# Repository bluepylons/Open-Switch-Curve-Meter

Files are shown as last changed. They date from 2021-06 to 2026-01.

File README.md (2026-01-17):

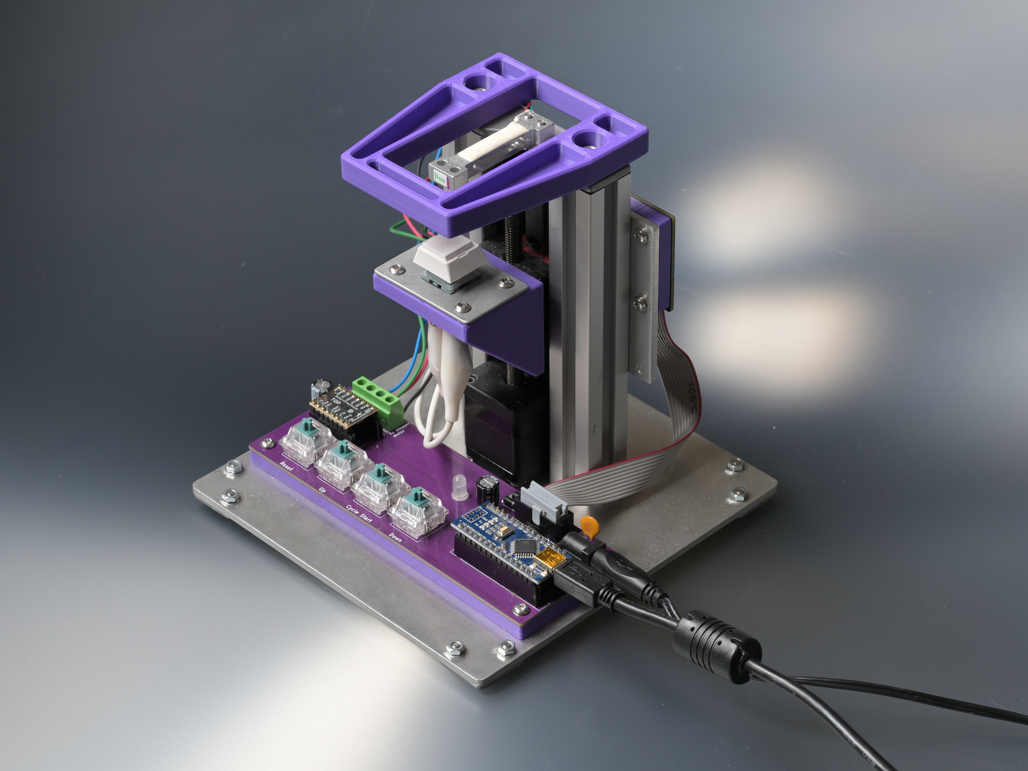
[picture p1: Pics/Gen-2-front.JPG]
Gen 2 Prototype


# About 
This is an open-source, low-cost measurement device for generating force curve measurements for MX-style switches. There are two versions - a much older Gen 1 and a newer Gen 2 design.  Force curves of various switches I've measured are in the Force curve measurements\ directory. Detailed documentation for Gen 2 is in progress and will be available [here](https://github.com/bluepylons/Open-Switch-Curve-Meter/blob/main/Gen%202%20Design/README.md).

This was designed specifically for MX switches to simplify the design and make everything cheaper and more compact, and since most of the switches I am curious about (as well as almost all new switches released today) use the MX form factor. With different switch holders it can hold other discrete switches - it was used to measure a Futaba switch, and could theoretically be used to measure Alps and other discrete swithces as well. This is not as versatile as force-curve testers built around a test stand (like [the one Haata built](https://deskthority.net/viewtopic.php?t=15133)) and can't test arbitrary keyboards like that one, but it's much cheaper to build (I spent about $200 building this, and in theory this is buildable for ~$100 if one foregoes the custom PCB and order the parts from China).

This project is licensed under the CERN OHL-S (strongly reciprocal) license for the hardware designs and the software. This is a share-alike license, and if you modify the project files you are required to also open-source your modifications. 

The force curve graphs themselves - the .ODS spreadsheets and the .PNG images of the graphs in the Force curve measurements\ folder - are licensed under [Creative Commons CC-BY 4.0](https://creativecommons.org/licenses/by/4.0/deed.en). 

# The key parts
* A linear stage. I designed around [this inexpensive $55 linear stage off Amazon](https://www.amazon.com/Sliding-Precision-Stepper-T-Shaped-Electric/dp/B07QBCG9YC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). You can find what appear to be identical units [on Aliexpress](https://www.aliexpress.com/item/4001272086575.html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,searchweb201602_,searchweb201603_) and elsewhere for less (if you get them from Aliexpress, make sure you buy the model with 1mm pitch (lead) on the leadscrew). Gen 2 will use the same linear stage. 
* A stepper motor. The stepper motor serves two purposes - it moves the linear stage, and also keeps track of position to plot the X-axis of the force curve. Stepper motors, as long as they aren't stalled or skip steps, move a given amount based on the number of step commands sent, and lets me forego having to directly measure position. Instead, I can just count the number of steps sent to the stepper motor, since I know how much the stepper motor will move for a given number of steps. I used the included stepper motor in the linear stage above, which moves 1.8° per step (200 steps per full rotation). Combined with the 1mm lead leadscrew on the linear stage, a single step (without microstepping) moves the switch 0.005mm. 
* A stepper motor driver. I used a Trinamic TMC2209 on Gen 1, and a Trinamic TMC2208 module on Gen 2. Communication occurs using rudimentary STEP/DIR control.  
* A load cell, to measure the force on the switch. I used [this 500g load cell](https://www.sparkfun.com/products/14728) from Sparkfun. It can be found on Aliexpress for slightly less. 
* A load cell amplifier and  ADC for reading the load cell and converting the readinging into a digital signal that can be easily read by the microcontroller. I used Avia's HX711 on both Gen 1 and Gen 2 as [Sparkfun made a module for it](https://www.sparkfun.com/products/13879), and there is an Arduino library available for it. Gen 2 has provisions for SPI and I2C for potential future upgrades with faster and more expensive ADCs (e.g. Analog Devices AD7730).
* A microcontroller. I used an Arduino Nano clone on Gen 1 and Gen 2 as I had one lying around and it's straightforward to write code for. My initial plans for Gen 2 involved using [Adafruit's Feather RP2040](https://www.adafruit.com/product/4884), though I have not had time to learn its programming language yet so I decided to spin another PCB for an Arduino Nano. 
* Software to transfer the information over to a computer. Right now, I use an Arduino 1.8.19's serial monitor to transfer the information over from the Arduino Nano clone. It's copied into a .csv file using Notepad. Cleanup of the data can be done either manually in a spreadsheet program (I use LibreOffice Calc), or can be done using [a Python script I wrote up](https://github.com/bluepylons/Open-Switch-Curve-Meter/tree/main/Processing-Python-script). Plotting is currently done with Libreoffice Calc.

There is also an RGBLED for status indication, and MX switches (2 on Gen 1, 4 on Gen 2) for control. 

The CAD was done in Alibre Atom3D. STEP files are provided. 

Gen 1 and Gen 2 both have custom PCBs, designed in KiCAD and fabbed by JLCPCB. You will need KiCAD to open the files. In theory, a PCB is not necessary - you can build this on perfboard, as off-the-shelf HX711 modules are available from [Sparkfun](https://www.sparkfun.com/products/13879) and elsewhere, and you can steper motor drivers [on breadboard-friendly breakout board](https://www.digikey.com/en/products/detail/trinamic-motion-control-gmbh/TMC2209-SILENTSTEPSTICK/10232488). However, it makes things a lot neater. 

The HX711 is powered off the microcontroller's 5V supply. The stepper motor is powered off a separate external 12V power supply.

# To do list (Gen 2)

* Documentation
	* Just like, everything
	* I'll make a video of me operating the force curve meter at some pointed
	* Write a guide on how to build one of these using off-the-shelf HX711 load cell amplifier and stepper motor modules. The PCB was done mostly for my own convenience, and it's possible to do it using off-the-shelf modules and a breadboard, though it's somewhat messier wiring wise. 
	
* Hardware
	* (eventually) Design a 3D-printed case for the PCB so that it's not exposed

* Firmware
	* Gen 2's RGBLED does not changes states like I expect to at the end of the run, so I need to debug this
	* (eventually) Write a more user-friendly UI for processing the data (the current workflow, which involves a lot of spreadsheets and copy/pasting data from Arduino Serial Monitor for both calibration and measurement, is tedious)

* Possible long-term improvements:
	* Better hosting of graphs - possibly moving off Github
		* There's something slowly in the works with various other people that currently possess force curve meters, but it will be some time before it will be up
		* We'd want something more interactive such as Plotly (which no longer takes new uploads), and something that can allow for easy comparisons between switches (e.g. overlaying graphs)
	* Some way to correct for temperature-induced drift on the load cell or amp that isn't just calibrating frequently 
		* I'm fairly annoyed by how much the load cell readings drift with temperature (simply opening a window often forces me to recalibrate), and I am considering adding additional load cell modules solely to do temperature correction (you can cancel out the temperature-dependent terms in the load cell equation if you use multiple identical load cells)/strain gauges, or doing temperature measurements and using a look up table to apply corrections or something. 
	* Possibly move away from the HX711	
		* There's a lot of sample variation among HX711's I've encountered, with some having a lot of drift and others mostly working fine. 
	
# Gen 1 Errata
* I mistakenly connected Pin 1 and Pin 2 on the Arduino on the PCB - those are the TX/RX lines, and I learned that having those connected interferes with communications between the Arduino and your computer,  and may lead to failures when uploading sketches and trying to use Serial Monitor. These lines were originally intended for uART communication with the TMC2209, but I decided to just use DIR/STEP control as it's easier to write the code. Either cut the headers off the Arduino, or do not install those pins on the socket on the PCB. 

# Thanks yous: 
* The Switchmodder [subreddit](https://www.reddit.com/r/switchmodders/) and [Discord](https://discord.gg/xnSUeETRTf)
* Nebulant and xyz for advice
* Romly, for [posting photos of their tester](https://twitter.com/Romly/status/1358983963377688579)  
* Haata, for his [incredibly useful writeup](https://deskthority.net/viewtopic.php?t=15133) on building his switch tester. 
* Gondolindrim and the [Acheron Project](http://acheronproject.com/), as I use their hotswap PCB footprint and the 3D model of the MX switch. Their open-source projects have also been very helpful for me getting into keyboard design. 
* Thank you to the following people for sending me switches to make curves of:
	* Slowshi 
	* Window Dump
	* mfchill
	* Clark
	* Aiwanei 
	* ChromePcok
	* Deadeye 
	* [Rebult Keyboards](https://www.rebultkeyboards.com/)
	* [Dangkeebs](https://dangkeebs.com/)
	* [Moyu.studio](https://moyustudio.cn/)
	* [Adobau Labs](https://adobaulabs.com/)
	* [Prevail Key Co.](https://prevailkeyco.com/)
	* Mechanicalbionicle
	* Nick7790
	* [JLabs](https://jlabs.co/)
	* Laika
	* notdoctorq
	* [Switch Oddities](https://switchoddities.com/)
	
# Links to other people with force curve meter designs and data:

* Ruddy, who's affiliated with [GeekBoards.ru](https://geekboards.ru/), independently developed a similar force curve meter and open-sourced his design on Github [here](https://github.com/geekboards/switch-force-tester). His measurements are [here](https://github.com/geekboards/switch-force-tester/tree/main/python-app/results)

* HaaTa, who founded [Input Club](https://input.club/), and well known for his force curve measurements. His design is on Github [here](https://github.com/kiibohd/force) and described on Deskthority [here](https://deskthority.net/viewtopic.php?f=62&start=&t=15133), and results are on Plotly [here](https://chart-studio.plotly.com/~haata#/)

* Nebulant and ManOfInterests also possess force curve meters, though I am not aware of any centralized location they publish their measurements. You can find their graphs on their Instagrams, across various Discord servers, Twitter, and on Keebtalk. 

* Romly built a force curve meter over in Japan. [Details here](https://romly.com/blog/c99_jikunohakari/).

* Theremingoat has a force curve meter and now has a [massive respository](https://github.com/ThereminGoat/force-curves).

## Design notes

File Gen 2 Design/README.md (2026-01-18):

# Work In Progress

**Order parts at your own risk. These files are provided as-is, and I am not responsible for any losses, harm, or damage incurred by following this guide, by ordering parts, by using the files provided, by using the resultant parts or assembled devices, or from any mistakes or errors in the files, ordering guide, or resultant parts.**

# Gen 2 
Gen 2 Prototype
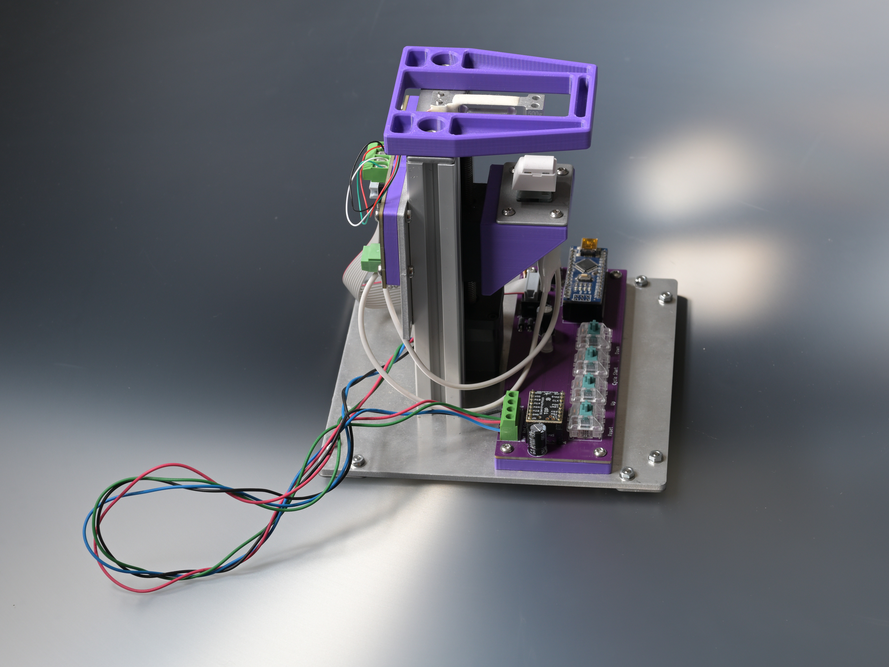
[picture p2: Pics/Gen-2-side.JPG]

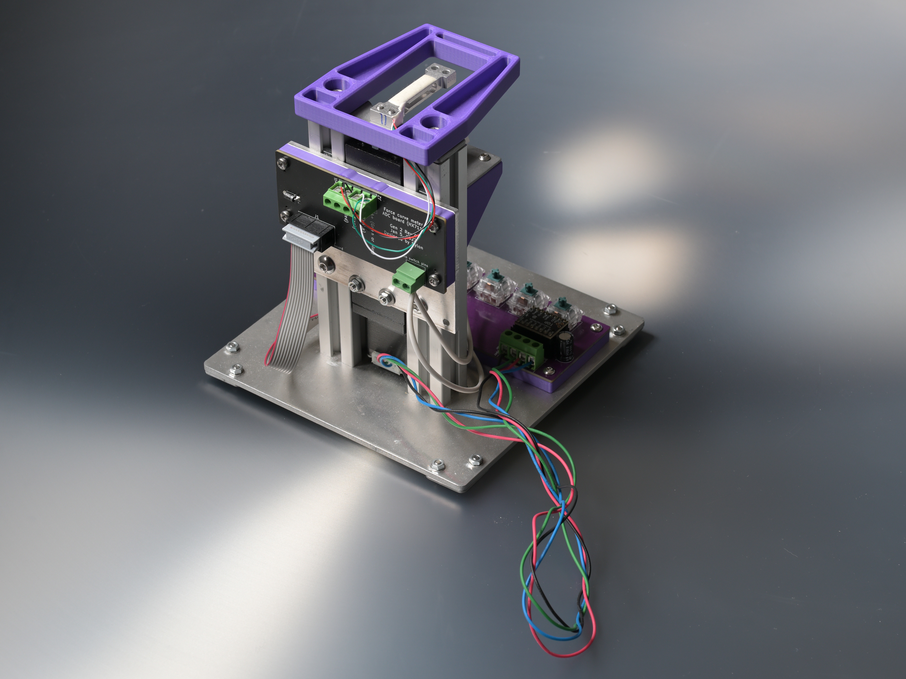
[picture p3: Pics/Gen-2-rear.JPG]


Due to the general jankiness of Gen 1, I decided to do a much neater redesign for Gen 2 back in 2021. I initially thought about [running a group buy](https://geekhack.org/index.php?topic=115453.0), though life has gotten in the way of that. I finally had some time to pick this project back up in late 2025, and am currently documenting the Gen 2 design to the point it can be easily replicated by other people. This document is very much a work in progress, though I have built and operated Gen 2. 

Mechanical CAD is done in [Alibre Atom3D](https://www.alibre.com/atom3d/), and the PCB files are done using KiCAD V9.

# ORDERING GUIDE

# Mechanicals

## Laser cut metal parts

The following parts are laser-cut out of metal. DXFs are provided [here](https://github.com/bluepylons/Open-Switch-Curve-Meter/tree/main/Gen%202%20Design/Mechanical%20files/Laser%20cut). STEP files are provided as well.

| Part name | Material thickness | Quantity |
| --- | --- | --- |
| Baseplate-stand | 3mm-3.2mm (0.118-125") | 1 |
| Bumpon-holder | 1.5mm-1.6mm (0.059-0.063") | 4 |
| Load-cell-mounting-plate | 3mm-3.2mm (0.118-125") | 1 |
| Switch-plate | 1.5mm-1.6mm (0.059-0.063") | 1 |
| Vertical plate | 3mm-3.2mm (0.118-0.125") | 1 |

Aluminum is generally recommended for most of the parts, though other metals (steel, brass, etc.) can work. For the baseplate stand, steel, brass, or stainless steel may be useful as the additional weight can provide more stability. All the parts on the ones I have built are cut out of aluminum 6061-T6.

Aluminum or plain steel are usually the cheapest materials. Note that steel may corrode or rust without treatment (e.g. painting, powder coating). 

In the US, I recommend [Sendcutsend](https://sendcutsend.com/). In the EU, [Laserboost](https://www.laserboost.com/) is a good source. 

For Sendcutsend, deburring is recommended, though it still tends to leave a sharp edge and may require manual deburring afterwards (with a deburring tool such as [this](https://www.mcmaster.com/4289A71/)). [Tumbling](https://sendcutsend.com/services/tumbling/) is recommended for eligible parts as it softens the edges.

## T-slotted extrusions and hardware 

I use Misumi 80/20-style extrusions, though tther brands of 20mm 80/20-style T-slotted extrusions likely work. The extrusions are tapped M5x0.8 on each end (Misumi will do this for you; the part number specifies it). However, if you have the tools you can tap it yourself to save money; you can order HFS5-2020-132 if you want to tap it yourself.

Note that nuts for other 2020 (such as McMaster or actual 80/20(R) hardware) are often incompatible as the slot opening on Misumi extrusions is a bit smaller. Be aware of this if ordering fasteners. 

| Misumi Part Number | Description | Quantity |
| --- | --- | --- |
| HFS5-2020-132-TPW | Extrusion | 2 |
| HNTAP5-5 | M5 nuts | 4 |

## 3D-printed pieces
The following parts are 3D-printed. STLs are available [here](https://github.com/bluepylons/Open-Switch-Curve-Meter/tree/main/Gen%202%20Design/Mechanical%20files/3DP).

| Part name | Quantity |
| ---  | --- |
| Switch mounting bracket | 1 |
| load-cell protection bracket | 1 |
| ADC-PCB-spacer | 1 |
| Main-PCB-spacer | 1 |

I have generally printed these out of PETG with a 0.2mm layer height, though other materials such as ABS and PLA are likely fine. 

## Linear actuator 

The design uses a cheap Chinese 50mm linear actuator with a 1mm pitch leadscrew. There's no exact part number for this. I ordered [this one](https://www.amazon.com/Sliding-Precision-Stepper-T-Shaped-Electric/dp/B07QBCG9YC/ref=sr_1_5?th=1) off Amazon; it is no longer available. [This](https://www.amazon.com/Linear-Actuator-Stepper-Milling-Machine/dp/B07K7FWDZJ/ref=sr_1_8?th=1) likely works as a substitute, though the counterbored mounting hole positions for the overall unit is slightly different (55mm instead of 56mm), though I have slotted the mounting holes on Vertical plate to accommodate 54-56mm. 

## Hardware

The following fasteners are needed:

| Description | Quantity | McMaster-Carr part number | Notes | 
| --- | --- | --- | --- |
| M3x5 ISO 14583 Torx 10 screw | 16 | 90362A112 | ISO 7380 button-head (McMaster 90991A111) would also work | 
| M3x8 screw (ISO 7380 Torx T10 used) | 4 | 90991A111 | Pretty much any head type works as a substitute |
| M3x10 ISO 7380 Torx T10 screw | 12 | 90991A111 | |
| M3x10 ISO 4762 socket head cap screw | 6 | 91292A113 | | 
| M3 DIN 125 washer | 16 | 91292A113 | |
| M3 DIN 934 zinc-plated hex nut | 16 | 91292A113 | Zinc-plated instead of stainless to prevent galling |
| M3x6 4.5-4.8mm hex Female-Female standoff | 8 | 95947A002 | Cheaper on Digi-key |
| M5x8 ISO 7380 hex socket screw | 4 | 94500A230 | McMaster 92095A207	also works but larger package size |  
| M5x12 ISO 7380 hex socket screw | 4 | 92095A210 | Longer lengths (up to 16mm) would also work | 

The following other hardware are needed:

| Description | Quantity | Notes | 
| --- | --- | --- |
| 3M SJ-5003 bumpons (or equivalent) | 4 | Available in different colors |

# PCB 

There are two PCBs, the ADC board and the Main board. The ADC board has SMT components that JLCPCB can place, while the Main board is through hole. While the project was originally going to use an Adafruit Feather RP2040 for the controller, I later switched back to using an Arduino Nano clone so I could re-use the code from Gen 1. 

The PCB can be ordered off JLCPCB using the manufacturing files provided here.

## ADC board

The following additional through-hole parts are needed:

| Reference designators | Part description | Manufacturer | Part number | Quantity | Notes | 
| ---  | --- | --- | --- | --- | --- |
| J1 | 10-pin shrouded connector | CNC Tech | 3020-10-0100-00 | 1 | | 
| J2 | 4-pin terminal block | Würth | 691137710004 | 1 | |
| J3 | 2-pin terminal block | Würth | 691137710002 | 1 | |

D2 can be left unpopulated if D1 is populated,  but Littelfuse P4KE6.8A can be used if not (if JLCPCB is out of stock of D1, for instance)

HX711 pitfalls

## Main board

The main board can be ordered as a bare PCB, which has additional through-hole parts that need to be soldered or installed on. These parts can be sourced from Digikey, Mouser, or your electronic parts distributor of choice.

| Reference designators | Part description | Manufacturer | Part number | Quantity | Notes | 
| ---  | --- | --- | --- | --- | --- |
| A2 | 2.54mm 15-pin female socket | Sullins | PPPC151LFBN-RC  | 2 | You can also cut down a longer socket |
| A2 | Arduino Nano or clone | Arduino | Nano | 1 | Do not use the Arduino Nano Every or ESP32 versions | 
| C1, C3 | 100uF 63V capacitor | Nichicon | UVY1J101MPD1TD2 | 2 | 63V rating is overkill, but I had some lying around |
| D1, D3-D5 | 5.8V TVS diode DO-204AL | Littelfuse | P4KE6.8A | 4 | |
| F1 | 16V 2A polyfuse | Bel Fuse | 0ZRN0200FF1E | 1 | |
| J1 | 5.5x2.5mm barrel jack | Kycon | KLDX-0202-B | 1 | |
| J2 | 10-pin shrouded connector | CNC Tech | 3020-10-0100-00 | 1 | |
| J8 | 4-pin terminal block | Würth | 691137710004 | 1 | |
| LED1 | 5mm through-hole RGBLED | Adafruit | 1938 | 1 | |
| U2 | 2.54mm 8-pin female socket  | Würth | 61300811821 | 2 | You can also cut down a longer socket |
| U2 | TMC2208 SilentStepStick | Watterott | 20170003-002 | 1 | TMC2209 also works |
| SW1-SW4 | Cherry MX-compatible switch | Any | Your favorite | 4 | |

# Electrical parts

You will need the following electrical parts as well:

| Part description | Manufacturer | Part number | Quantity | Notes | 
| --- | --- | --- | --- | --- |
| 500gf TAL221 load cell | Sparkfun | 14728 | 1 | Can also be found on Aliexpress | 
| 10-pin ribbon cable | Assmann WSW  | H3CCH-1006G-ND  | 1 | |
| 12V 2A power supply 5.5x2.5mm barrel jack, center positivee  | EDATEC | ED-PSU1202-US | 1 | Easily substituted; I use the power supply for an external hard drive |
| Alligator clip cable | Adafruit | 1008 | 1 | Easily substituted |

# Other parts

A 100g calibration weight is used to calibrate the load cell. These can easily be bought off Amazon or other places for fairly little money.

# OPERATING PROCEDURE

## Software Needed
* [Arduino IDE](https://www.arduino.cc/en/software)
* Python 3 (Jupyter Notebook) - this can be installed via a package like the [Anaconda Distribution](https://www.anaconda.com/products/distribution) of Python 3
* Libreoffice Calc
* MS Paint

## Calibration

## Measurement

## Data processing
### Automated using Python
### Manual

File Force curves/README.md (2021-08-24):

Here are the force curves I have so far. This page is frequently updated. The force curves here (the PNG and .ods files) are licensed under the [Creative Commons 4.0 license](https://creativecommons.org/licenses/by/4.0/). 

If you don't know how to read a force curve, [ThereminGoat has a good intro article](https://www.theremingoat.com/blog/a-beginners-guide-to-force-curves). 

I am planning a reorganization of this page soon, as it is getting quite long now. Until then - Ctrl-F is probably the best way to navigate this.

# Stock Switches

AEBoards Naevy R1.5 (missing contact):
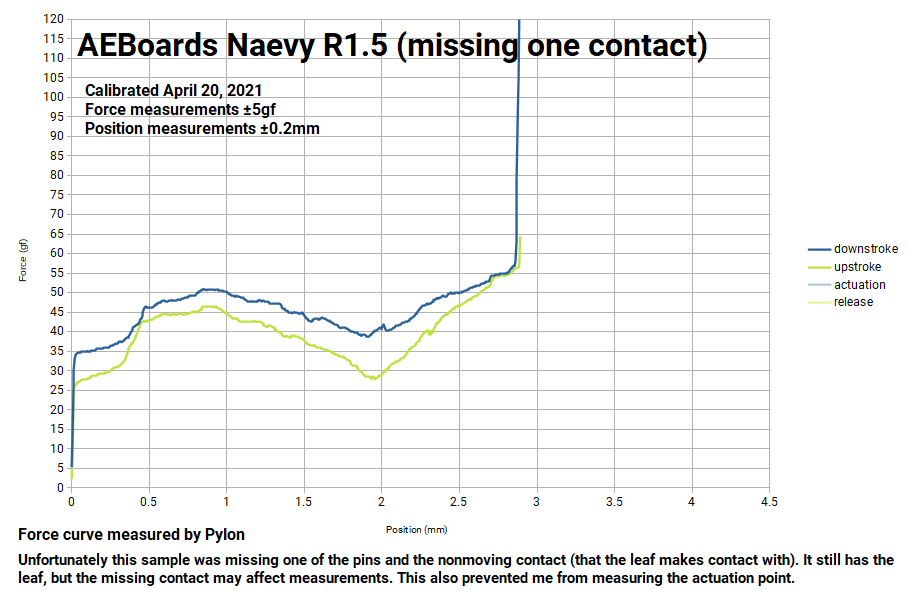
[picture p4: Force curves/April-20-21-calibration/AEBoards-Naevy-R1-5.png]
Naevy R1.5


Akko x KTT CS Ocean Blue:
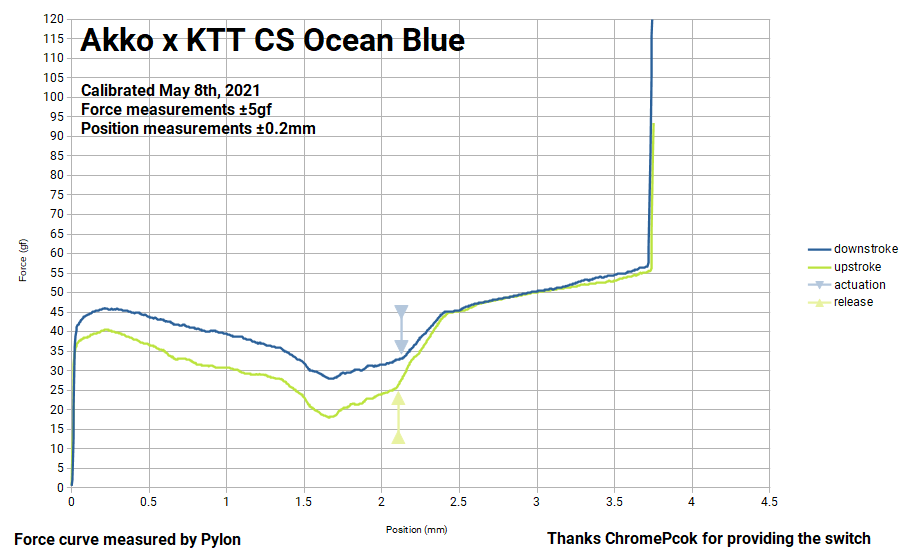
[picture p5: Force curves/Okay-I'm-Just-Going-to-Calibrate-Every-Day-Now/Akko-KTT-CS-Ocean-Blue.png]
Akko Ocean Blue


Alphakeys Dusk Panda:
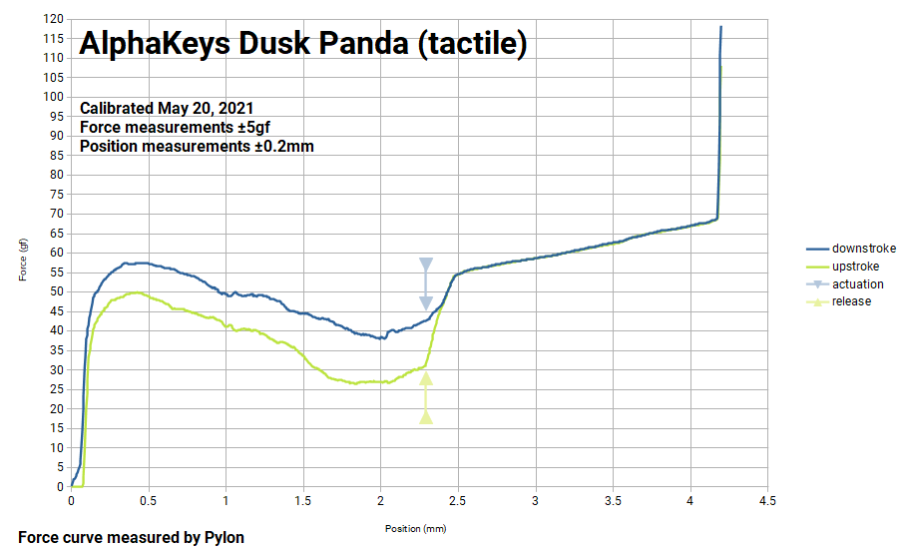
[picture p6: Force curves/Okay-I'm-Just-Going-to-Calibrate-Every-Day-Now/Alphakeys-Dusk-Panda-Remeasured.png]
Alphakeys Dusk Panda


C3 Equalz x JWK Kiwi:                             
Kiwi

Durock (JWK) Koala (T1) 67gf:
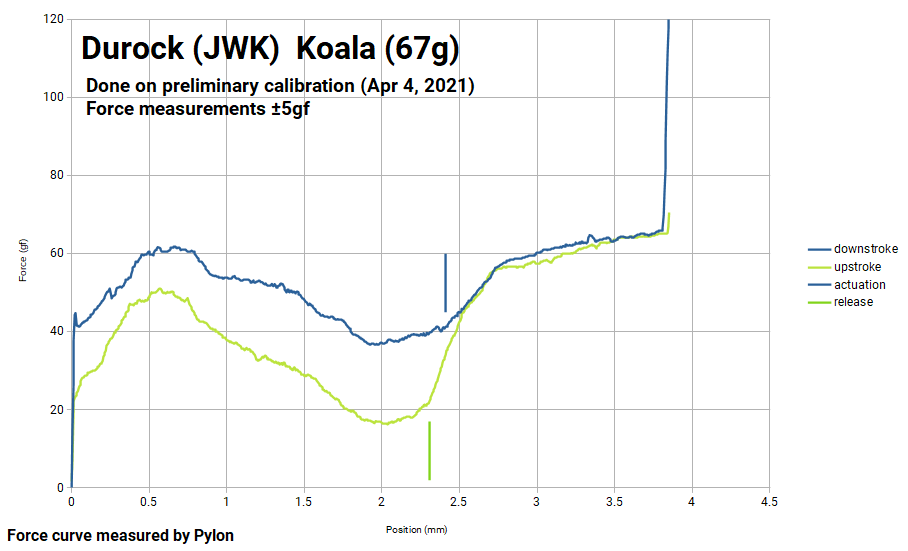
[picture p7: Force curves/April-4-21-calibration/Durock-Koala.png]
Durock Koala


Durock (JWK) Medium Tactile:
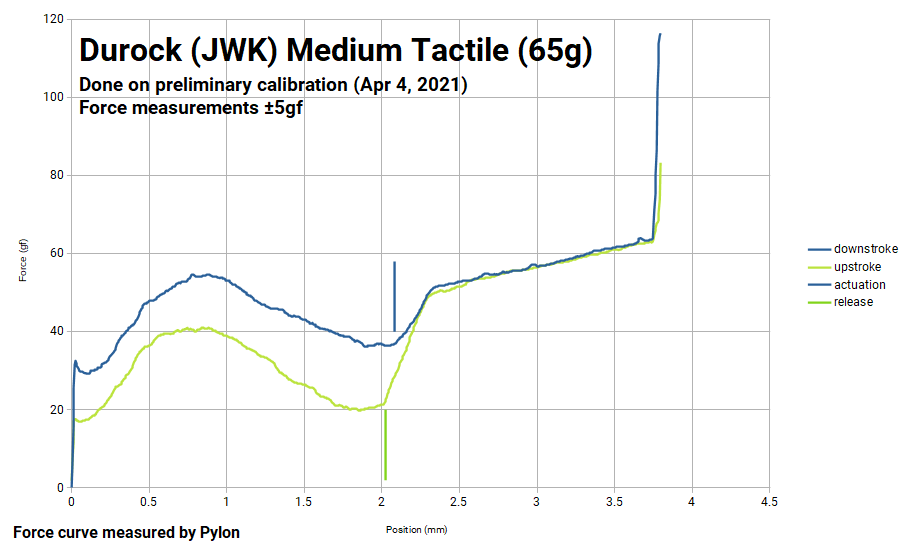
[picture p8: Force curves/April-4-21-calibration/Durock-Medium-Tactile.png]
Durock Medium Tactile


Durock (JWK) Shrimp (Silent T1):
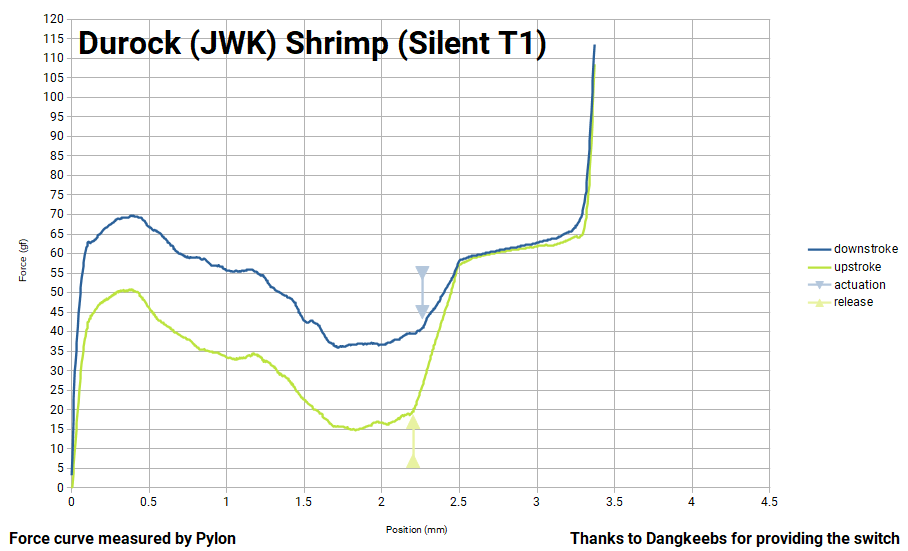
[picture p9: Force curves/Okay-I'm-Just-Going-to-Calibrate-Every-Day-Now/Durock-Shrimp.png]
Durock Shrimp


Durock (JWK) Sunflower (POM T1):
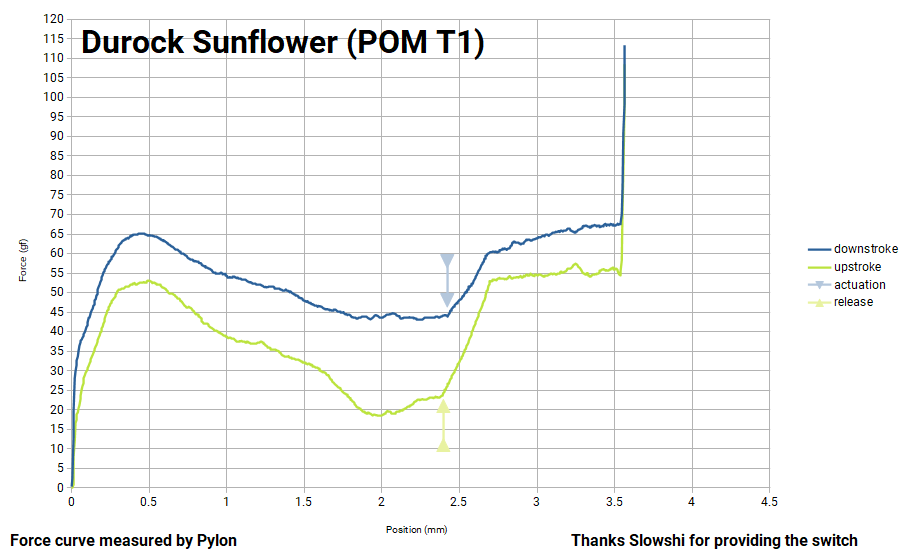
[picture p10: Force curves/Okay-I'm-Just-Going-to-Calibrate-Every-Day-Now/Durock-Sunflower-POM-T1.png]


Durock (JWK) T1:
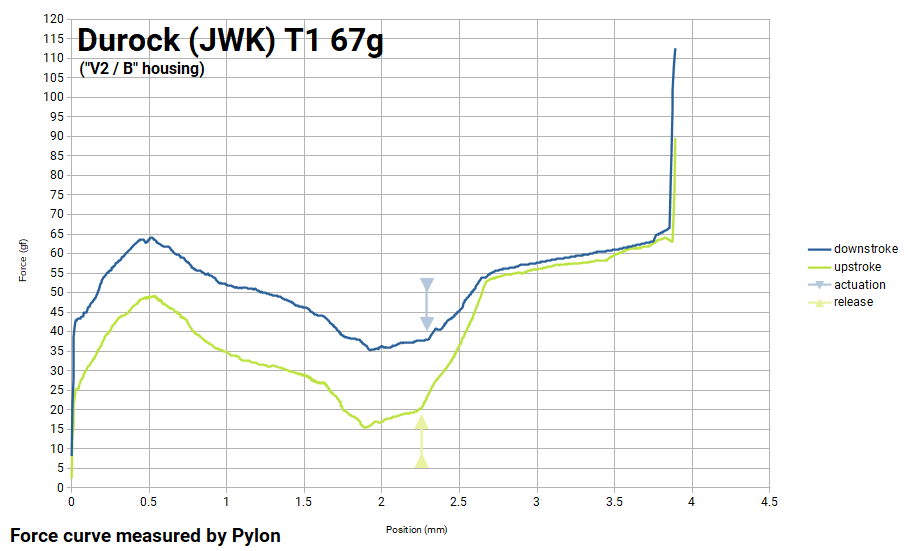
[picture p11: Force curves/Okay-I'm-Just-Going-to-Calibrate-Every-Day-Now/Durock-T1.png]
T1


Durock (JWK) T1 Dark Amber:
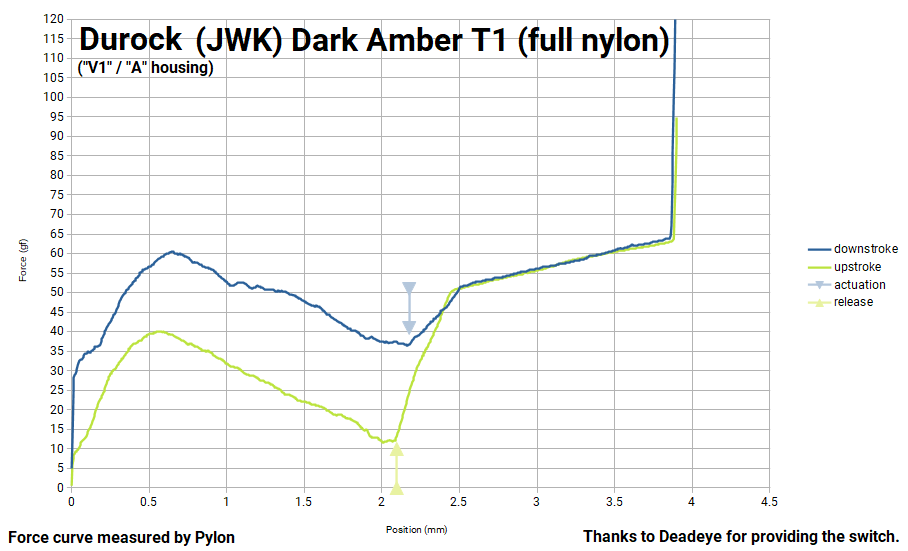
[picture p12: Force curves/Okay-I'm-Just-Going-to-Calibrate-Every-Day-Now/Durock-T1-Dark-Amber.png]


Gateron Aliaz:                        
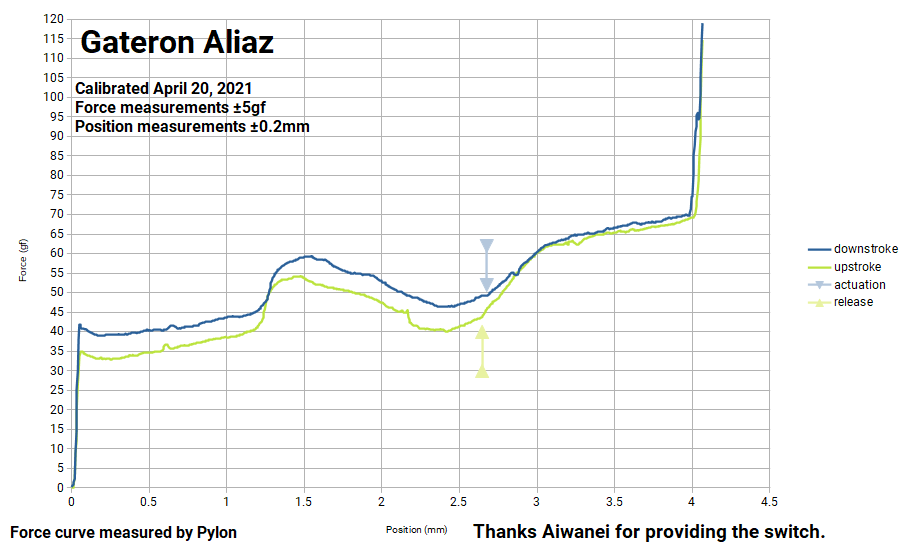
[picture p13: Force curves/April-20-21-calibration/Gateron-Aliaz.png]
Gateron Aliaz


Gateron Cap Yellow:                         
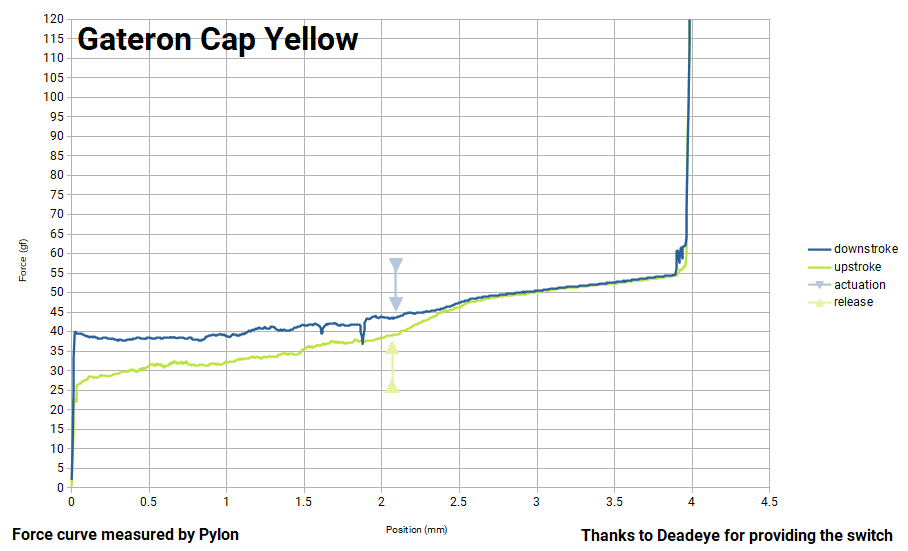
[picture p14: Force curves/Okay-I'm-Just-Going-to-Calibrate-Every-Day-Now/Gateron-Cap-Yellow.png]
Gateron Cap Yellow


Gateron Ink Yellow:
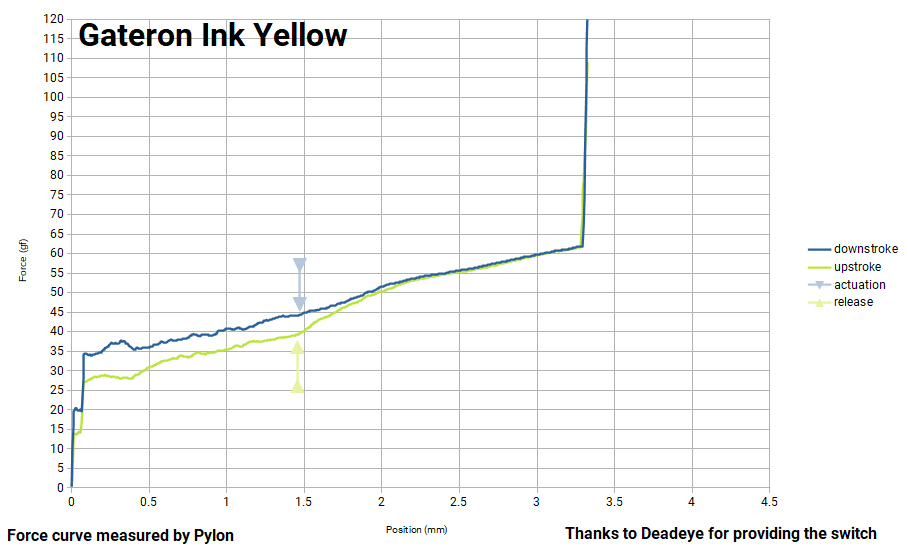
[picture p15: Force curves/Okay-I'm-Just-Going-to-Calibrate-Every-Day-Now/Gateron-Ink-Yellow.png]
Gateron Ink Yellow


Gateron Kangaroo:
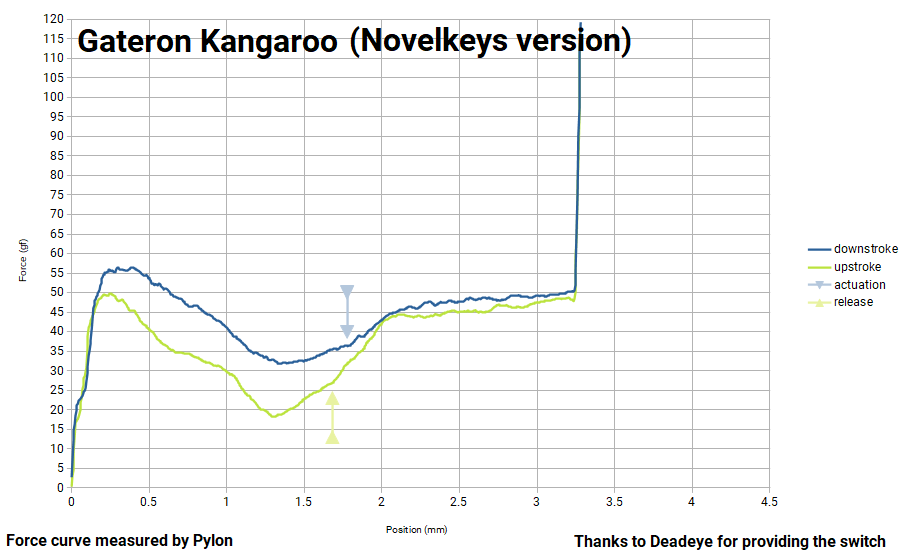
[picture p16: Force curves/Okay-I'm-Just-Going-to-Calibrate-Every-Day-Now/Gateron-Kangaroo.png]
Gateron Kangaroo
 

Gateron Limbo:
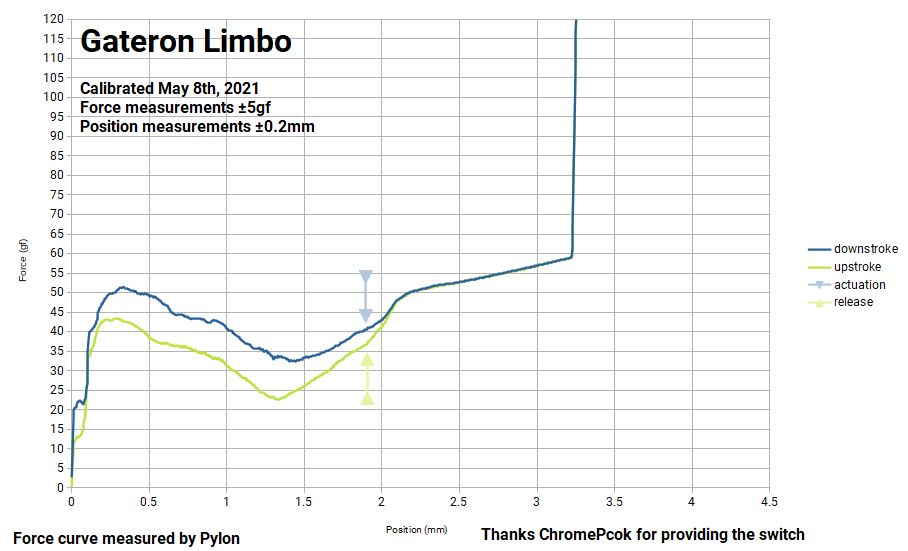
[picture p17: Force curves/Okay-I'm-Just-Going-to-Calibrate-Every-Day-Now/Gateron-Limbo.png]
Gateron Limbo


Gateron Silver Blizzard:
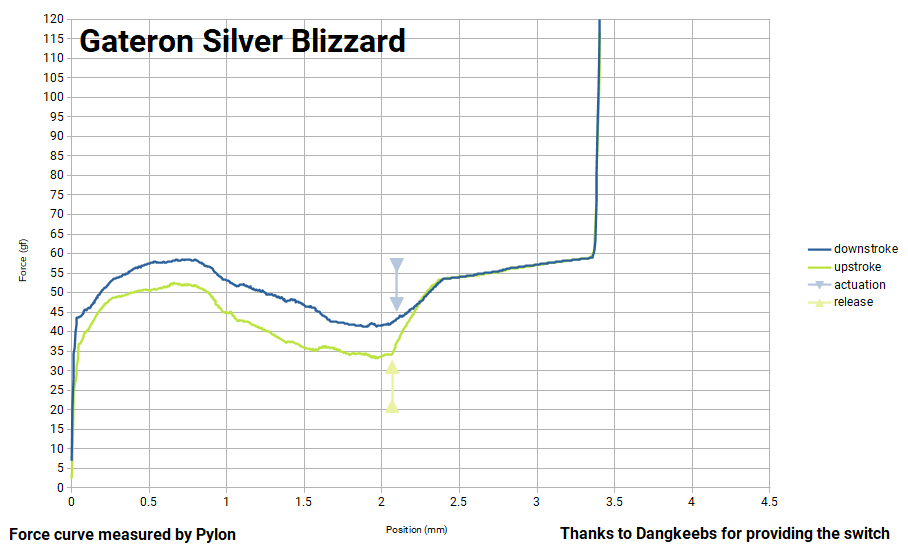
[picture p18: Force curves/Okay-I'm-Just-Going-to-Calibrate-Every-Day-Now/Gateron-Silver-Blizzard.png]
Gateron Silver Blizzard


Gateron Slate:                                     
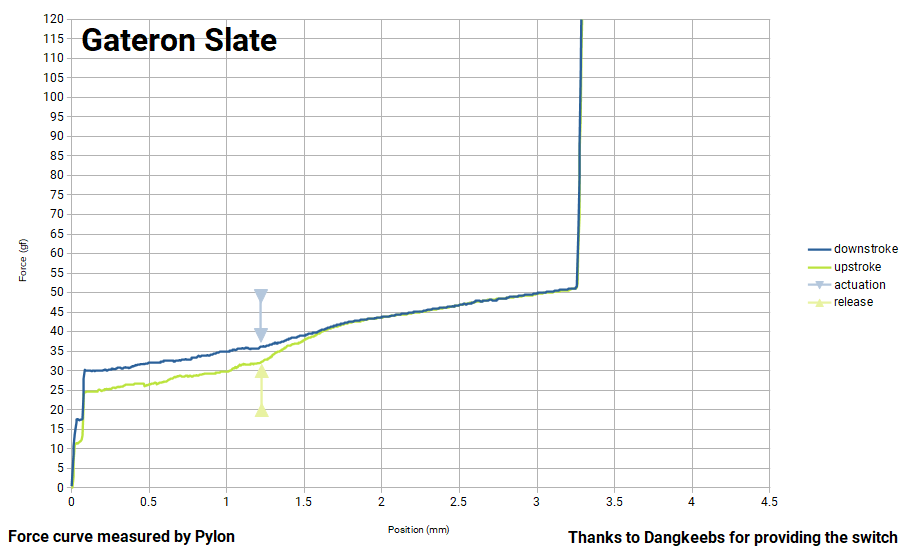
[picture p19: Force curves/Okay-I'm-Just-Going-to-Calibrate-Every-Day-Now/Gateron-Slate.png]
Gateron Silver Blizzard


Gazzew x Outemu Boba U4 68gf:
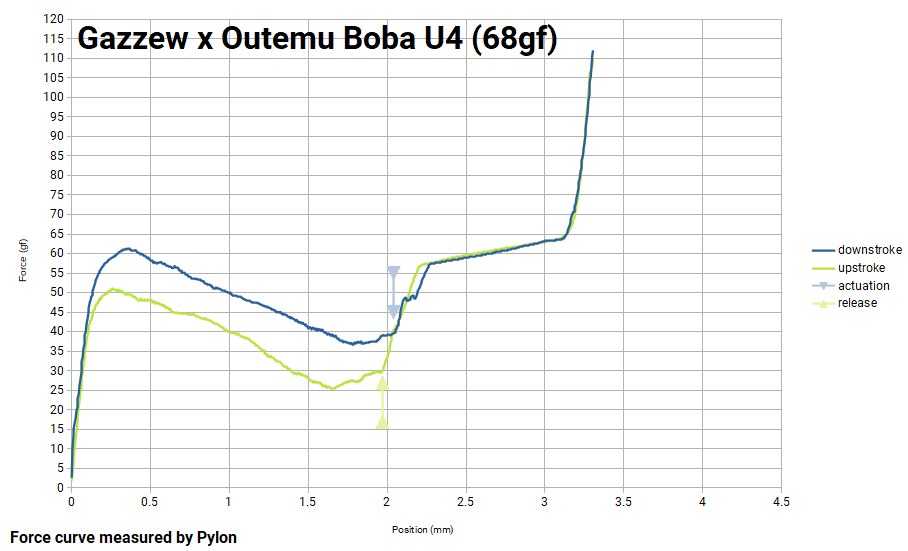
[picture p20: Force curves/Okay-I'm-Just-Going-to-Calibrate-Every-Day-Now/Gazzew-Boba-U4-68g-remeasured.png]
Gazzew Boba U4 68g


Gazzew x Outemu Boba U4 Thock (U4T) 62gf:
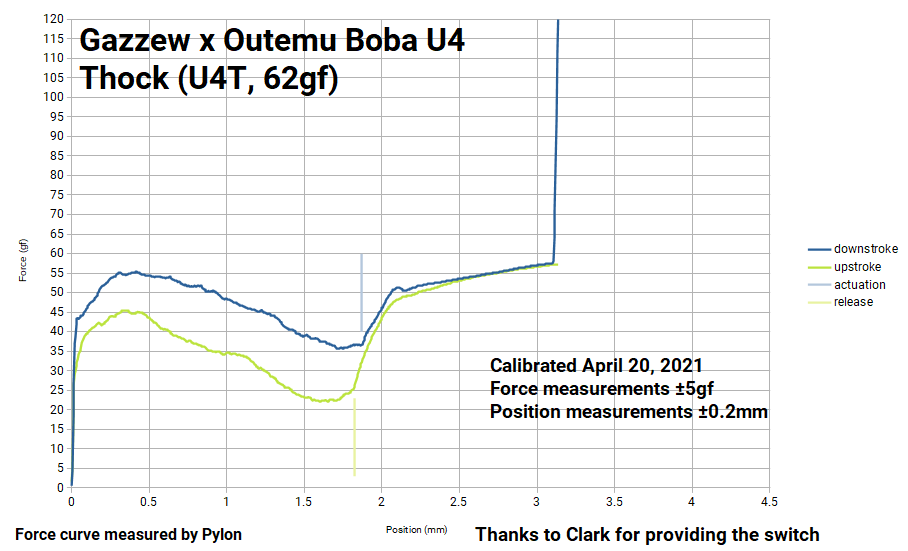
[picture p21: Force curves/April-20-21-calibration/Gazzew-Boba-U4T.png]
Gazzew Boba U4 62g


Gazzew x Outemu Boba U4 vs U4 Thock (U4T) 68gf:
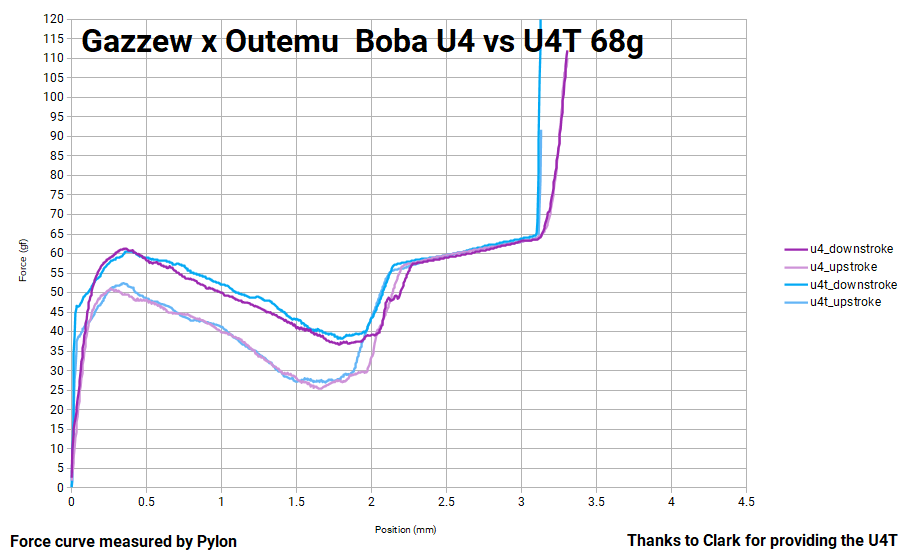
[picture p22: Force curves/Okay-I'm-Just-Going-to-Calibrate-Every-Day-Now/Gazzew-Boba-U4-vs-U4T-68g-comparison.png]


Gazzew x Outemu Bobagum 52gf:
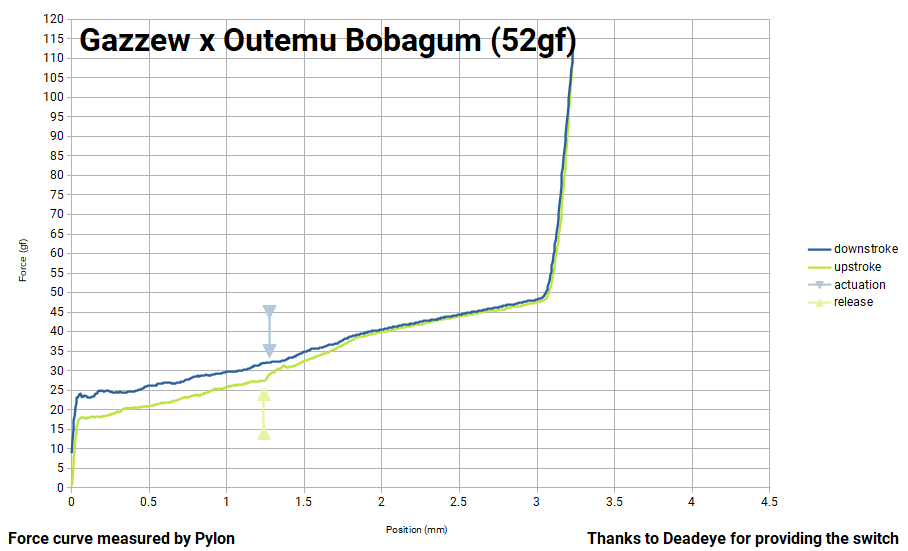
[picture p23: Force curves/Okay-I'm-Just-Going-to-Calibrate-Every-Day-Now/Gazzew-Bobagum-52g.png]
Gazzew Bobagum


Gazzew x Outemu Phoenix Stem in Boba housing:
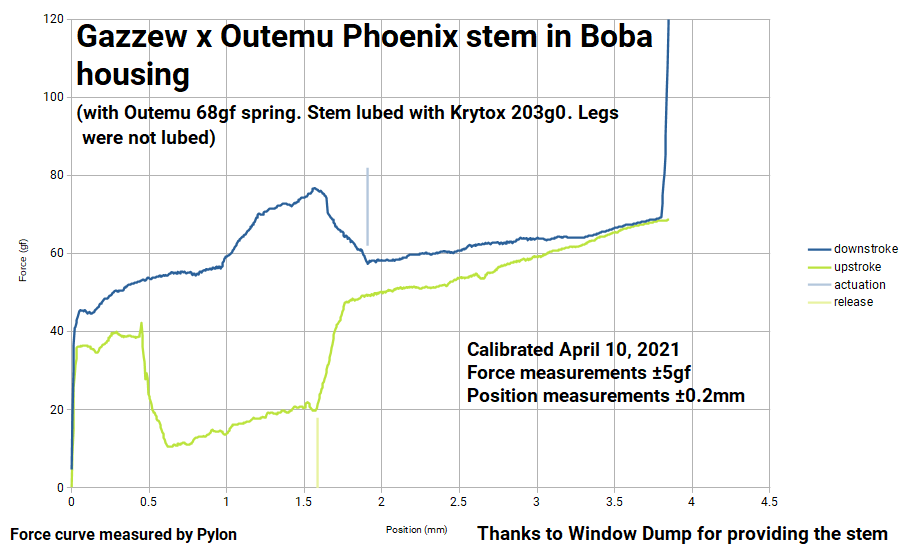
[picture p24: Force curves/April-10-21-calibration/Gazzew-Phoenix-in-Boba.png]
Gazzew Phoenix Stem in Boba


Gazzew x Outemu Silent Tactile - Silent Sky V2.2 stem in Gazzew/Outemu Boba Housing:
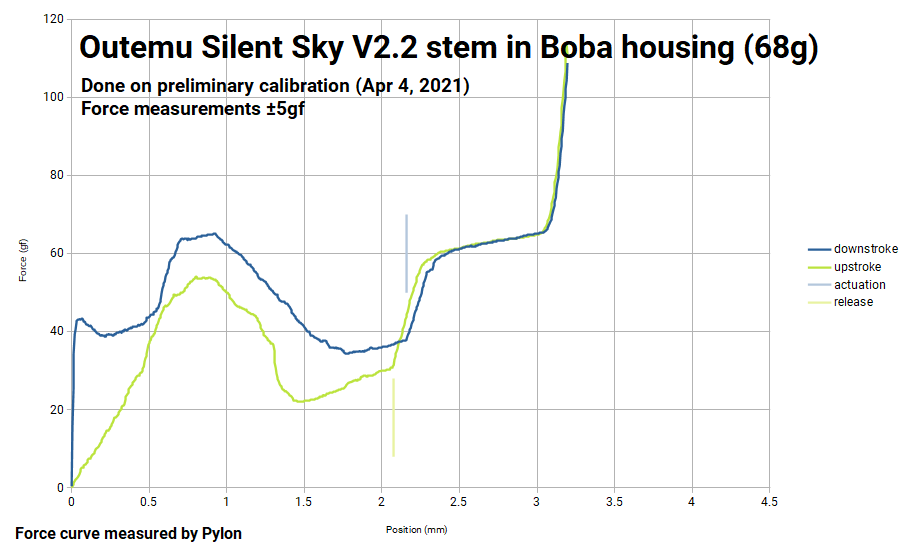
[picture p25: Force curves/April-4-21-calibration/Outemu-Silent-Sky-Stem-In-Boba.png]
Outemu Silent Sky Stem in Boba Housing


*(I was split as to whether this was a franken, but it is a combo that is buildable out of parts that Gazzew sells, and isn't sold as a complete switch)*

Huano x Old Tom Holy Tom:
Holy Tom

JWK Alpaca "V2":
JWK Alpaca "V2"

JWK Pewter:        
JWK Peter

(Proposed) JWK Twilight:
JWK Twilight

JWK Twilight (lubed, as sold by Moyu.studio)

Kail Box Silent Brown:
Box Silent Brown

Kailh Polia:                      
Kailh Polia

Kailh Speed Pale Blue:
Kailh Speed Pale Blue

KTT Gold:                            
KTT Gold

KTT Matcha:                                                   
KTT Matcha

KTT Strawberry:
KTT Strawberry

Momoka Frog:              
Momoka Frog    

Moyu.studio x JWK Black (Everglide Dark Jade):
Everglide Dark Jade        
*Note - these measured significantly differently than advertised on Drop, with significantly less travel (3.2mm vs 4mm advertised)

Moyu.studio x JWK Poseidon:
Moyu Queen 

Moyu.studio x JWK Queen:
Moyu Queen 

Novelkeys x Kailh Blueberry:
NK Blueberry

Novelkeys x Kailh Box Cream:
Box Cream 

Novelkeys x Kailh Box Navy:
Kailh Box Navy

Novelkeys x Kailh Sherbet:
NK Sherbet

Novelkeys x Kailh Speed Navy:
Kailh Speed Navy

Outemu Ice Purple 62gf:
Outemu Ice Purple

Outemu Silent Sky V2.2 68gf:
Outemu Silent Sky

Rebult x JWK Harimau:
Rebult Harimau

Rebult x JWK Penyu:
Rebult Penyu

SP Star x Kon MOMO: 
SP Star Kon Momo

SP Star Meteor Orange:
SP Star Meteor Orange

SP Star Purple:
SP Star Purple

Tecsee Blue Velvet Tactile:
Tecsee Blue Velvet Tactile

Tecsee Kingfisher:
Tecsee Kingfisher

Tecsee Lychee:
Tecsee Lychee

Tecsee Porcelain Blue 53gf:
Tecsee Porcelain Blue

Tecsee Ruby V1:
Tecsee Ruby V1

Tecsee Sapphire V1:
Tecsee Sapphire v1

TTC Bluish White:
TTC Bluish White

TTC Gold Brown:
TTC Gold Brown

TTC Gold Pink:
TTC Gold Pink

TTC Golden Blue:
TTC Golden Blue

TTC Watermelon Milkshake:
TTC Watermelon Milkshake

Velocifire x KK Lightwave V2:
KK Lightwave V2         
*(I initially thought my sample had a bent leaf as these actuate much earlier than at the 2.0mm advertised, but there are [other reports](https://www.youtube.com/watch?v=oTu_R-ibhw4) of these switches actuating much earlier than specified.*

Zeal x Gateron Zealio V2 65g:
Zeal v2 65g

# Frankenswitches 

Cherry MX Blue stem in Durock Koala (T1) housing:
Cherry MX Blue stem in Koala housing

Cherry MX Brown stem in Gazzew/Outemu Boba  housing: 
Cherry MX Brown stem in Boba housing

Cherry MX Clear stem in Cherry MX Blue housing:
Cherry MX Blue stem in Cherry MX Blue housing

Cherry MX Clear stem in various housings:
Cherry MX Clear stems in various housings

Durock (JWK) Cobalt stem in Durock POM linear housing:
Cobalt stem in POM linear housing

Durock (JWK) T1 stem in Durock (JWK) Medium Tactile housing:
Durock T1 stem in Durock Medium Tactile housing

Durock (JWK) T1 stem in Kailh Pro Purple housing:
Durock (JWK) T1 stem in Kailh Pro Purple housing

Durock (JWK) T1 stem and top in Rebult Harimau bottom housing:
T1 stem in Harimau

Feker Holy Panda stem (Halo clone) in Cherry MX Blue housing - "Holy Chickie" 
Holy Chickie

Feker Holy Panda stem (Halo clone) in Durock Koala (T1) housing - "Holy T1":
Feker Holy Panda stem (Halo clone) in Durock Koala (T1) housing - "Holy T1"

Feker Holy Panda stem (Halo clone) in Gazzew Boba housing - "Holy Boba" 
Holy Boba

Feker Holy Panda stem (Halo clone) in NK x Kailh Blueberry housing - sort of a "Paco" (technically supposed to use an NK x Kailh Cream housing, but the housings are supposedly identical)
Paco

Feker Holy Panda stem (Halo clone) in Zeal Zealio Bottom Housing, Gazzew Boba top - "Byko":
Byko

Feker Holy Panda stem (Halo clone) in Zeal Zealio Bottom Housing, Cherry top - variant of a "Zyko" I guess:
Sort of Zyko

Feker Smokey Tactile stem in Durock (JWK) T1 housing:
Sort of Holy T1

Gateron Blue (Jailhouse modded):
Jailhouse Gat Blue
Gazzew x Outemu Phoenix stem in Durock T1 housing:
Gazzew x Outemu Phoenix stem in Durock T1 housing

Gazzew x Outemu Phoenix in Outemu Sky housing:
Gazzew Phoenix Stem in Outemu SKy housing

Gazzew U4 stem in Cherry MX Blue housing:
Gazzew U4 stem in Cherry MX Blue housing

Gazzew U4 stem in Cherry MX Clear housing:
Gazzew U4 stem in Cherry MX Clear housing

Gazzew U4T stem, Kailh Polia stem, and Input Club x Kailh Halo Clear stem, in Boba housing:
Various stems in Boba)

Input Club Halo Clear stem in Gazzew Boba housing - "Holy Boba"
Holy Boba

Kailh Polia stem in Zealio V2 bottom, Cherry top, 65gf Zealio V2 spring - "Zyko" variant:
Polia stem in Zealio V2 bottom, Cherry top

Kailh Pro Burgundy stem in Gateron KS-3 bottom, Gazzew Boba top - "Deadpool":
Kailh Pro Burgundy stem in Gateron KS-3 bottom, Gazzew Boba top

Kailh Pro Purple stem in Durock T1 housing:
Kailh Pro Purple stem in Durock T1 housing

Kailh Pro Purple stem in Durock T1 bottom housing, Cherry top housing:
Kailh Pro Purple stem in Durock T1 bottom housing, Cherry top housing

Kailh Pro Purple stem in Durock T1 bottom housing, Gateron Milky top housing:
Kailh Pro Purple stem in Durock T1 bottom housing, Gateron Milky top housing

Kailh Pro Purple stem in Durock T1 bottom housing, older Gazzew Boba top housing:
Kailh Pro Purple stem in Durock T1 bottom housing, older Gazzew Boba top housing

Kailh Pro Purple stem in Durock T1 bottom housing, Outemu Clear no-slot (tight) top housing:
Kailh Pro Purple stem in Durock T1 bottom housing, Outemu Clear no-slot (tight) top housing

Kailh Pro Purple stem in Durock T1 bottom housing, Outemu Clear slotted top housing:
Kailh Pro Purple stem in Durock T1 bottom housing, Outemu Clear slotted top housing

Kailh Speed Pale Blue stem in Novelkeys x Kailh Sherbet housing:
Kailh Speed Pale Blue stem in NK Sherbet

Novelkeys x Kailh Blueberry stem in Gazzew x Outemu Boba housing, Cherry MX Grey 110g spring:
Blueberry Stem in Boba

Novelkeys x Kailh Blueberry stem in Outemu Sky housing, Gazzew x Outemu Boba top:
Blueberry in Sky

Novelkeys x Kailh Blueberry stem in Tecsee Lychee housing:
Blueberry in Lychee

Novelkeys x Kailh Cream stem in JWK Alpaca "V2" housing:
NK Cream stem in Alpaca

Outemu Purple (Dustproof) Stem in Boba Housing :
Outemu Purple (Dustproof) Stem in Boba Housing

Outemu Silent Sky V2.2 stem in Cherry MX Blue housing:
Outemu Silent Sky V2.2 stem in Cherry MX Blue housing

Outemu Silent Sky V2.2 stem in Cherry MX Clear housing:
Outemu Silent Sky V2.2 stem in Cherry MX Clear housing

Outemu Silent Sky V2.2 stem in Durock (JWK) T1 housing:
Outemu Silent Sky V2.2 stem in Durock T1

Tecsee Blue velvet Linear stem in JWK Lavender Linear housing:
Blue Velvet Linear in Lavender

Tecsee Blue Velvet Linear stem in HK Gaming MS1 top, Mode x JWK Signal bottom:
This combo name is too long but also don't name your frankenswitches because no one wiill know what it is  

TG3 "Copre" rubber dome over springless Gateron Yellow:
Copre Gat Yellow

TG3 "Copre" rubber dome over NK Blueberry Stem in Gazzew Boba housing:
This is nuts

TG3 "Copre" rubber dome over springless Kailh Box Navy:
Copre Box Navy

# Springs

KTT Kang White spring:
KTT Kang White spring

New Gazzew 55gf, 65gf, and 72gf springs:
Redacted progressive spring 

Redacted progressive spring (this was sent to me but is not publicly released yet, hence details are redacted):
Redacted progressive spring 

SPRiT 63.5gf Complex and Progressive Springs, compared with Gateron Yellow Spring, no leaf:
SPRiT 63.5g Complex and Progressive Springs, compared with Gateron Yellow Spring, no leaf

SPRiT 63.5gf Complex and Progressive Springs, compared with Gateron Yellow Spring, with leaf:
SPRiT 63.5g Complex and Progressive Springs, compared with Gateron Yellow Spring, with leaf

Tecsee Ruby V1 spring:
Tecsee Ruby V1 spring

Thic Thock 68gf MP, no leaf:
Thic Thock 68g MP, no leaf

Thic Thock 68gf MP, with leaf:
Thic Thock 68g MP, no leaf

Various ~63.5gf springs (Durock, Gateron Yellow, various SPRiT)
Various 63.5gf springs

Various 67-70gf springs (Moyu Black, Durock 67g, Thic Thock DL 67.5g, Thic Thock MP 68g, Outemu 68g, TX 70g 14mm)
Various 67-70gf springs

Various ~90gf springs:
Various ~90gf springs

Various very long springs:
Various very long springs

Various SPRiT springs:
Various SPRiT springs

# Other

Effects of the ["Paper Mod"](https://www.reddit.com/r/switchmodders/comments/iiigpx/leaf_mod_adjust_your_tactility_level_for_free/) on an Cherry MX Ergo Clear:
Paper Mod

Gateron Yellow with and without its leaf:
Gateron Yellow - with and without its leaf

Slow versus fast spring comparison - Cherry MX Clear with stock 90gf spring and with Kailh Speed Pale Blue spring:
Cherry MX Clear slow vs fast

# Other sources of force curve measurements 
* HaaTa has force curve measurements [on Plotly](https://chart-studio.plotly.com/~haata#/)
* Ruddy (of Geekboards.ru) has force curve measurements on Github [here](https://github.com/geekboards/switch-force-tester/tree/main/python-app/results)

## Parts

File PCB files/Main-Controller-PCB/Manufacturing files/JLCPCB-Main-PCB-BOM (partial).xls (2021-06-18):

Comment | Designator | Footprint | LCSC Part Number | Type
10uF | C1, C4 | 0805 | C15850 | Basic
100nF | C2, C5, C6, C8, C11, C12, C13 | 0805 | C49678 | Basic
4.7uF | C7 | 0805 | C1779 | Basic
22nF | C10 | 0805 | C1729 (https://lcsc.com/product-detail/Multilayer-Ceramic-Capacitors-MLCC-SMD-SMT_SAMSUNG_CL21B223KBANNNC_22nF-223-10-50V_C1729.html/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) | Basic
1N4148W | D2 | SOD-123 | C81598 | Basic
20k | R2, R3, R9, R11, R14, R15 | 0805 | C4328 (https://lcsc.com/product-detail/Chip-Resistor-Surface-Mount_Uniroyal-Elec-0805W8F2002T5E_C4328.html/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) | Basic
8.2k | R4 | 0805 | C17828 (https://lcsc.com/product-detail/Chip-Resistor-Surface-Mount_Uniroyal-Elec-0805W8F8201T5E_C17828.html/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) | Basic
100 | R1, R5, R6 | 0805 | C17408 (https://lcsc.com/product-detail/Chip-Resistor-Surface-Mount_Uniroyal-Elec-0805W8F1000T5E_C17408.html/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) | Basic
120 | R7 | 0805 | C17437 (https://lcsc.com/product-detail/Chip-Resistor-Surface-Mount_Uniroyal-Elec-0805W8F1200T5E_C17437.html/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) | Basic
10k | R8 | 0805 | C17414 (https://lcsc.com/product-detail/Chip-Resistor-Surface-Mount_Uniroyal-Elec-0805W8F1002T5E_C17414.html/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) | Basic
HX711 | U1 | SOP-16 | C43656 (https://lcsc.com/product-detail/Analog-To-Digital-Converters-ADCs_HX711_C43656.html/?href=jlc-SMT) | Extended
TMC2209 | U2 | QFN-28 | C465949 (https://lcsc.com/product-detail/Motor-Drivers_TRINAMIC-Motion-Control-GmbH-TMC2209-LA_C465949.html/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) | Extended

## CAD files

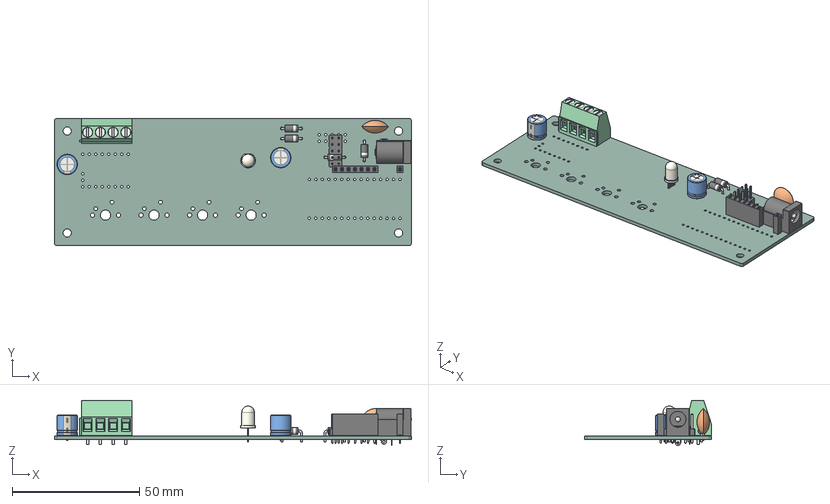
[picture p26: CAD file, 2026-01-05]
Gen 2 Design/Mechanical files/Atom3D CAD files/Main-PCB-ArduinoNano.step
140.1 x 50.0 x 17.7 mm
CP_Radial_D8.0mm_P3.50mm x 2
C_Disc_D10.5mm_W5.0mm_P5.00mm
PinSocket_1x01_P2.54mm_Vertical
TerminalBlock_Phoenix_MKDS-1,5-4_1x04_P5.00mm_Horizontal
BarrelJack_Horizontal
D_DO-41_SOD81_P7.62mm_Horizontal x 4
PinSocket_1x07_P2.54mm_Vertical
PinHeader_2x05_P2.54mm_Vertical
LED_D5.0mm-4_RGB
Main-board-ArduinoNano_PCB

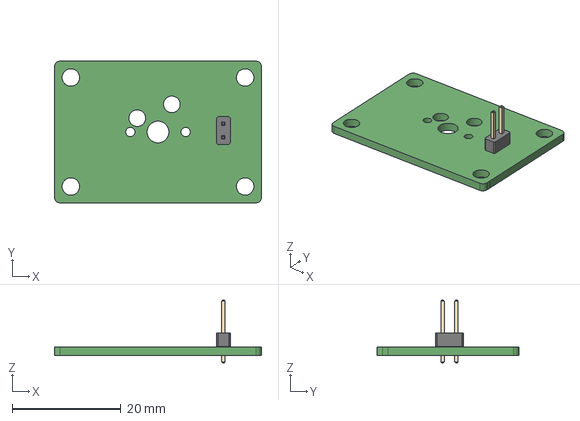
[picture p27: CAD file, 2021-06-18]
CAD (Atom3D)/Hotswap board/hotswap-board.step
38.0 x 26.0 x 11.5 mm

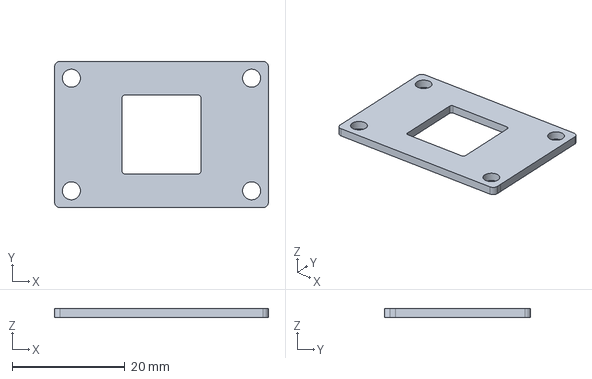
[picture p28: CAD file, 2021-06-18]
CAD (Atom3D)/plate.step
38.0 x 26.0 x 1.60 mm

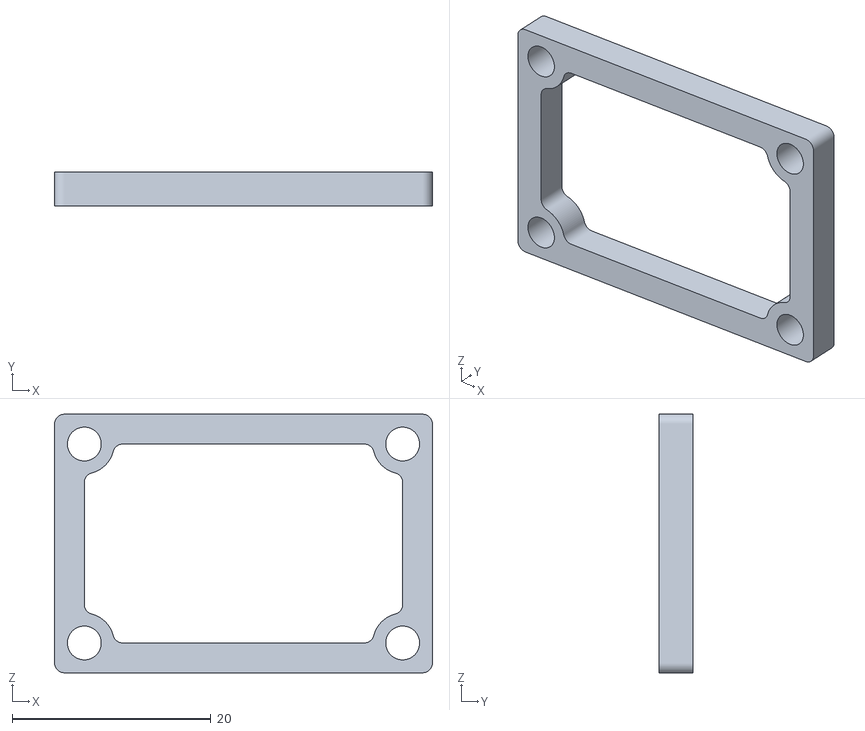
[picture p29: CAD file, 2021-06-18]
CAD (Atom3D)/STLs/spacer.stl
38.0 x 3.40 x 26.0

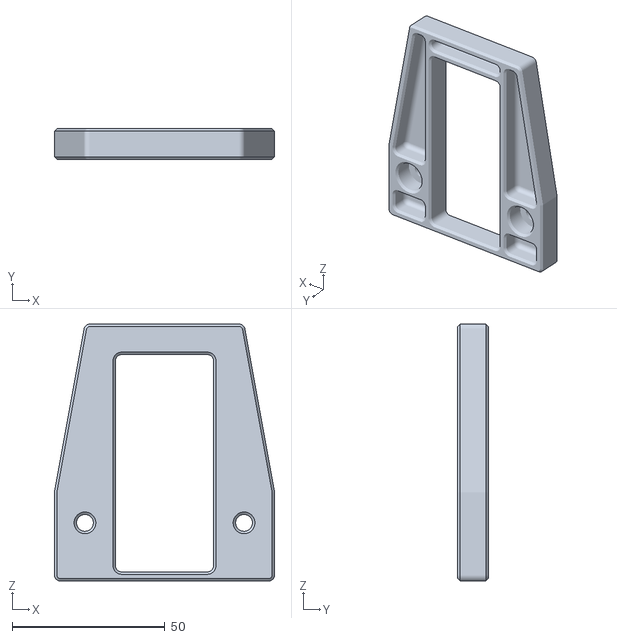
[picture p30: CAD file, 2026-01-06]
Gen 2 Design/Mechanical files/3DP/load-cell-protection-bracket.stl
72.0 x 10.0 x 84.0

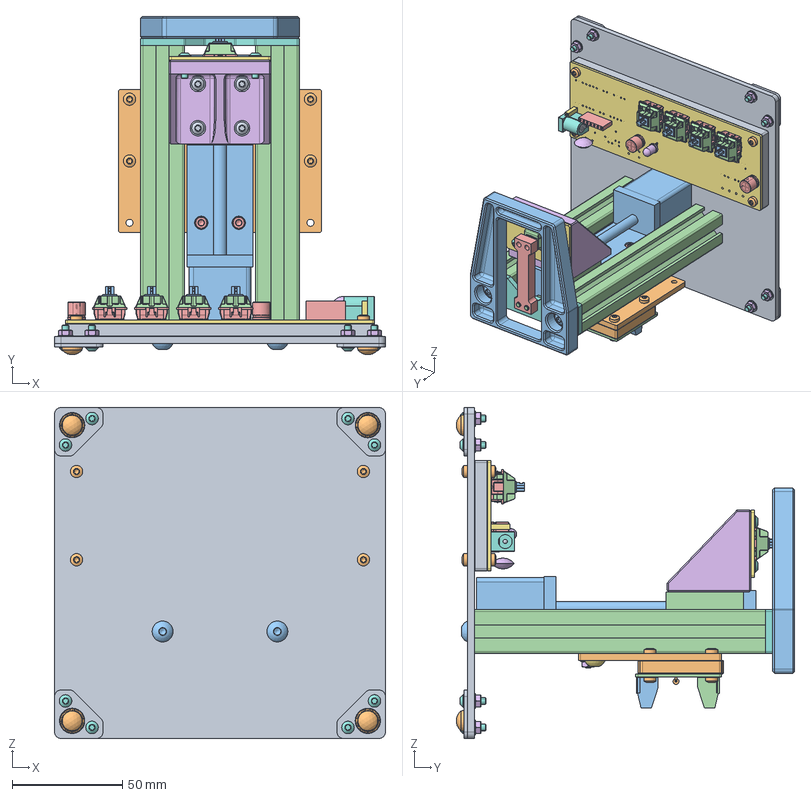
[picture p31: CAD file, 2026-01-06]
Gen 2 Design/Mechanical files/Force-curve-meter-Gen2.stp
150.0 x 153.4 x 150.0 mm

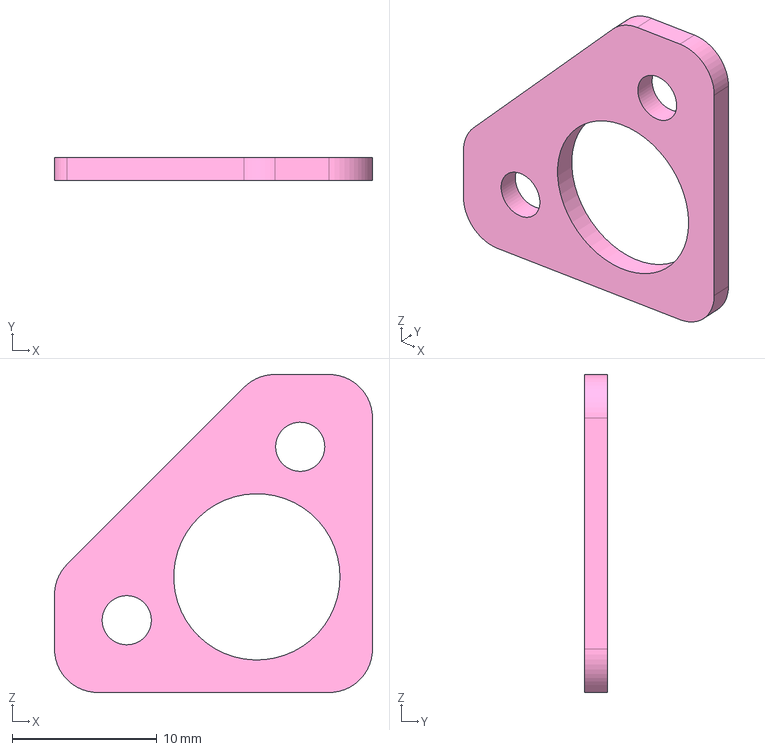
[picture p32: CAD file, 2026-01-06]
Gen 2 Design/Mechanical files/Laser cut/bumpon-holder.stp
22.0 x 1.60 x 22.0 mm

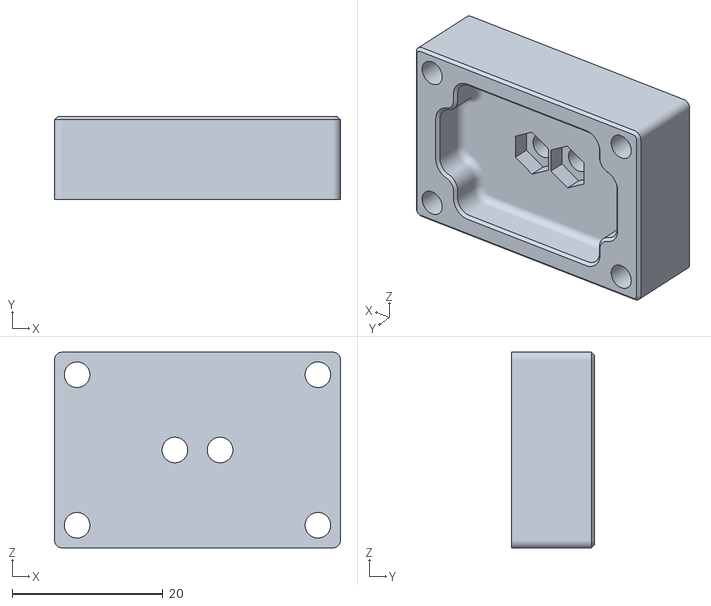
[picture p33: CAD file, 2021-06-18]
CAD (Atom3D)/STLs/Switch-mount-on-load-cell.stl
38.0 x 11.0 x 26.0

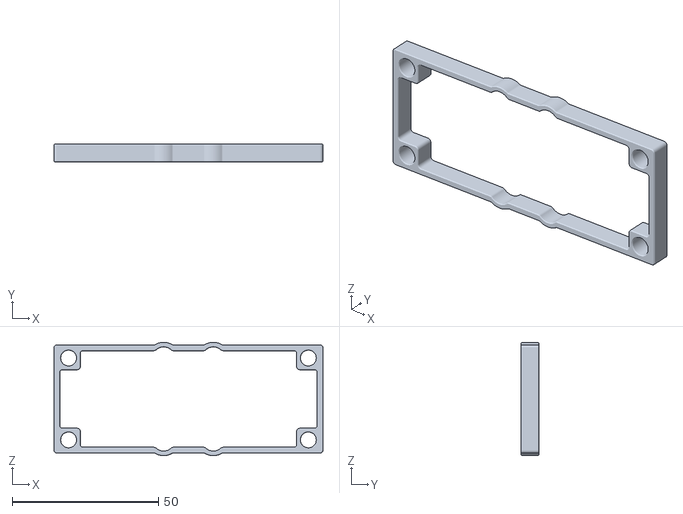
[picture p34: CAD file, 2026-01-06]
Gen 2 Design/Mechanical files/3DP/ADC-PCB-spacer.stl
92.0 x 6.00 x 38.8

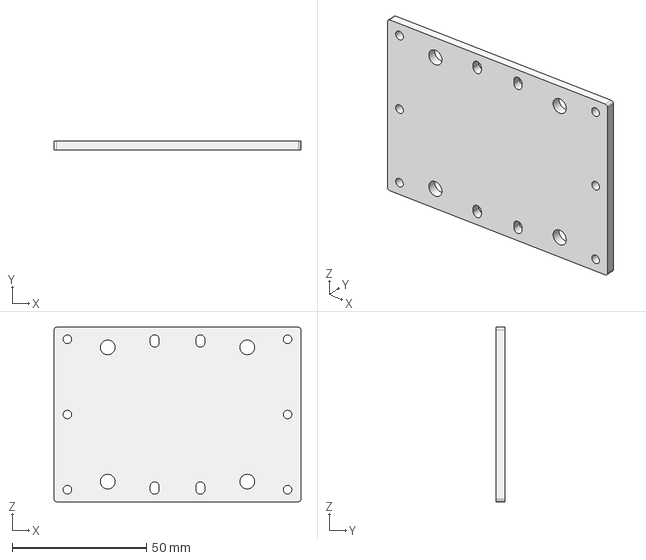
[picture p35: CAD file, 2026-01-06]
Gen 2 Design/Mechanical files/Laser cut/Vertical-plate.stp
92.0 x 3.18 x 65.0 mm

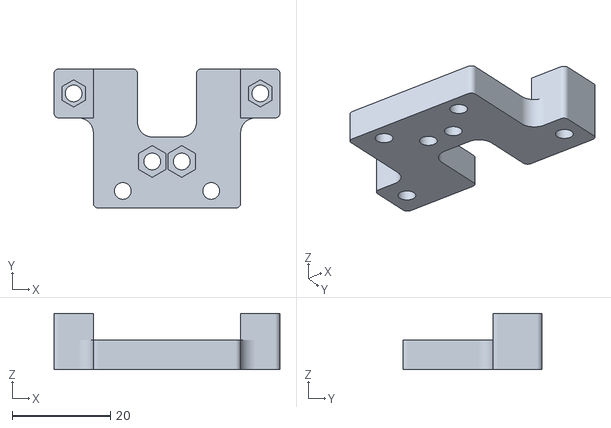
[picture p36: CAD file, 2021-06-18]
CAD (Atom3D)/STLs/Load-cell-adapter.stl
46.0 x 28.4 x 11.4

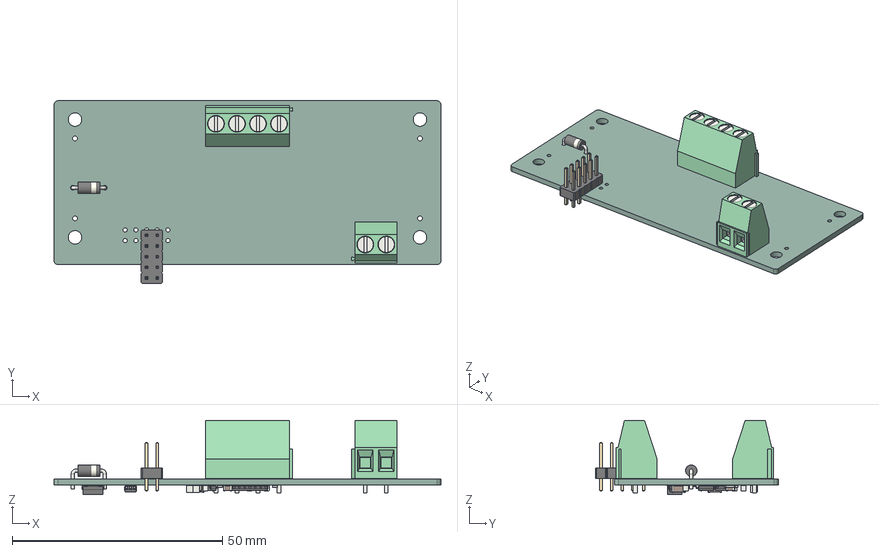
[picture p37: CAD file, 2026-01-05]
Gen 2 Design/Mechanical files/Atom3D CAD files/ADC-board-HX711.step
92.0 x 43.4 x 17.6 mm
PinHeader_2x05_P2.54mm_Vertical
D_DO-41_SOD81_P7.62mm_Horizontal
TerminalBlock_Phoenix_MKDS-1,5-2_1x02_P5.00mm_Horizontal
TerminalBlock_Phoenix_MKDS-1,5-4_1x04_P5.00mm_Horizontal
C_0805_2012Metric x 5
C_1206_3216Metric x 3
D_SMB
SOT-23-6
R_0805_2012Metric x 5
L_0805_2012Metric
SOT-23
SOP-16_3.9x9.9mm_P1.27mm
ADC-board-HX711_PCB

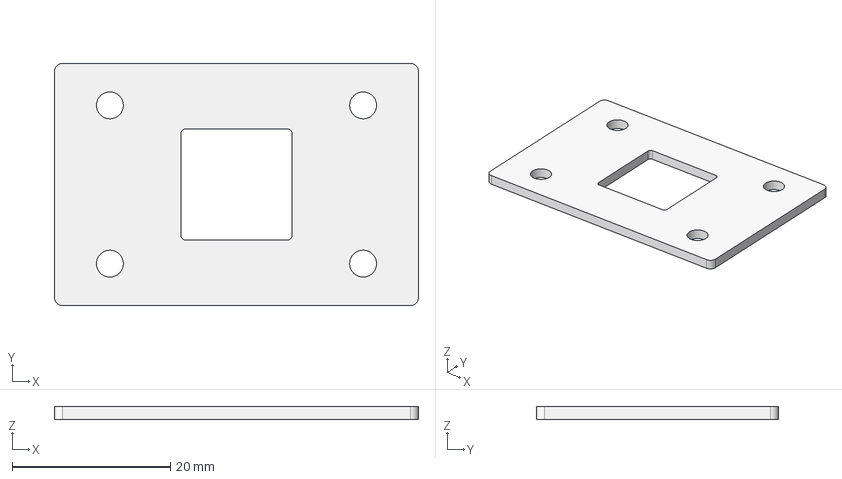
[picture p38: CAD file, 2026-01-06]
Gen 2 Design/Mechanical files/Laser cut/switch-plate.stp
46.0 x 30.6 x 1.60 mm

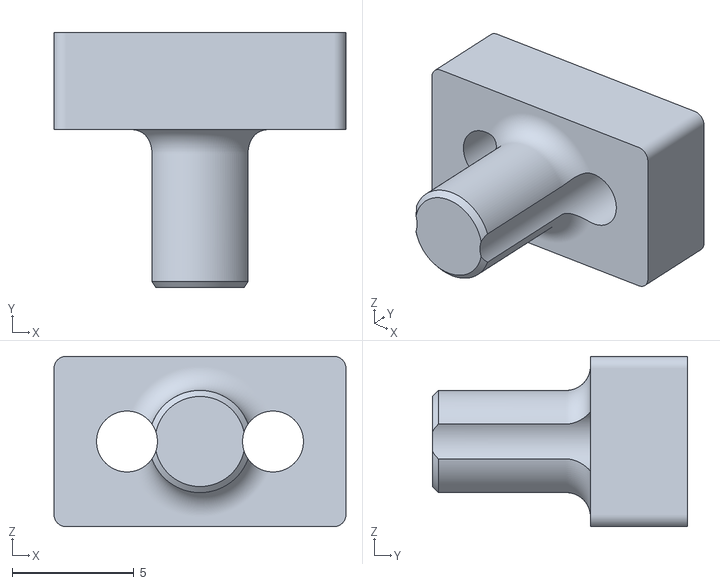
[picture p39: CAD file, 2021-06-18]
CAD (Atom3D)/STLs/pusher.stl
12.0 x 10.5 x 7.00

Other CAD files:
Gen 2 Design/Mechanical files/Laser cut/Load-cell-mounting-plate.stp
CAD (Atom3D)/STLs/Switch-mounting-bracket.stl
Gen 2 Design/Mechanical files/Laser cut/Baseplate-stand.stp
Gen 2 Design/Mechanical files/Atom3D CAD files/M3-hex-nut-DIN-934.step
CAD (Atom3D)/plate.dxf
Gen 2 Design/Mechanical files/Atom3D CAD files/M5x8-ISO-7380-screw.step
Gen 2 Design/Mechanical files/Laser cut/vertical-plate.dxf

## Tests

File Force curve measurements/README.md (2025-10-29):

Here are the force curves I have so far. This page is frequently updated. The force curves here (the PNG and .ods files) are licensed under the [Creative Commons 4.0 license](https://creativecommons.org/licenses/by/4.0/). 

If you don't know how to read a force curve, [HaaTa](https://www.keebtalk.com/t/how-to-read-a-force-curve/65) and [ThereminGoat](https://www.theremingoat.com/blog/a-beginners-guide-to-force-curves) have good intro articles.

I am planning a reorganization of this page soon, as it is getting quite long now. Until then - Ctrl-F is probably the best way to navigate this.

# Stock Switches

Adobau Labs x JWK Bouquet:
Bouquet

AEBoards Naevy R1.5 (missing contact):
Naevy R1.5

AEBoards Naevy R2:
Naevy R2

Aflion Iceberg:
Aflion Iceberg

Akko x KTT CS Jelly Black:
Akko Jelly Black

Akko x KTT CS Jelly Blue:
Akko Jelly Blue

Akko x KTT CS Jelly Pink:
Akko Jelly Pink

Akko x KTT CS Jelly Purple:
Akko Jelly Purple

Akko x KTT CS Jelly White:
Akko Jelly White

Akko x KTT CS Ocean Blue:
Akko Ocean Blue

Akko x KTT CS Lavender Purple:
Akko Purple

Akko x KTT CS Radiant Red:
Akko Radiant Red

Akko x KTT CS Sponge:
Akko Sponge

Akko x KTT CS Starfish:
Akko Starfish

Akko x KTT CS Vintage White:
Akko Vintage White

Alphakeys x BSUN POM Glacier Panda:
POM Glacier Panda

Alphakeys Dusk Panda:
Alphakeys Dusk Panda

AregKeyboards x Kailh Purple Potato:
Purple Potato

Aula Matcha:
Aula Matcha

Aula Wooden Blue:
Aula Wooden Blue

C3 Equalz x JWK Kiwi:                             
Kiwi
Kiwi

Cherry MX Black Hyperglide:
MX Black Hyperglide

Cherry MX Blue Hyperglide:
MX Blue Hyperglide

Cherry MX Blue RGB:
MX Blue RGB

Cherry MX Brown Hyperglide:
MX Brown Hyperglide

Cherry MX Purple RGB MX2A:
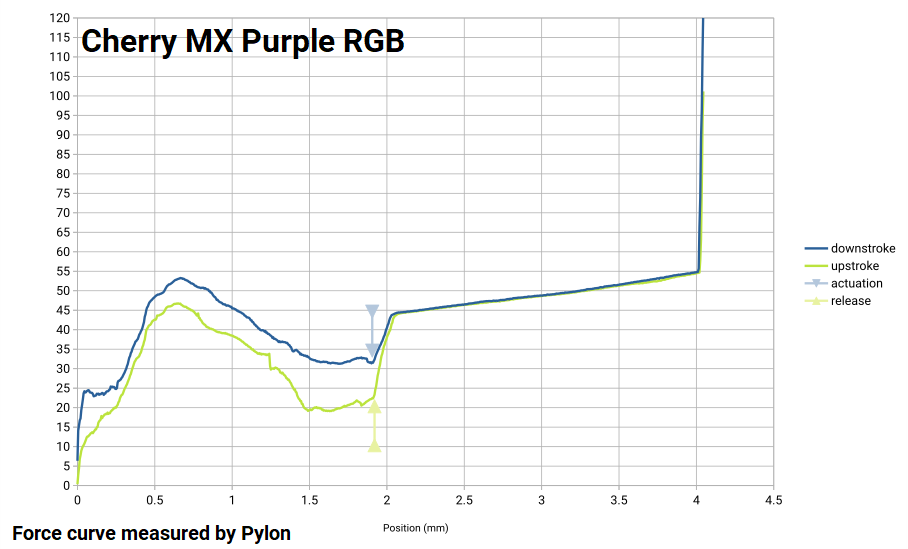
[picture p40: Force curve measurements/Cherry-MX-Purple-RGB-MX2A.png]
Cherry MX Purple RGB MX2A


Cherry MX Red:
Cherry MX Red

Durock (JWK) Blue Macaw:
Durock Blue Macaw

Durock (JWK) Cerulean:
Durock Cerulean

Durock (JWK) Daybreak:
Durock Daybreak

Durock (JWK) Dolphin:
Durock Dolphin

Durock (JWK) Koala 67gf:
Durock Koala
Durock Koala 2nd measurement

Durock (JWK) Medium Tactile:
Durock Medium Tactile

Durock (JWK) Lilac Tactile:
Durock Lilac Tactile

Durock (JWK) Linear 55g:
Durock Linear 55g

Durock (JWK) Linear 62g:
Durock Linear 62g

Durock (JWK) Linear 65g:
Durock Linear 65g

Durock (JWK) Linear 67g:
Durock Linear 67g

Durock (JWK) Linear 78g:
Durock Linear 78g

Durock (JWK) Lupine:
Durock Lupine

Durock (JWK) POM Linear:
Durock JWK POM Linear

Durock (JWK) Shrimp (Silent T1):
Durock Shrimp

Durock (JWK) Sunflower (POM T1):
POM T1
POM T1 2nd measurement

Durock (JWK) T1:
T1

Durock (JWK) T1 Dark Amber:
POM T1

Durock (JWK) Taro Ball:
Durock Taro Ball

Everglide Aqua King 55g:        
Aqua King

Everglide Bamboo:
Everglide Bamboo

Everglide Dark Jade (Moyu Black):
Everglide Dark Jade

Futaba MA-41 (clicky, Cherry MX mount):
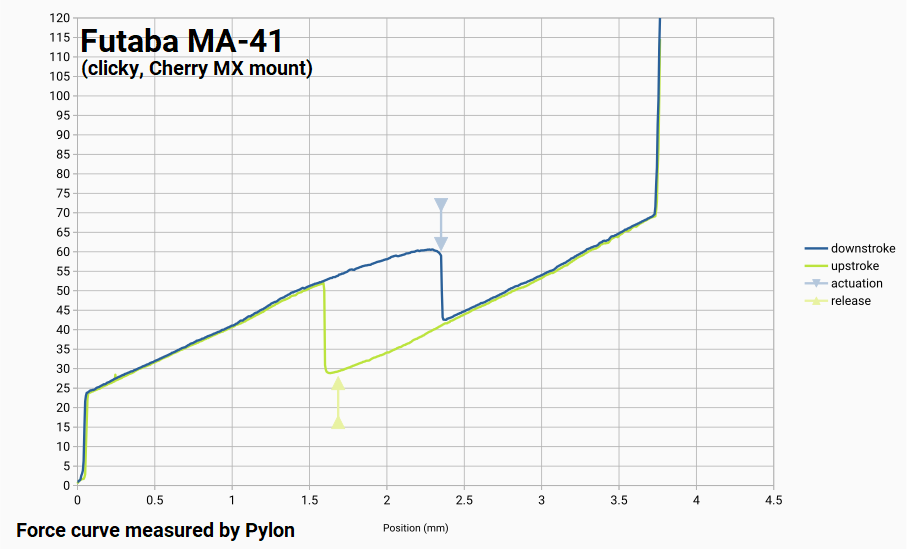
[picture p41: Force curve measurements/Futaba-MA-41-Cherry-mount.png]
Futaba MA-41


Gateron Aliaz:                        
Gateron Aliaz

Gateron Blue:                             
Gateron Blue

Gateron Brown:
Gateron Brown

Gateron Cap Brown:
Gateron Cap Brown
Gateron Cap Brown second measurement

Gateron Cap Yellow:                         
Gateron Cap Yellow

Gateron Cap Yellow Milky V2:
Gateron Cap Yellow Milky V2

Gateron CJ:                 
Gateron CJ

Gateron G-Pro Yellow:
Gateron G-Pro Yellow

Gateron Green:              
Gateron Green

Gateron Ink Red V2:
Gateron Ink Red V2

Gateron Ink Yellow:
Gateron Ink Yellow

Gateron Ink Yellow V2:
Gateron Ink Yellow V2

Gateron Kangaroo:
Gateron Kangaroo 

Gateron Limbo:                    
Gateron Limbo

Gateron Melodic:                    
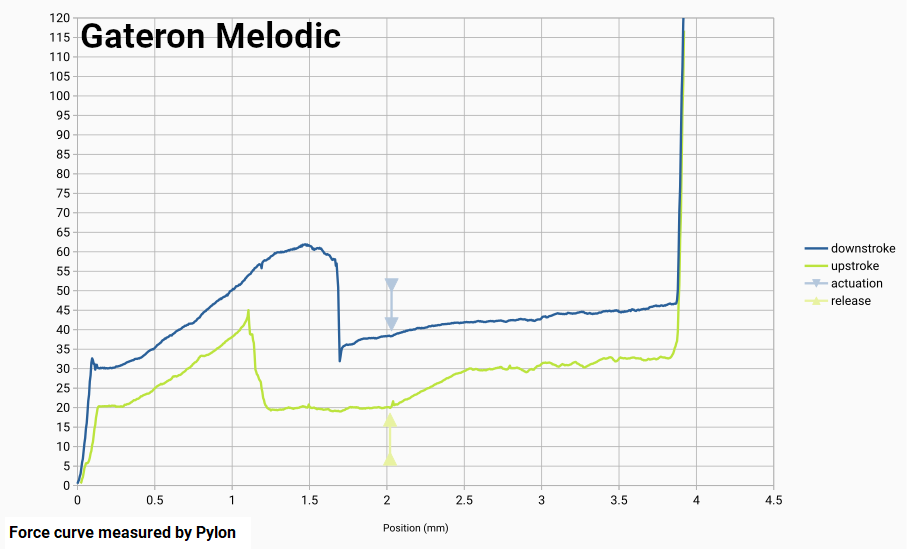
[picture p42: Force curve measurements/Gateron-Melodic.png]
Gateron Melodic


Gateron Milky Black:
Gateron Milky Black

Gateron Milky Blue:
Gateron Milky Blue

Gateron Milky Clear:
Gateron Milky Clear

Gateron Milky Red:
Gateron Milky Red

Gateron Milky Yellow:
Gateron Milky Yellow

Gateron Oil King:
Gateron Oil King

Gateron Silver Blizzard:
Gateron Silver Blizzard

Gateron Slate:                                     
Gateron Silver Blizzard

Gazzew x Outemu Boba U4 62gf:
Gazzew Boba U4 62g

Gazzew x Outemu Boba U4 68gf:
Gazzew Boba U4 68g

Gazzew x Outemu Boba U4 Thock (U4T) 62gf:
Gazzew Boba U4 62g

Gazzew x Outemu Boba U4 vs U4 Thock (U4T) 68gf:
Gateron Limbo

Gazzew x Outemu Bobagum 52gf:
Gazzew Bobagum

Gazzew x Outemu Phoenix Stem in Boba housing:
Gazzew Phoenix Stem in Boba

*(I was split as to whether this was a franken, but it is a combo that is buildable out of parts that Gazzew sells, and isn't sold as a complete switch)*
Gazzew x Outemu Silent Tactile - Silent Sky V2.2 stem in Gazzew/Outemu Boba Housing:
Outemu Silent Sky Stem in Boba Housing

Grain Gold Neon V2:
![Grain Gold Neon V2]
(https://github.com/bluepylons/Open-Switch-Curve-Meter/blob/main/Force%20curve%20measurements/Grain-Gold-Neon-V2.png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)

Huano Cyan:                             
Huano Cyan

Huano Dustproof Pink (Grey Bottom):
Huano Dustproof Pink

Huano x Old Tom Holy Tom:
Holy Tom

Huano Hot Pink:
Huano Hot Pink

Huano Lilac:
Huano Lilac

Huano Orange:
Huano Orange

Huano Smoky Pink:
Huano Smoky Pink

Huano Smoky White:
Huano Smoky White

Huano Strawberry Jelly V4:
![Hanuo Straberry Jelly V4]
(https://github.com/bluepylons/Open-Switch-Curve-Meter/blob/main/Force%20curve%20measurements/Huano-Strawberry-Jelly-V4.png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)

Jerrzi Blue:
![Jerrzi Blue]
(https://github.com/bluepylons/Open-Switch-Curve-Meter/blob/main/Force%20curve%20measurements/Jerrzi-Blue.png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)

Jerrzi Kyria Brown:
![Jerrzi Kyria Brown]
(https://github.com/bluepylons/Open-Switch-Curve-Meter/blob/main/Force%20curve%20measurements/Jerrzi-Kyria-Brown.png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)

Jwick (JWK) Black T1: 
Jwick T1

JWK Alpaca "V2":
JWK Alpaca "V2"

JWK Pewter:        
JWK Peter

(Proposed) JWK Twilight:
JWK Twilight

JWK Twilight (prototype vs actual GB vs JWK Medium Tactile):
JWK Twilight

Kailh x Archon Art Box Brown:
Kailh Box Brown

Kailh Box Silent Brown:
Box Silent Brown

[Kailh Choc switches](https://github.com/bluepylons/Open-Switch-Curve-Meter/blob/main/Force%20curve%20measurements/Kailh%20Choc%20Switches/README.md)

Kailh Polia:                      
Kailh Polia

Kailh Speed Pale Blue:
Kailh Speed Pale Blue

Keebfront x Meirun Doom:
Keebfront-Doom

KTT Gold:                            
KTT Gold

KTT Grapefruit:                  
KTT Grapefruit

KTT HaluHalo:
KTT HaluHalo

KTT Mallo:                          
KTT Mallo

KTT Matcha:                                                   
KTT Matcha

KTT Monochrome Chalk:
KTT Monochrome Chalk

KTT Monochrome Marble:
KTT Monochrome Marble

KTT Monochrome Onyx:
KTT Monochrome Onyx

KTT Peach:            
KTT Peach

KTT Rose:            
KTT Rose

KTT Sea Salt Lemon:
KTT Sea Salt Lemon

KTT Soot (Ash):
KTT Soot (Ash)

KTT Strawberry:
KTT Strawberry

LCET Blue Pink:
LCET Blue Pink

Mechs on Deck x JWK Anubis:
Mechs on Deck Anubis

MiTo x KBDfans x Gateron Laser 60g:
Laser 60g

MiTo x KBDfans x Gateron Laser 60g:
Laser 70g

Momoka Frog:              
Momoka Frog    

Moyu.studio x acitrin, Chris @ Mechs & Co, and stellaidoscope x JWK Commute:
Moyu JWK Hades 

Moyu.studio x JWK Hades:
Moyu JWK Hades 

Moyu.studio x JWK Poseidon:
Moyu JWK Poseidon 

Moyu.studio x JWK Queen:
Moyu JWK Queen 

Novelkeys x JWK Silk Yellow:
NK Silk Yellow

NovelKeys x Kailh Blueberry:
NK Blueberry

NovelKeys x Kailh Box Cream:
Box Cream 

NovelKeys x Kailh Box Jade:
Box Jade
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

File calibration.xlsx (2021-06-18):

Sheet: Calibrate-everyday
 | Nothing | 100g calibration weight
 | 0g | 100g
 |  |  | 0 | #DIV/0! | Units Per Gram | #DIV/0!
 |  |  | -100 | #DIV/0! | Zero | #DIV/0!
 |  |  |  |  |  |  | 2812092
Average | #DIV/0! | #DIV/0!

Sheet: reverse-mount
 | Nothing | 100g calibration weight
 | 0g | 100g
 | 237894 | 555240
 | 237912 | 555205
 | 237869 | 555219 | 0 | 237910 | Units Per Gram | -3172.946061
 | 237834 | 555269 | -100 | 555204.6061 | Zero | -74.98078929
 | 237862 | 555228
 | 237872 | 555191
 | 237855 | 555190
 | 237924 | 555179
 | 237896 | 555192
 | 237876 | 555177
 | 237901 | 555238
 | 237918 | 555209
 | 237909 | 555219
 | 237864 | 555209 |  |  |  |  | 2812092
 | 237921 | 555189
 | 237932 | 555211
 | 237901 | 555185
 | 237897 | 555189
 | 237911 | 555239
 | 237920 | 555230
 | 237942 | 555251
 | 237946 | 555216
 | 237943 | 555220
 | 237953 | 555217
 | 237927 | 555200
 | 237883 | 555211
 | 237876 | 555267
 | 237911 | 555235
 | 237927 | 555221
 | 237923 | 555214
 | 237988 | 555190
 | 237962 | 555180
 | 237901 | 555179
 | 237892 | 555237
 | 237943 | 555202
 | 237913 | 555163
 | 237870 | 555206
 | 237911 | 555232
 | 237893 | 555207
 | 237929 | 555245
 | 237914 | 555220
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

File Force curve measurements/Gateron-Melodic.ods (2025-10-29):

 | Raw X (microns) | Raw Force (gf) | Actuated? | Force - Tared (gf) | Corrected downstroke X (mm) | Corrected downstroke force (gf) | Corrected downstroke actuated? | Corrected upstroke X (mm) | Corrected upstroke force (gf) | Corrected upstroke actuated? | Actuation points | Actuation arrow points | Release points | Release arrow points
0 | 0 | -0.22 | 0 | -0.029 | 0 | 0.481 | 0 | 3.92 | 116.751 | 1 | 2.03 | 41.381 | 2.02 | 16.931
1 | 5 | -0.14 | 0 | 0.051 | 0.005 | 1.061 | 0 | 3.915 | 103.011 | 1 | 2.03 | 51.381 | 2.02 | 6.931
2 | 10 | -0.15 | 0 | 0.041 | 0.01 | 1.431 | 0 | 3.91 | 95.771 | 1
3 | 15 | -0.17 | 0 | 0.021 | 0.015 | 2.371 | 0 | 3.905 | 82.331 | 1
4 | 20 | -0.18 | 0 | 0.011 | 0.02 | 2.981 | 0 | 3.9 | 69.421 | 1
5 | 25 | -0.19 | 0 | 0.001 | 0.025 | 4.371 | 0 | 3.895 | 63.081 | 1
6 | 30 | -0.18 | 0 | 0.011 | 0.03 | 5.971 | 0 | 3.89 | 51.561 | 1
7 | 35 | -0.17 | 0 | 0.021 | 0.035 | 6.851 | 0 | 3.885 | 46.571 | 1
8 | 40 | -0.19 | 0 | 0.001 | 0.04 | 8.821 | 0 | 3.88 | 39.511 | 1
9 | 45 | -0.2 | 0 | -0.009 | 0.045 | 10.841 | 0 | 3.875 | 37.051 | 1
10 | 50 | -0.19 | 0 | 0.001 | 0.05 | 12.191 | 0 | 3.87 | 36.541 | 1
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

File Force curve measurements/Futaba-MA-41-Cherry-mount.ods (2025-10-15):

 | Raw X (microns) | Raw Force (gf) | Actuated? | Force - Tared (gf) | Corrected downstroke X (mm) | Corrected downstroke force (gf) | Corrected downstroke actuated? | Corrected upstroke X (mm) | Corrected upstroke force (gf) | Corrected upstroke actuated? | Actuation points | Actuation arrow points | Release points | Release arrow points
0 | 0 | -0.23 | 0 | -0.005 | 0 | 1.005 | 0 | 3.765 | 114.615 | 1 | 2.35 | 62.005 | 1.685 | 26.305
1 | 5 | -0.26 | 0 | -0.035 | 0.005 | 1.005 | 0 | 3.76 | 99.405 | 1 | 2.35 | 72.005 | 1.685 | 16.305
2 | 10 | -0.23 | 0 | -0.005 | 0.01 | 1.255 | 0 | 3.755 | 86.475 | 1
3 | 15 | -0.25 | 0 | -0.025 | 0.015 | 1.335 | 0 | 3.75 | 81.055 | 1
4 | 20 | -0.25 | 0 | -0.025 | 0.02 | 1.655 | 0 | 3.745 | 72.965 | 1
5 | 25 | -0.28 | 0 | -0.055 | 0.025 | 2.575 | 0 | 3.74 | 70.615 | 1
6 | 30 | -0.24 | 0 | -0.015 | 0.03 | 3.085 | 0 | 3.735 | 69.145 | 1
7 | 35 | -0.21 | 0 | 0.015 | 0.035 | 3.835 | 0 | 3.73 | 69.045 | 1
8 | 40 | -0.25 | 0 | -0.025 | 0.04 | 6.325 | 0 | 3.725 | 69.015 | 1
9 | 45 | -0.23 | 0 | -0.005 | 0.045 | 14.815 | 0 | 3.72 | 68.905 | 1
10 | 50 | -0.22 | 0 | 0.005 | 0.05 | 21.595 | 0 | 3.715 | 68.875 | 1
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

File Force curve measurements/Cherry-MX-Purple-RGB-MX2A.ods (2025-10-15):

 | Raw X (microns) | Raw Force (gf) | Actuated? | Force - Tared (gf) | Corrected downstroke X (mm) | Corrected downstroke force (gf) | Corrected downstroke actuated? | Corrected upstroke X (mm) | Corrected upstroke force (gf) | Corrected upstroke actuated? | Actuation points | Actuation arrow points | Release points | Release arrow points
0 | 0 | -0.55 | 0 | -0.02 | 0 | 6.36 | 0 | 4.045 | 101.15 | 1 | 1.905 | 34.64 | 1.92 | 20.35
1 | 5 | -0.51 | 0 | 0.02 | 0.005 | 14.08 | 0 | 4.04 | 93.36 | 1 | 1.905 | 44.64 | 1.92 | 10.35
2 | 10 | -0.55 | 0 | -0.02 | 0.01 | 15.42 | 0 | 4.035 | 76.99 | 1
3 | 15 | -0.58 | 0 | -0.05 | 0.015 | 16.75 | 0 | 4.03 | 63.08 | 1
4 | 20 | -0.55 | 0 | -0.02 | 0.02 | 17.24 | 0 | 4.025 | 57.83 | 1
5 | 25 | -0.53 | 0 | 0 | 0.025 | 19.36 | 0 | 4.02 | 54.67 | 1
6 | 30 | -0.59 | 0 | -0.06 | 0.03 | 20.71 | 0 | 4.015 | 54.62 | 1
7 | 35 | -0.56 | 0 | -0.03 | 0.035 | 22.11 | 0 | 4.01 | 54.55 | 1
8 | 40 | -0.5 | 0 | 0.03 | 0.04 | 23.68 | 0 | 4.005 | 54.55 | 1
9 | 45 | -0.53 | 0 | 0 | 0.045 | 24.21 | 0 | 4 | 54.58 | 1
10 | 50 | -0.53 | 0 | 0 | 0.05 | 23.88 | 0 | 3.995 | 54.42 | 1
11 | 55 | -0.57 | 0 | -0.04 | 0.055 | 23.95 | 0 | 3.99 | 54.39 | 1
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

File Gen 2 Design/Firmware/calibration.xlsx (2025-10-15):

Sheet: Calibrate-everyday
 | Nothing | 100g calibration weight
 | 0g | 100g
 | -87430 | -396766
 | -87476 | -396521
 | -87308 | -396554 | 0 | -87437.9596 | Units Per Gram | 3093.160404
 | -87399 | -396804 | -100 | -396754 | Zero | -28.26816207
 | -87371 | -396942
 | -87414 | -396601
 | -87342 | -396880
 | -87260 | -396742
 | -87511 | -396405
 | -87424 | -396663
 | -87514 | -396592
 | -87577 | -396845
 | -87510 | -396735
 | -87493 | -396950
 | -87529 | -396656
 | -87488 | -396976
 | -87371 | -396705
 | -87380 | -396938
 | -87426 | -396558
 | -87583 | -396768
 | -87500 | -396662
 | -87507 | -396922
 | -87648 | -396486
 | -87394 | -396636
 | -87487 | -396853
 | -87606 | -396675
 | -87320 | -396620
 | -87334 | -396693
 | -87364 | -396686
 | -87241 | -396622
 | -87359 | -396623
 | -87460 | -396753
 | -87430 | -396576
 | -87482 | -396769
 | -87407 | -396545
 | -87400 | -396636
 | -87432 | -396678
 | -87453 | -396719
 | -87412 | -396781
 | -87419 | -396738
 | -87419 | -396838
 | -87478 | -396680
 | -87436 | -396627
 | -87417 | -396741
 | -87332 | -396640
 | -87343 | -396759
 | -87223 | -396772
 | -87490 | -396468
 | -87559 | -396524
 | -87424 | -396749
 | -87580 | -396609
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

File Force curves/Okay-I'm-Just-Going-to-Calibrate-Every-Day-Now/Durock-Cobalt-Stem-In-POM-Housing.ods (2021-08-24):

Raw data |  |  |  | Corrected Downstroke |  | Corrected Upstroke
X (microns) | Force (gf) | Actuated? | Tared | X (mm) | Force (gf) | X (mm) | Force (gf)
0 | -0.04 | 0 | 0 | 0 | 0.23 | 3.555 | 55.21
5 | -0.05 | 0 | -0.01 | 0.005 | 2.15 | 3.55 | 56.06
10 | -0.06 | 0 | -0.02 | 0.01 | 12.03 | 3.545 | 56.55
15 | -0.05 | 0 | -0.01 | 0.015 | 23.02 | 3.54 | 56.5
20 | -0.03 | 0 | 0.01 | 0.02 | 26.57 | 3.535 | 56.52
25 | -0.04 | 0 | 0 | 0.025 | 29.33 | 3.53 | 56.5
30 | -0.04 | 0 | 0 | 0.03 | 30.24 | 3.525 | 56.48
35 | -0.02 | 0 | 0.02 | 0.035 | 30.33 | 3.52 | 56.45
40 | -0.03 | 0 | 0.01 | 0.04 | 29.8 | 3.515 | 56.36
45 | -0.05 | 0 | -0.01 | 0.045 | 29.98 | 3.51 | 56.33
50 | -0.04 | 0 | 0 | 0.05 | 30.73 | 3.505 | 56.28
55 | -0.08 | 0 | -0.04 | 0.055 | 31.55 | 3.5 | 56.26
60 | -0.04 | 0 | 0 | 0.06 | 31.77 | 3.495 | 56.16
65 | -0.07 | 0 | -0.03 | 0.065 | 31.93 | 3.49 | 56.11
70 | -0.03 | 0 | 0.01 | 0.07 | 31.97 | 3.485 | 56.15
75 | -0.07 | 0 | -0.03 | 0.075 | 31.83 | 3.48 | 56.15
80 | -0.05 | 0 | -0.01 | 0.08 | 31.81 | 3.475 | 56.05
85 | -0.04 | 0 | 0 | 0.085 | 31.81 | 3.46999999999999 | 56.02
90 | -0.06 | 0 | -0.02 | 0.09 | 31.97 | 3.46499999999999 | 55.95
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

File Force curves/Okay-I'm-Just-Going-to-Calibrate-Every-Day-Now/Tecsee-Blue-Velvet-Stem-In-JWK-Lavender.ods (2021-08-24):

Raw data |  |  |  | Corrected Downstroke |  | Corrected Upstroke
X (microns) | Force (gf) | Actuated? | Tared | X (mm) | Force (gf) | X (mm) | Force (gf)
0 | -0.01 | 0 |  | 0 | 0.15 | 3.35 | 110.87
5 | 0 | 0 |  | 0.005 | 1.04 | 3.345 | 102.76
10 | 0 | 0 |  | 0.01 | 10.91 | 3.34 | 87.83
15 | 0 | 0 |  | 0.015 | 16.14 | 3.335 | 80.33
20 | 0 | 0 |  | 0.02 | 17.72 | 3.33 | 66.9
25 | -0.02 | 0 |  | 0.025 | 17.75 | 3.325 | 61.03
30 | -0.01 | 0 |  | 0.03 | 19.22 | 3.32 | 55.54
35 | -0.04 | 0 |  | 0.035 | 21.6 | 3.315 | 55.07
40 | 0 | 0 |  | 0.04 | 22.5 | 3.31 | 55.08
45 | 0.15 | 0 |  | 0.045 | 23.54 | 3.305 | 55.03
50 | 1.04 | 0 |  | 0.05 | 23.75 | 3.3 | 55.04
55 | 10.91 | 0 |  | 0.055 | 24.31 | 3.295 | 54.95
60 | 16.14 | 0 |  | 0.06 | 24.92 | 3.29 | 54.92
65 | 17.72 | 0 |  | 0.065 | 25.87 | 3.285 | 54.91
70 | 17.75 | 0 |  | 0.07 | 26.52 | 3.28 | 54.84
75 | 19.22 | 0 |  | 0.075 | 29.33 | 3.275 | 54.78
80 | 21.6 | 0 |  | 0.08 | 31.5 | 3.27 | 54.76
85 | 22.5 | 0 |  | 0.085 | 34.12 | 3.265 | 54.69
90 | 23.54 | 0 |  | 0.09 | 34.42 | 3.26 | 54.64
95 | 23.75 | 0 |  | 0.095 | 33.87 | 3.255 | 54.59
100 | 24.31 | 0 |  | 0.1 | 33.81 | 3.25 | 54.58
105 | 24.92 | 0 |  | 0.105 | 33.79 | 3.245 | 54.52
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

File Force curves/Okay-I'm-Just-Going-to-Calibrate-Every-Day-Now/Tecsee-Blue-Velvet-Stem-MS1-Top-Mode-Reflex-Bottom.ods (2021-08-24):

Raw data |  |  |  | Corrected Downstroke |  | Corrected Upstroke
X (microns) | Force (gf) | Actuated? | Tared | X (mm) | Force (gf) | X (mm) | Force (gf)
0 | -0.21 | 0 | -0.01 | 0 | 0.06 | 2.985 | 126.76
5 | -0.19 | 0 | 0.01 | 0.005 | 9.4 | 2.98 | 114.06
10 | -0.17 | 0 | 0.03 | 0.01 | 16.17 | 2.975 | 106.88
15 | -0.18 | 0 | 0.02 | 0.015 | 24.46 | 2.97 | 91.57
20 | -0.19 | 0 | 0.01 | 0.02 | 27.4 | 2.965 | 84.22
25 | -0.19 | 0 | 0.01 | 0.025 | 28.62 | 2.96 | 69.32
30 | -0.18 | 0 | 0.02 | 0.03 | 29.5 | 2.955 | 62.62
35 | -0.2 | 0 | 0 | 0.035 | 29.78 | 2.95 | 54.8
40 | -0.17 | 0 | 0.03 | 0.04 | 31.3 | 2.945 | 53.93
45 | -0.22 | 0 | -0.02 | 0.045 | 32.49 | 2.94 | 53.87
50 | -0.14 | 0 | 0.06 | 0.05 | 33.08 | 2.935 | 53.77
55 | 9.2 | 0 | 9.4 | 0.055 | 33.08 | 2.93 | 53.7
60 | 15.97 | 0 | 16.17 | 0.06 | 33.15 | 2.925 | 53.57
65 | 24.26 | 0 | 24.46 | 0.065 | 33.11 | 2.92 | 53.53
70 | 27.2 | 0 | 27.4 | 0.07 | 33.07 | 2.915 | 53.45
75 | 28.42 | 0 | 28.62 | 0.075 | 33.1 | 2.91 | 53.39
80 | 29.3 | 0 | 29.5 | 0.08 | 33.28 | 2.905 | 53.32
85 | 29.58 | 0 | 29.78 | 0.085 | 33.29 | 2.9 | 53.25
90 | 31.1 | 0 | 31.3 | 0.09 | 33.22 | 2.895 | 53.23
95 | 32.29 | 0 | 32.49 | 0.095 | 33.17 | 2.89 | 53.22
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

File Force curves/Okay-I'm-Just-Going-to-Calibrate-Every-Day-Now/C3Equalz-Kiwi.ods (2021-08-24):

Raw data |  |  |  | Corrected Downstroke |  | Corrected Upstroke
X (microns) | Force (gf) | Actuated? | Tared | X (mm) | Force (gf) | X (mm) | Force (gf)
0 | 0 | 0 |  | 0 | 0.51 | 3.89 | 69.31
5 | 0.01 | 0 |  | 0.005 | 3.67 | 3.885 | 66.16
10 | 0.01 | 0 |  | 0.01 | 17.39 | 3.88 | 66
15 | 0.04 | 0 |  | 0.015 | 25.41 | 3.875 | 65.93
20 | 0.02 | 0 |  | 0.02 | 34.9 | 3.87 | 65.87
25 | 0.01 | 0 |  | 0.025 | 34.84 | 3.865 | 65.76
30 | 0 | 0 |  | 0.03 | 34.31 | 3.86 | 65.74
35 | 0 | 0 |  | 0.035 | 34.7 | 3.855 | 65.71
40 | 0.01 | 0 |  | 0.04 | 35.19 | 3.85 | 65.68
45 | -0.02 | 0 |  | 0.045 | 35.86 | 3.845 | 65.58
50 | -0.02 | 0 |  | 0.05 | 36.27 | 3.84 | 65.57
55 | 0 | 0 |  | 0.055 | 37.32 | 3.835 | 65.55
60 | 0.01 | 0 |  | 0.06 | 38.07 | 3.83 | 65.47
65 | 0.03 | 0 |  | 0.065 | 39.12 | 3.825 | 65.45
70 | 0.04 | 0 |  | 0.07 | 39.66 | 3.82 | 65.41
75 | -0.01 | 0 |  | 0.075 | 40.49 | 3.815 | 65.39
80 | 0.03 | 0 |  | 0.08 | 40.96 | 3.81 | 65.29
85 | 0.01 | 0 |  | 0.085 | 41.75 | 3.805 | 65.28
90 | 0.02 | 0 |  | 0.09 | 41.86 | 3.8 | 65.25
95 | 0 | 0 |  | 0.095 | 41.84 | 3.795 | 65.24
100 | 0.01 | 0 |  | 0.1 | 42.06 | 3.79 | 65.2
105 | 0.01 | 0 |  | 0.105 | 42.36 | 3.785 | 65.16
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

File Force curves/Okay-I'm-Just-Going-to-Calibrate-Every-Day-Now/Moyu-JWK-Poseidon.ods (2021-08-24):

Raw data |  |  |  | Corrected Downstroke |  | Corrected Upstroke
X (microns) | Force (gf) | Actuated? | Tared | X (mm) | Force (gf) | X (mm) | Force (gf)
0 | -0.02 | 0 | 0 | 0 | 1.43 | 3.35 | 67.1
5 | -0.02 | 0 | 0 | 0.005 | 7.43 | 3.345 | 62.23
10 | -0.04 | 0 | -0.02 | 0.01 | 22.75 | 3.34 | 61.2
15 | -0.03 | 0 | -0.01 | 0.015 | 30.68 | 3.335 | 61.24
20 | -0.03 | 0 | -0.01 | 0.02 | 40.54 | 3.33 | 61.25
25 | -0.02 | 0 | 0 | 0.025 | 41.35 | 3.325 | 61.19
30 | -0.01 | 0 | 0.01 | 0.03 | 41.17 | 3.32 | 61.15
35 | -0.03 | 0 | -0.01 | 0.035 | 41.28 | 3.315 | 61.11
40 | -0.04 | 0 | -0.02 | 0.04 | 41.2 | 3.31 | 61
45 | -0.02 | 0 | 0 | 0.045 | 41.31 | 3.305 | 60.97
50 | -0.04 | 0 | -0.02 | 0.05 | 41.95 | 3.3 | 60.95
55 | -0.01 | 0 | 0.01 | 0.055 | 41.95 | 3.295 | 60.92
60 | -0.01 | 0 | 0.01 | 0.06 | 42.09 | 3.29 | 60.85
65 | -0.01 | 0 | 0.01 | 0.065 | 42.31 | 3.285 | 60.87
70 | -0.02 | 0 | 0 | 0.07 | 42.82 | 3.28 | 60.91
75 | -0.02 | 0 | 0 | 0.075 | 43.69 | 3.275 | 60.82
80 | 0 | 0 | 0.02 | 0.08 | 44.11 | 3.27 | 60.79
85 | -0.04 | 0 | -0.02 | 0.085 | 44.15 | 3.265 | 60.75
90 | -0.02 | 0 | 0 | 0.09 | 44.17 | 3.26 | 60.71
95 | -0.02 | 0 | 0 | 0.095 | 44.09 | 3.255 | 60.67
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

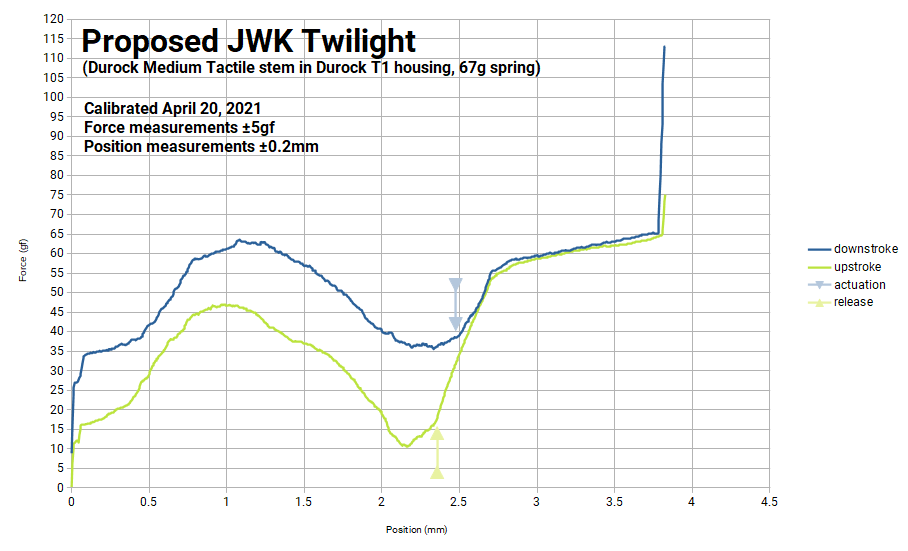
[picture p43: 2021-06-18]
Force curves/April-20-21-calibration/JWK-Twilight.png

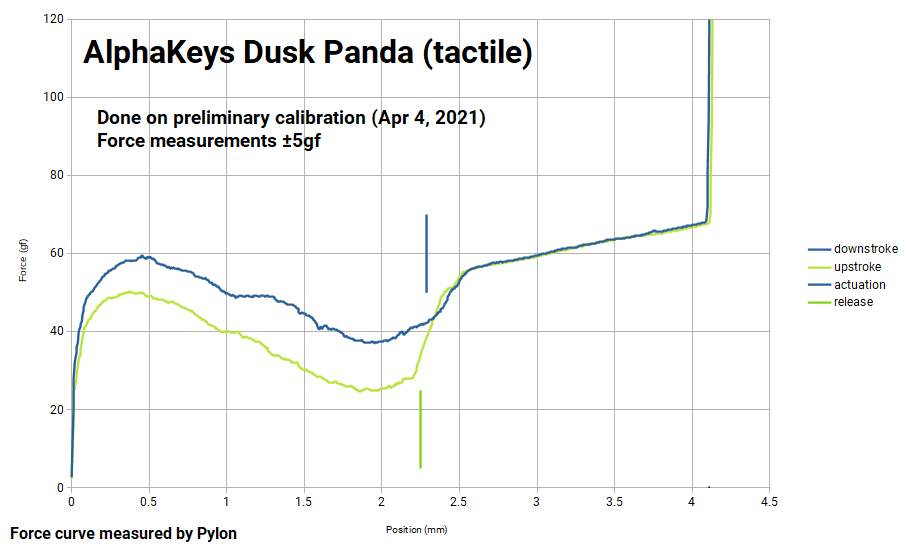
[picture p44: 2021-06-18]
Force curves/April-4-21-calibration/Alphakeys-Dusk-Panda.png

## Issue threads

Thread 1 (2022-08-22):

Graph for Boba U4 62g?

qazip, 2022-08-22:
You seem to have the .ods file for Boba U4 62g (https://github.com/bluepylons/Open-Switch-Curve-Meter/blob/main/Force%20curve%20measurements/Gazzew-Boba-U4-62g.ods) but you're missing the graph. Would be nice to have the graph as well!

bluepylons, 2022-08-26:
I ended up remeasuring the Boba U4 62g, so there's a new graph up now.

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

Closed 2022-08-26.

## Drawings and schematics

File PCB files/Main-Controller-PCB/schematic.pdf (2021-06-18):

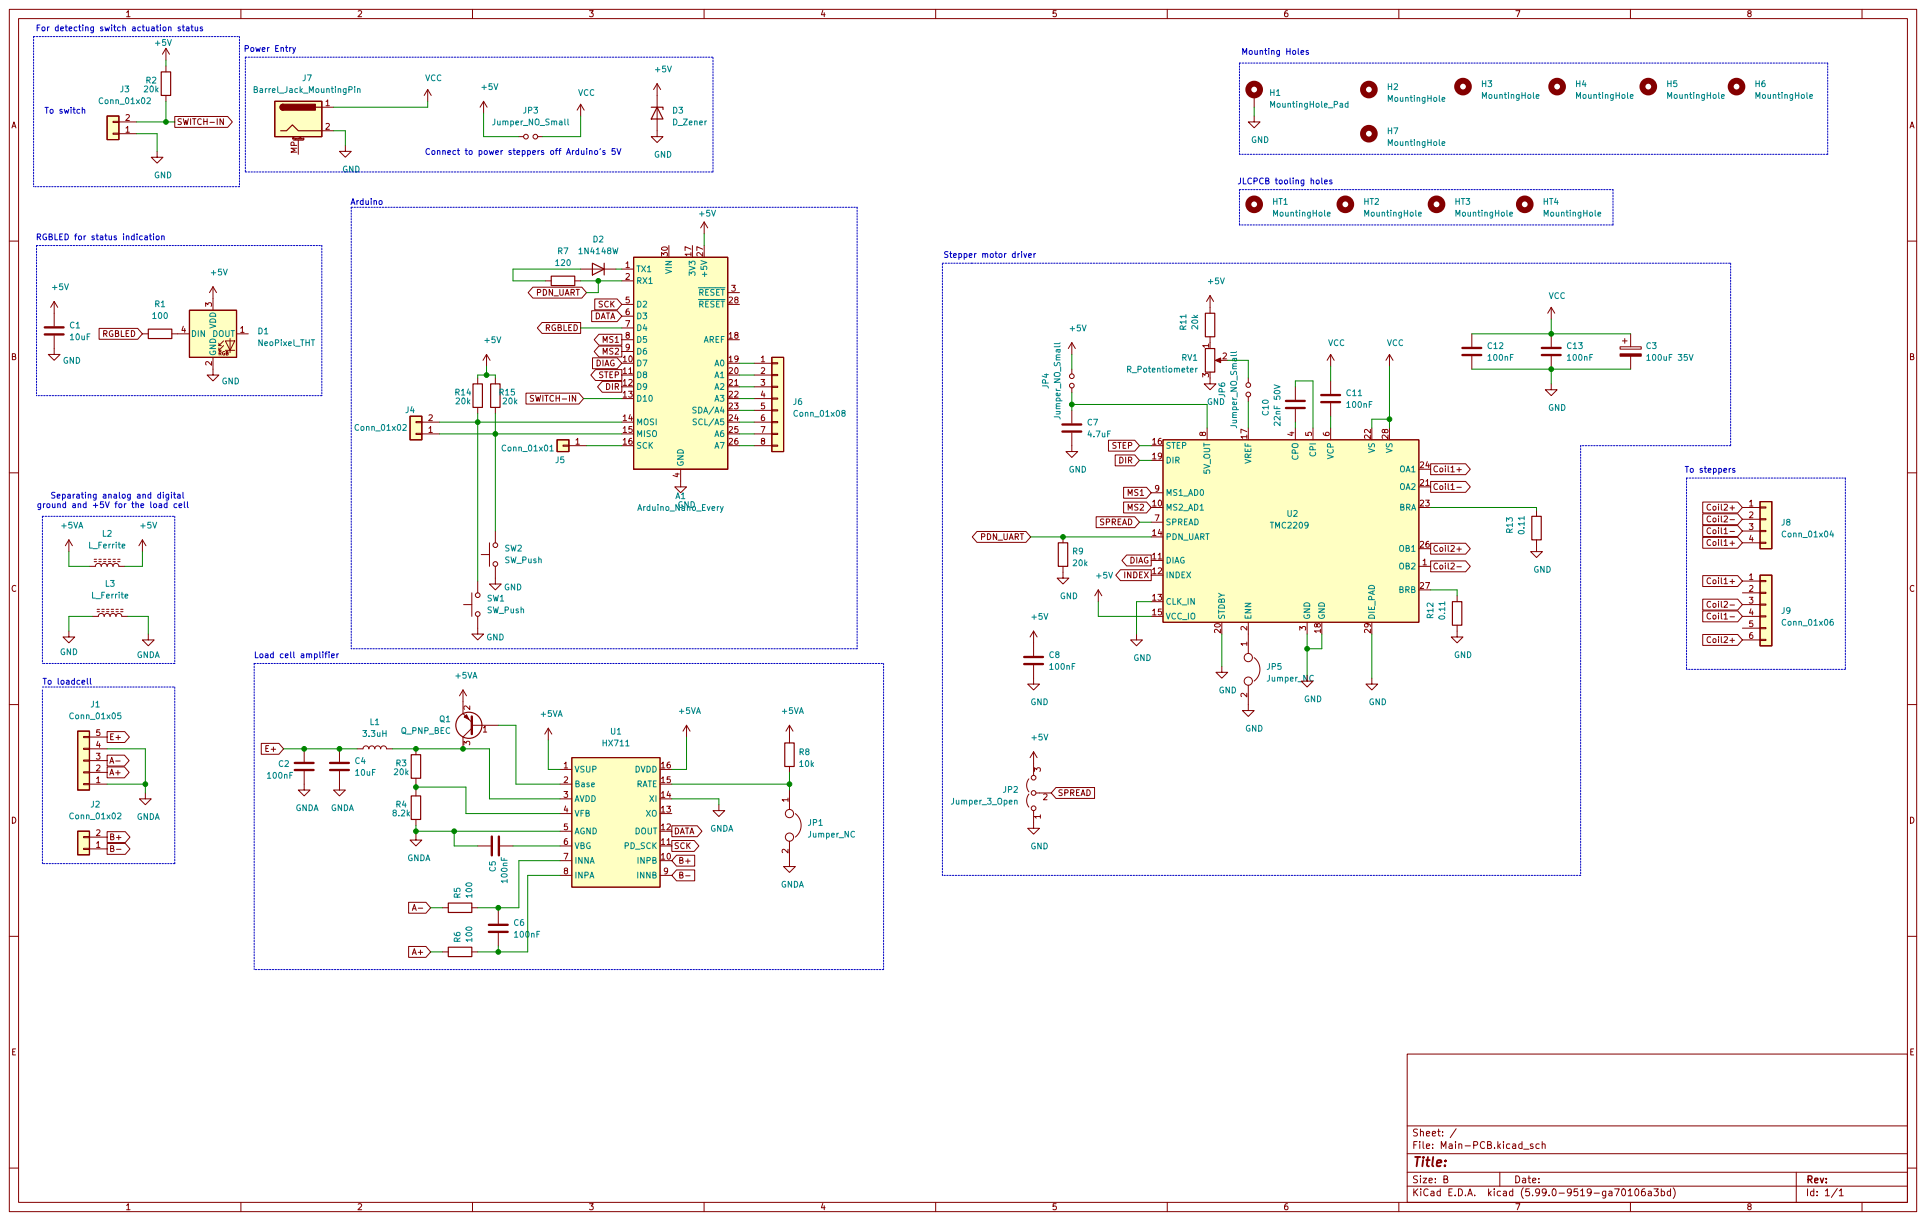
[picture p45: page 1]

To switch For detecting switch actuation status

VCC

H2MountingHole

Connect to power steppers off Arduino's 5V RGBLED for status indication

Stepper motor driver To loadcell
+5VGND

3 GND 18 BRB 27 BRA 23 OB1 26 OA1 24 OA2 21 OB2 1 VS 22 VS 28 VCP

Separating analog and digital
ground and +5V for the load cell

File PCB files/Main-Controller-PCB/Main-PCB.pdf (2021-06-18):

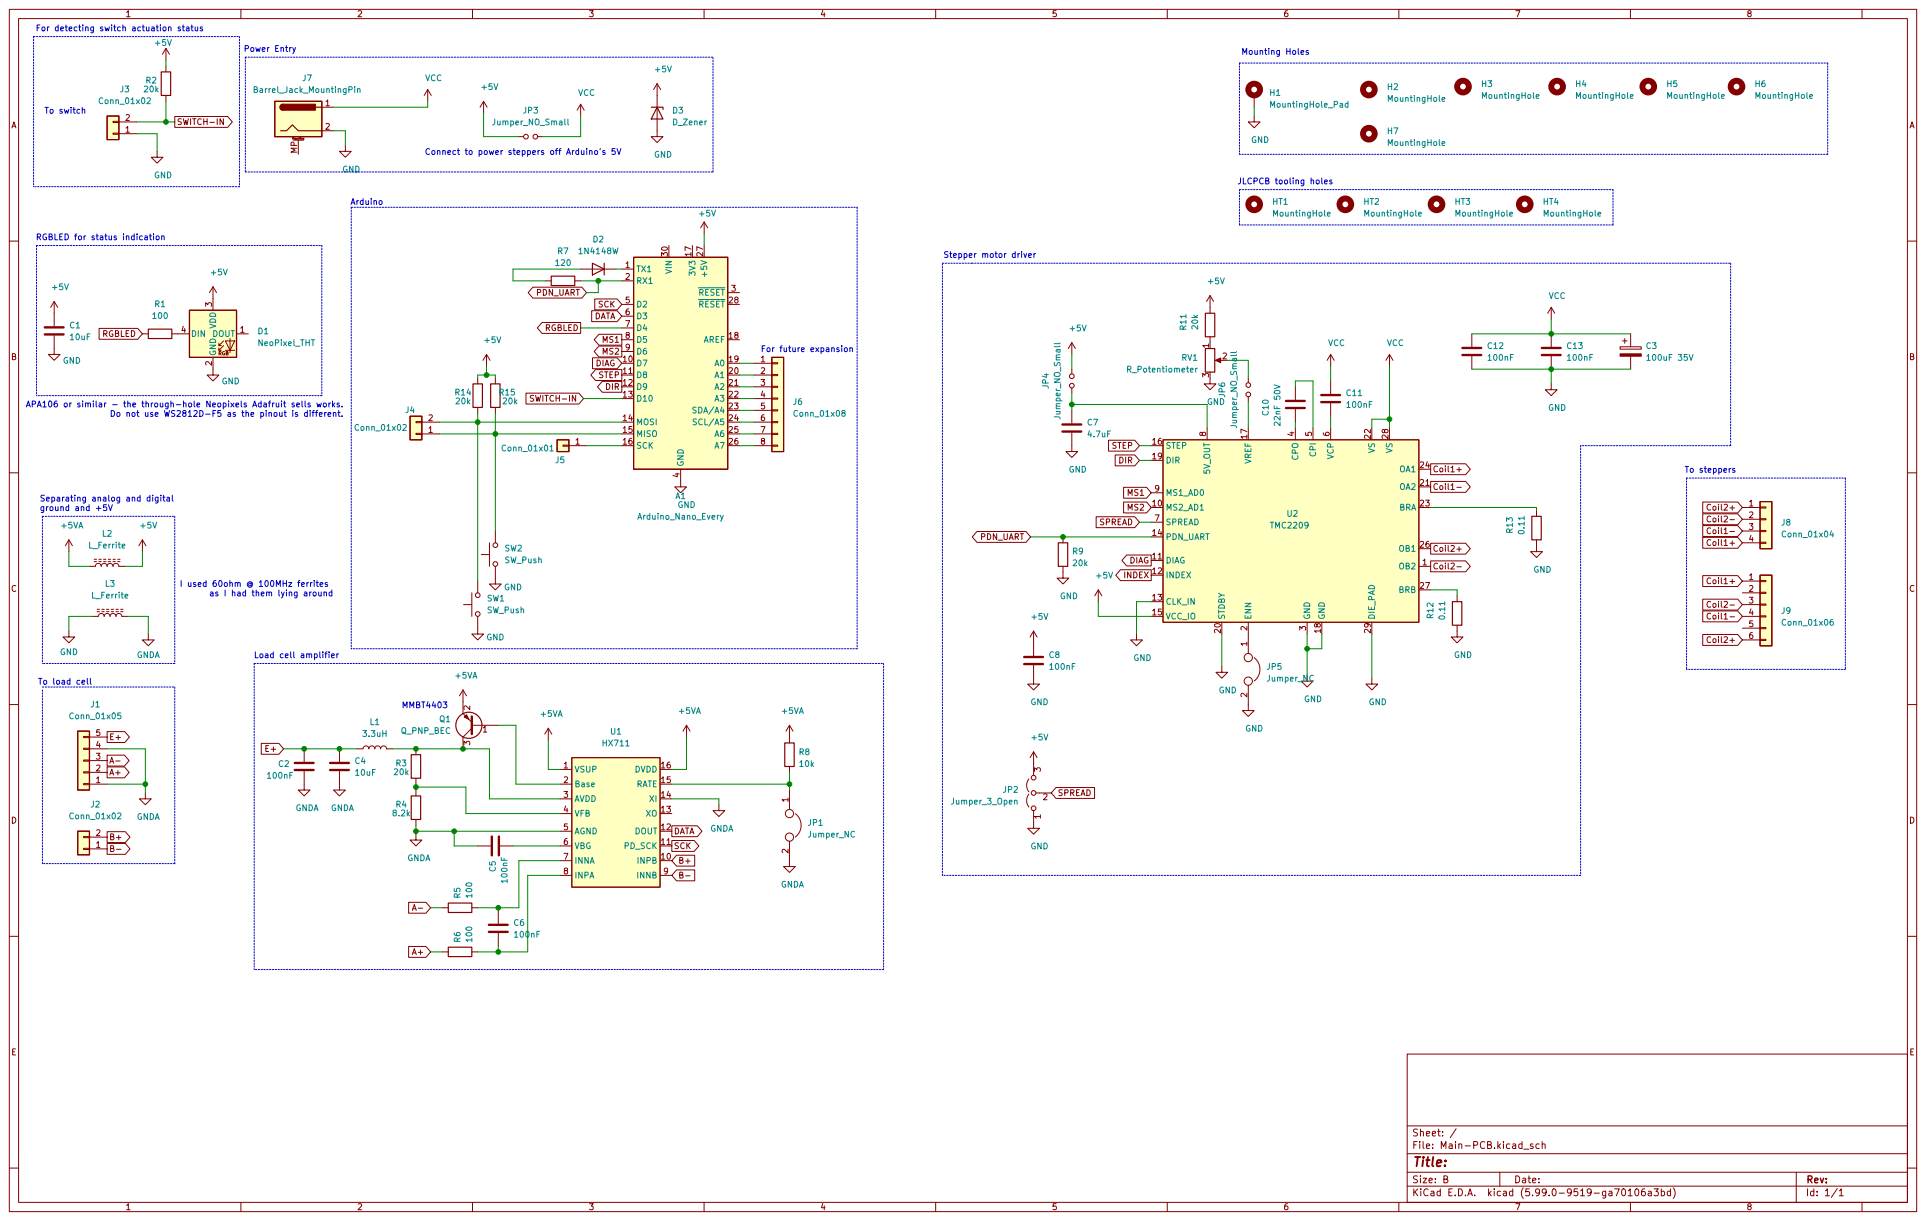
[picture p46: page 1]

Connect to power steppers off Arduino's 5V MMBT4403

VCC

H3MountingHole H4MountingHole

For future expansion RGBLED for status indication To load cell

APA106 or similar - the through-hole Neopixels Adafruit sells works.

Do not use WS2812D-F5 as the pinout is different.

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

Separating analog and digital
ground and +5V
L_Ferrite +5VA

File: Main-PCB.kicad_sch Sheet: / GND GND

I used 60ohm @ 100MHz ferrites as I had them lying around

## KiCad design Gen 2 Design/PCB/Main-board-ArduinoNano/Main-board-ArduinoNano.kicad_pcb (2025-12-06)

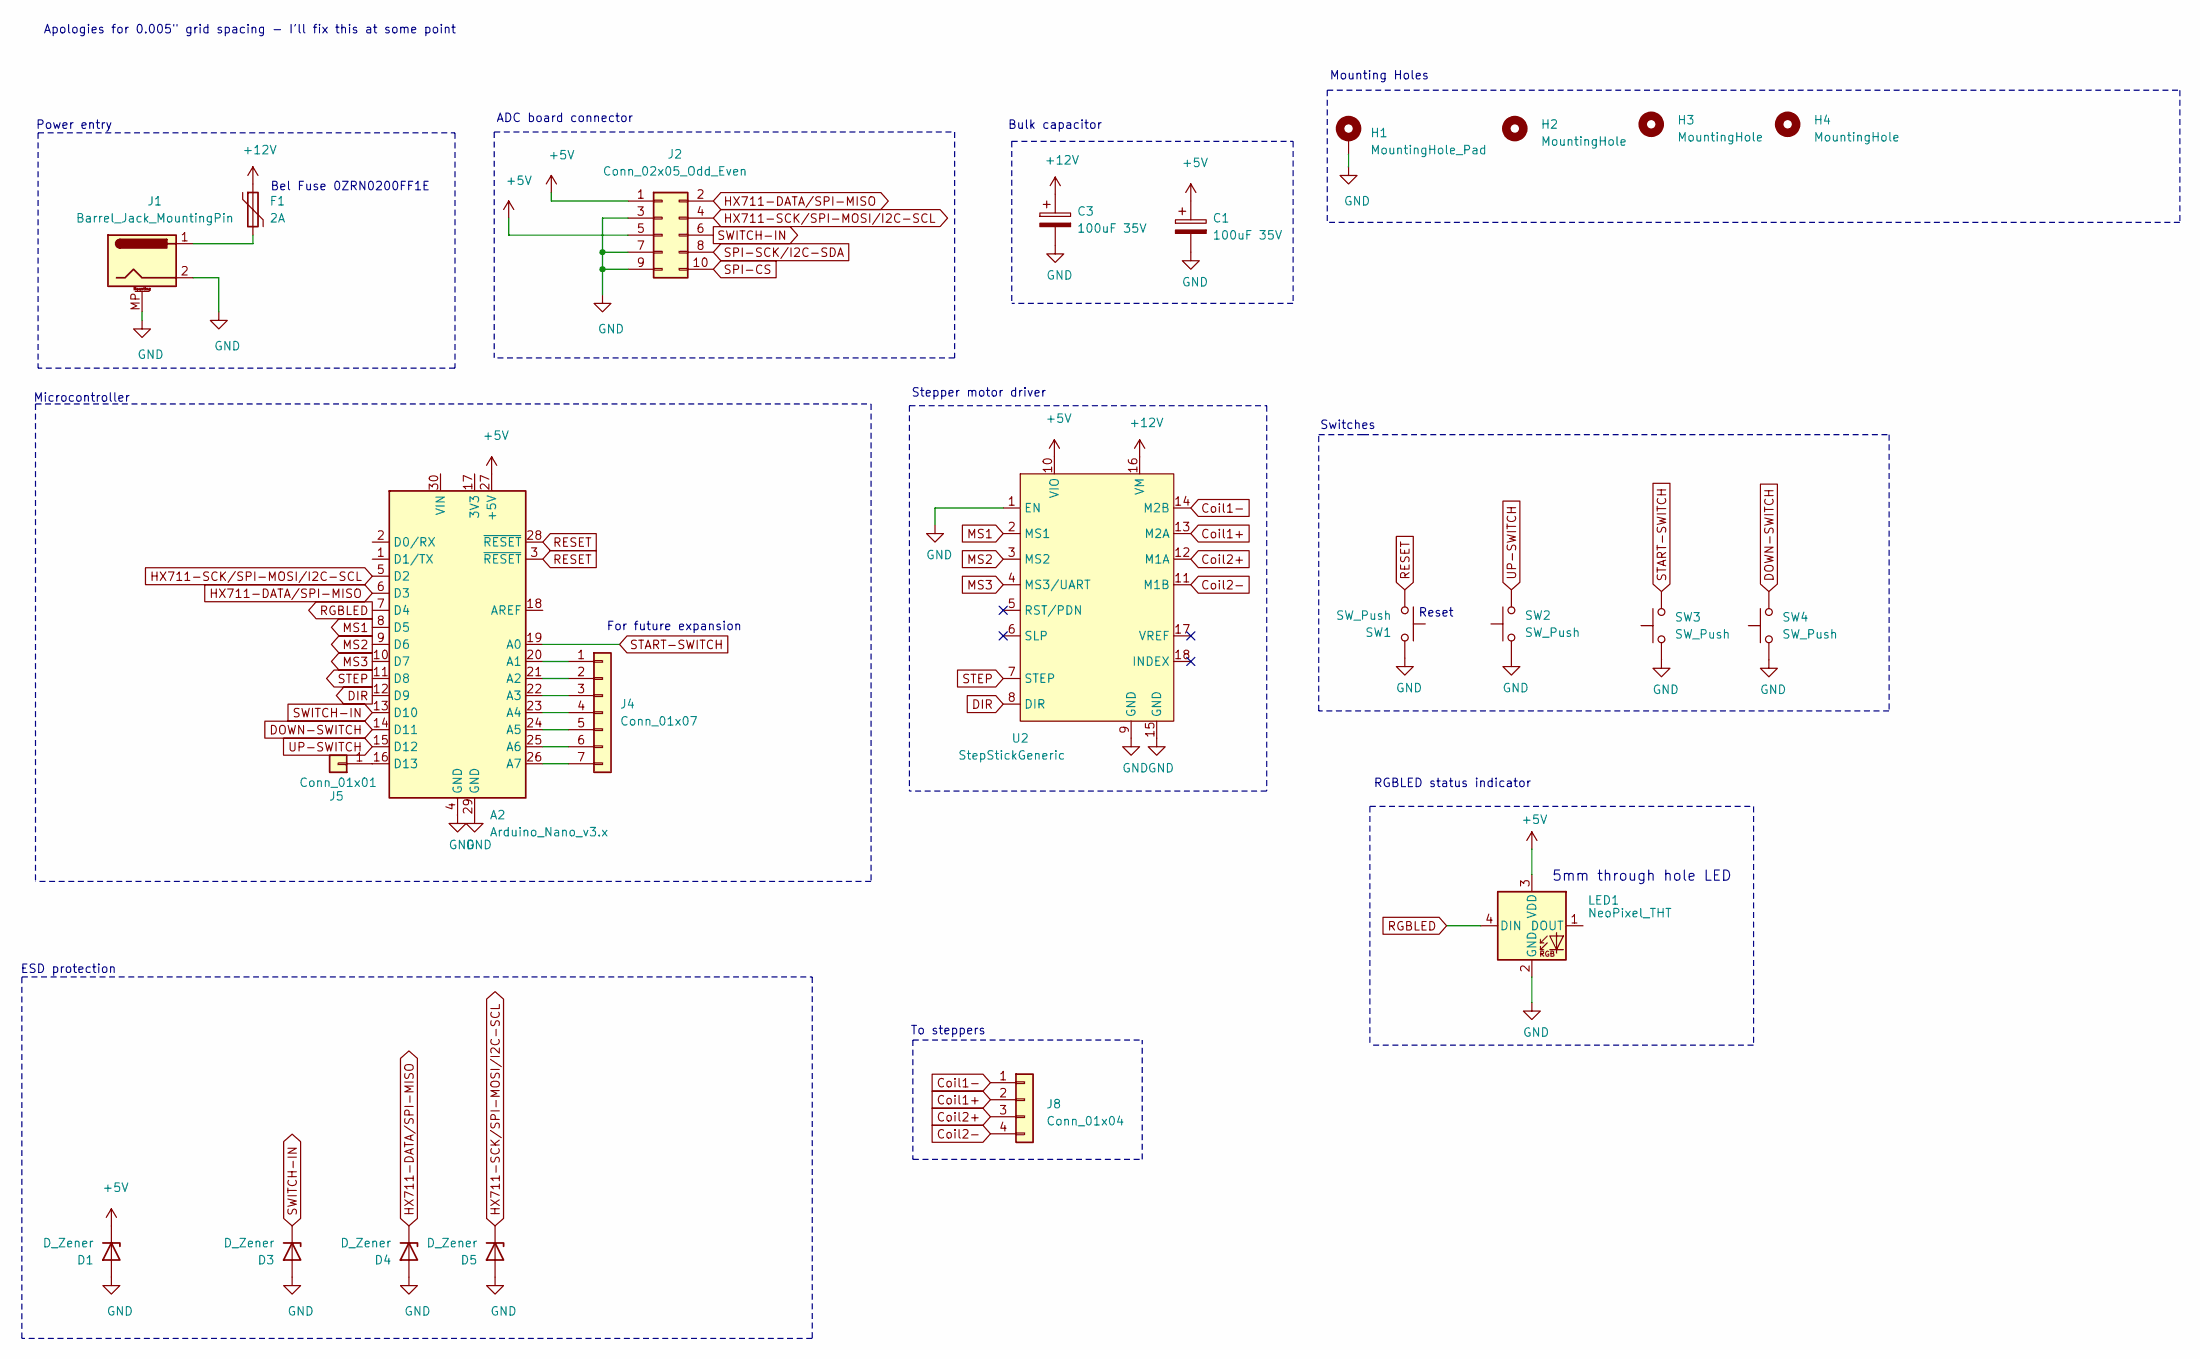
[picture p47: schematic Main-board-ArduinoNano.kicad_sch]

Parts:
A2: Arduino_Nano_v3.x; Arduino_Nano
C1, C3: 100uF 35V; CP_Radial_D8.0mm_P3.50mm
D1, D3, D4, D5: D_Zener; D_DO-41_SOD81_P7.62mm_Horizontal
F1: 2A; C_Disc_D10.5mm_W5.0mm_P5.00mm
H1: MountingHole_Pad; MountingHole_3.2mm_M3_ISO7380_Pad
H2, H3, H4: MountingHole; MountingHole_3.2mm_M3_ISO7380
J1: Barrel_Jack_MountingPin; BarrelJack_Horizontal
J2: Conn_02x05_Odd_Even; 2x05-P2.54mm-Shrouded-Keyed-Header
J4: Conn_01x07; PinSocket_1x07_P2.54mm_Vertical
J5: Conn_01x01; PinSocket_1x01_P2.54mm_Vertical
J8: Conn_01x04; TerminalBlock_Phoenix_MKDS-1,5-4_1x04_P5.00mm_Horizontal
LED1: NeoPixel_THT; LED_D5.0mm-4_RGB
SW1, SW2, SW3, SW4: SW_Push; SW_Cherry_MX_1.00u_PCB
U2: StepStickGeneric

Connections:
+5V: A2.27 (+5V), C1.1, D1.1 (K), J2.1, J2.5, LED1.3 (VDD), U2.10 (VIO)
+12V: C3.1, F1.1, U2.16 (VM)
Coil1+: J8.2, U2.13 (M2A)
Coil1-: J8.1, U2.14 (M2B)
Coil2+: J8.3, U2.12 (M1A)
Coil2-: J8.4, U2.11 (M1B)
DIR: A2.12 (D9), U2.8 (DIR)
DOWN-SWITCH: A2.14 (D11), SW4.2
GND: A2.4 (GND), A2.29 (GND), C1.2, C3.2, D1.2 (A), D3.2 (A), D4.2 (A), D5.2 (A), H1.1, J1.2, J1.MP (MountPin), J2.3, J2.7, J2.9, LED1.2 (GND), SW1.2, SW2.1, SW3.1, SW4.1, U2.1 (EN), U2.9 (GND), U2.15 (GND)
HX711-DATA/SPI-MISO: A2.6 (D3), D4.1 (K), J2.2
HX711-SCK/SPI-MOSI/I2C-SCL: A2.5 (D2), D5.1 (K), J2.4
MS1: A2.8 (D5), U2.2 (MS1)
MS2: A2.9 (D6), U2.3 (MS2)
MS3: A2.10 (D7), U2.4 (MS3/UART)
unnamed: A2.20 (A1), J4.1
unnamed: A2.21 (A2), J4.2
unnamed: A2.22 (A3), J4.3
unnamed: A2.23 (A4), J4.4
unnamed: A2.24 (A5), J4.5
unnamed: A2.25 (A6), J4.6
unnamed: A2.26 (A7), J4.7
unnamed: A2.16 (D13), J5.1
unnamed: F1.2, J1.1
RESET: A2.3 (~RESET), A2.28 (~RESET), SW1.1
RGBLED: A2.7 (D4), LED1.4 (DIN)
SPI-CS: J2.10
SPI-SCK/I2C-SDA: J2.8
START-SWITCH: A2.19 (A0), SW3.2
STEP: A2.11 (D8), U2.7 (STEP)
SWITCH-IN: A2.13 (D10), D3.1 (K), J2.6
UP-SWITCH: A2.15 (D12), SW2.2

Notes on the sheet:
Stepper motor driver
Bulk capacitor
Switches
Bel Fuse 0ZRN0200FF1E‎
Reset
ESD protection
For future expansion
Mounting Holes
Apologies for 0.005" grid spacing - I'll fix this at some point
RGBLED status indicator
To steppers
5mm through hole LED
Microcontroller
ADC board connector
Power entry

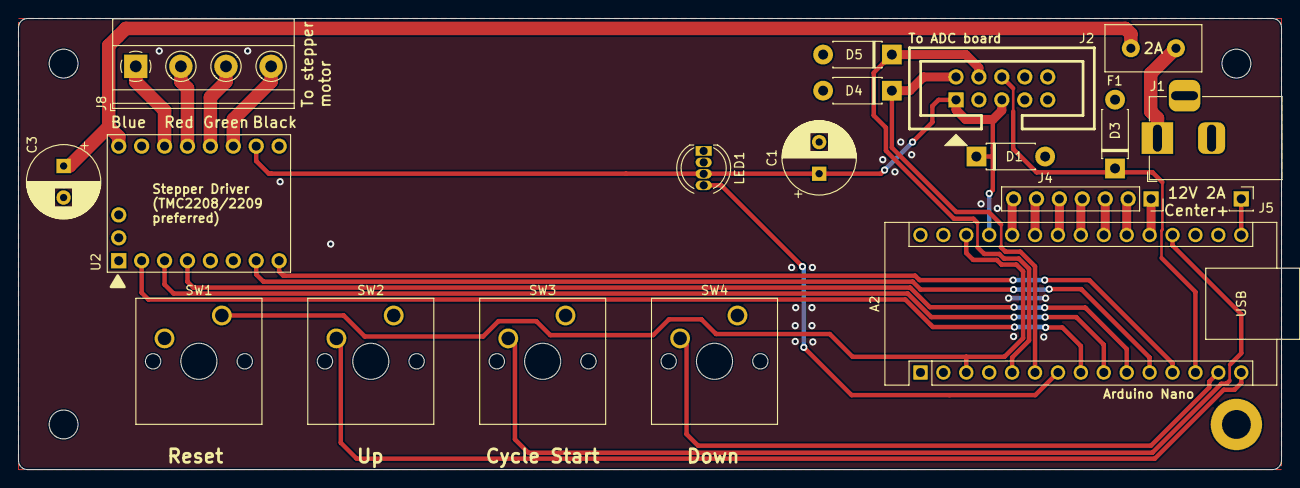
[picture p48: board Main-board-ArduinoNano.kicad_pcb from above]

Board: 2 copper layers, 140.0 x 50.0 mm, 23 parts (0 on the bottom side), 29 nets.

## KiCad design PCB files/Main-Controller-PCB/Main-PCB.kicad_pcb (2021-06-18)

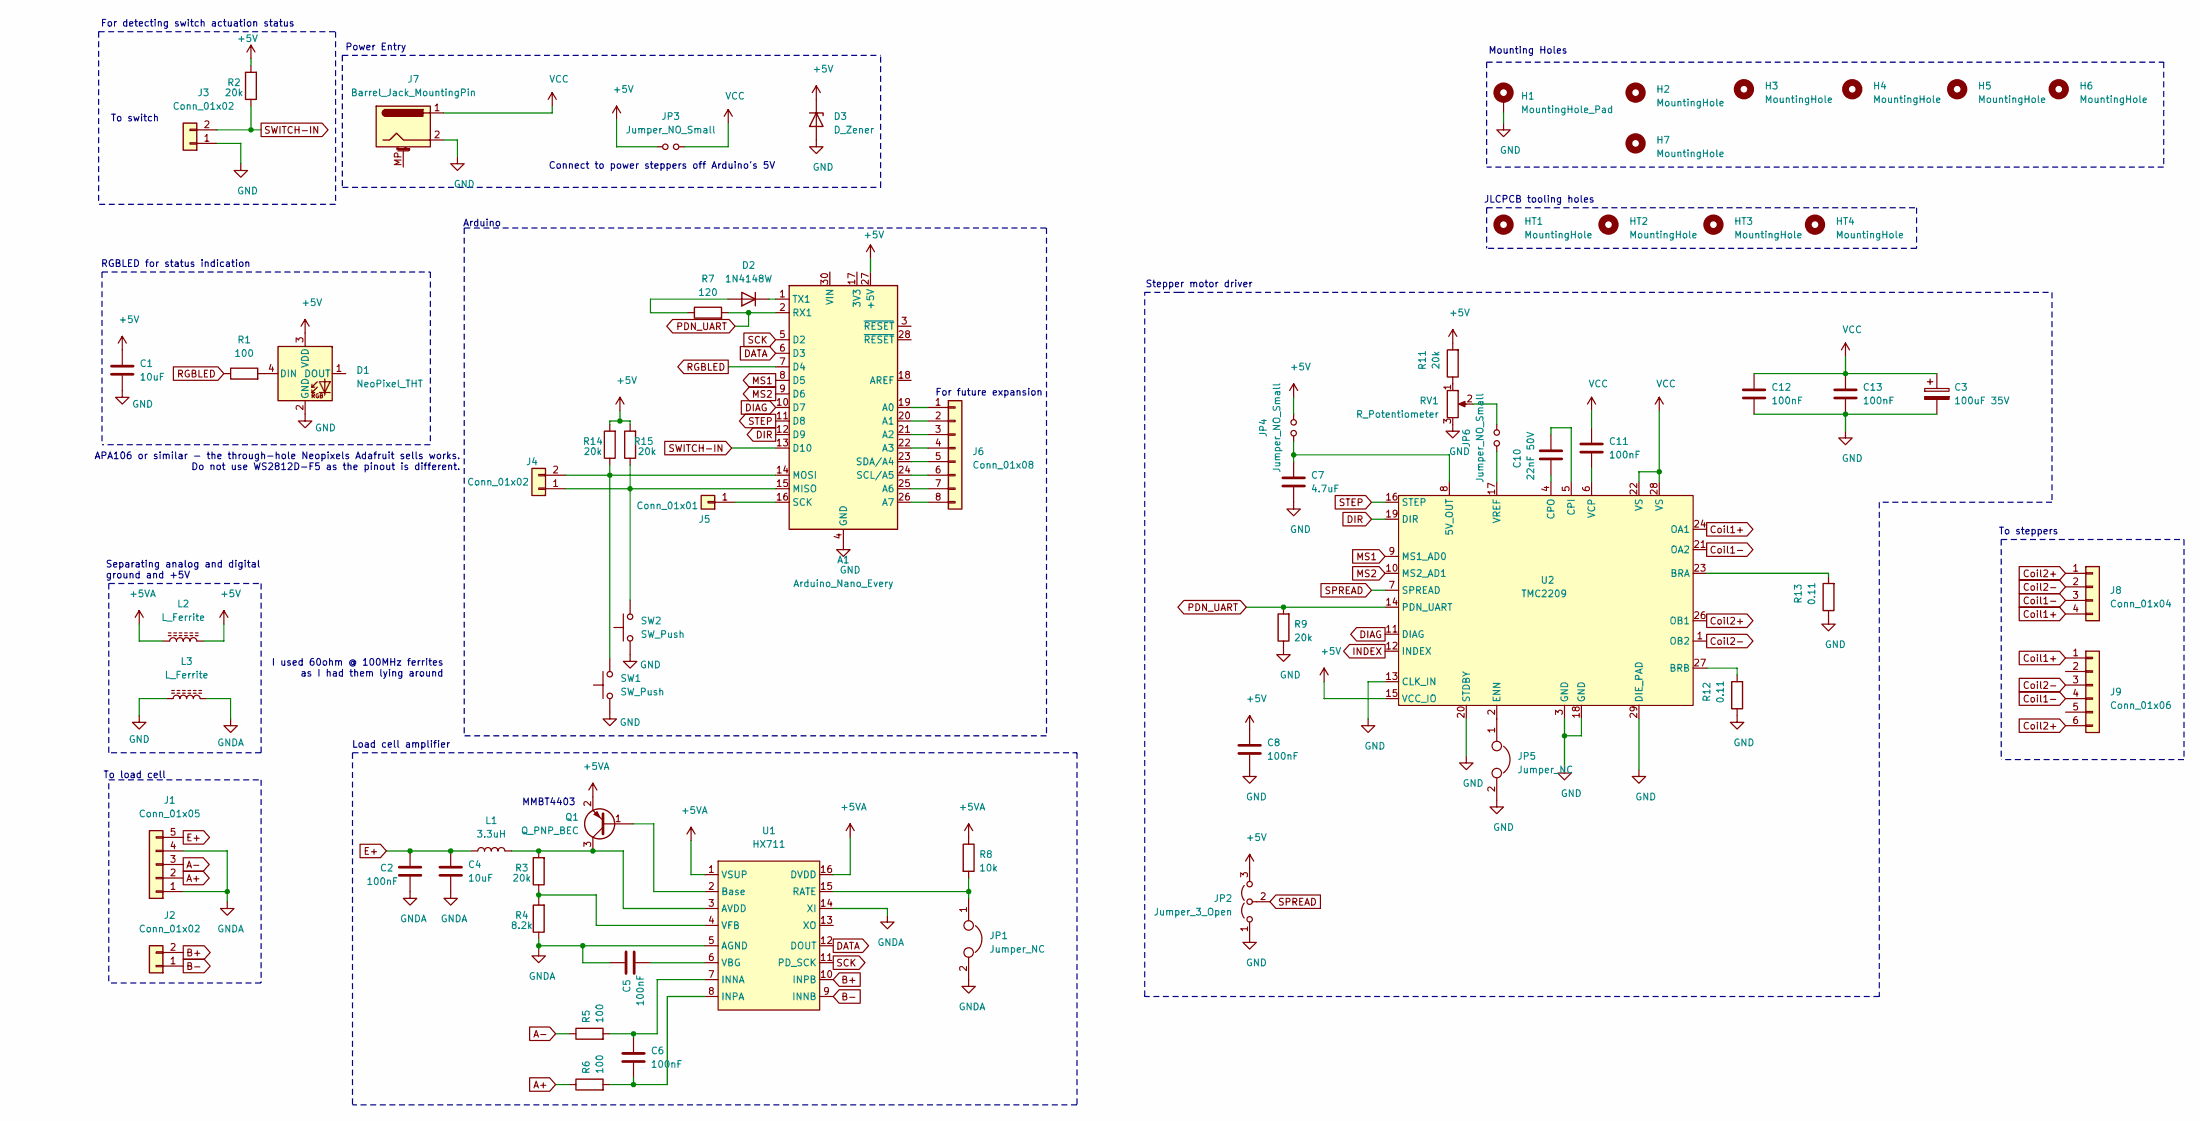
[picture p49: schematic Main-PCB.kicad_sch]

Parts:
A1: Arduino_Nano_Every; Arduino_Nano
C1, C4: 10uF; C_0805_2012Metric_Pad1.18x1.45mm_HandSolder
C2, C5, C6, C8, C11, C12, C13: 100nF; C_0805_2012Metric_Pad1.18x1.45mm_HandSolder
C3: 100uF 35V; CP_Radial_D8.0mm_P3.50mm
C7: 4.7uF; C_0805_2012Metric_Pad1.18x1.45mm_HandSolder
C10: 22nF 50V; C_0805_2012Metric_Pad1.18x1.45mm_HandSolder
D1: NeoPixel_THT; LED_D5.0mm-4_RGB
D2: 1N4148W; D_SOD-123
D3: D_Zener; D_SOD-323
H1: MountingHole_Pad; MountingHole_5.3mm_M5_ISO7380_Pad
H2, H7: MountingHole; MountingHole_5.3mm_M5_ISO7380
H3, H4, H5, H6: MountingHole; MountingHole_3.2mm_M3_ISO7380
HT1, HT2, HT3, HT4: MountingHole; ToolingHole_1.152mm_(for_JLCPCB_SMT)
J1: Conn_01x05; PinSocket_1x05_P2.54mm_Vertical
J2, J3, J4: Conn_01x02; PinSocket_1x02_P2.54mm_Vertical
J5: Conn_01x01; PinSocket_1x01_P2.54mm_Vertical
J6: Conn_01x08; PinSocket_1x08_P2.54mm_Vertical
J7: Barrel_Jack_MountingPin; BarrelJack_Horizontal
J8: Conn_01x04; JST_XH_B4B-XH-A_1x04_P2.50mm_Vertical
J9: Conn_01x06; JST_PH_B6B-PH-K_1x06_P2.00mm_Vertical
JP1, JP5: Jumper_NC; SolderJumper-2_P1.3mm_Bridged_Pad1.0x1.5mm
JP2: Jumper_3_Open; SolderJumper-3_P2.0mm_Open_TrianglePad1.0x1.5mm
JP3, JP4, JP6: Jumper_NO_Small; SolderJumper-2_P1.3mm_Open_TrianglePad1.0x1.5mm
L1: 3.3uH; L_0805_2012Metric_Pad1.15x1.40mm_HandSolder
L2, L3: L_Ferrite; L_0805_2012Metric_Pad1.15x1.40mm_HandSolder
Q1: Q_PNP_BEC; SOT-23_Handsoldering
R1, R5, R6: 100; R_0805_2012Metric_Pad1.20x1.40mm_HandSolder
R2, R3, R9, R11, R14, R15: 20k; R_0805_2012Metric_Pad1.20x1.40mm_HandSolder
R4: 8.2k; R_0805_2012Metric_Pad1.20x1.40mm_HandSolder
R7: 120; R_0805_2012Metric_Pad1.20x1.40mm_HandSolder
R8: 10k; R_0805_2012Metric_Pad1.20x1.40mm_HandSolder
R12, R13: 0.11; R_1206_3216Metric_Pad1.42x1.75mm_HandSolder
RV1: R_Potentiometer; Potentiometer_Runtron_RM-065_Vertical
SW1, SW2: SW_Push; SW_Cherry_MX_1.00u_PCB
U1: HX711; SOP-16_3.9x9.9mm_P1.27mm
U2: TMC2209; QFN-28-1EP_5x5mm_P0.5mm_EP3.35x3.35mm

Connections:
+5V: A1.27 (+5V), C1.1, C8.1, D1.3 (VDD), D3.1 (K), JP2.3 (B), JP3.1, JP4.2, L2.2, R2.2, R11.2, R14.2, R15.2, U2.15 (VCC_IO)
+5VA: L2.1, Q1.2 (E), R8.1, U1.1 (VSUP), U1.16 (DVDD)
A+: J1.2, R6.1
A-: J1.3, R5.1
B+: J2.2, U1.10 (INPB)
B-: J2.1, U1.9 (INNB)
Coil1+: J8.4, J9.1, U2.24 (OA1)
Coil1-: J8.3, J9.4, U2.21 (OA2)
Coil2+: J8.1, J9.6, U2.26 (OB1)
Coil2-: J8.2, J9.3, U2.1 (OB2)
DATA: A1.6 (D3), U1.12 (DOUT)
DIAG: A1.10 (D7), U2.11 (DIAG)
DIR: A1.12 (D9), U2.19 (DIR)
E+: C2.1, C4.1, J1.5, L1.1
GND: A1.4 (GND), A1.29 (GND), C1.2, C3.2, C7.2, C8.2, C12.2, C13.2, D1.2 (GND), D3.2 (A), H1.1, J3.1, J7.2, JP2.1 (A), JP5.2, L3.1, R9.1, R12.1, R13.1, RV1.3, SW1.1, SW2.1, U2.3 (GND), U2.13 (CLK_IN), U2.18 (GND), U2.20 (STDBY), U2.29 (DIE_PAD)
GNDA: C2.2, C4.2, C5.1, J1.1, J1.4, JP1.2, L3.2, R4.1, U1.5 (AGND), U1.14 (XI)
INDEX: U2.12 (INDEX)
MS1: A1.8 (D5), U2.9 (MS1_AD0)
MS2: A1.9 (D6), U2.10 (MS2_AD1)
unnamed: A1.1 (TX1), D2.1 (K)
unnamed: A1.16 (SCK), J5.1
unnamed: A1.19 (A0), J6.1
unnamed: A1.20 (A1), J6.2
unnamed: A1.21 (A2), J6.3
unnamed: A1.22 (A3), J6.4
unnamed: A1.23 (SDA/A4), J6.5
unnamed: A1.24 (SCL/A5), J6.6
unnamed: A1.25 (A6), J6.7
unnamed: C5.2, U1.6 (VBG)
unnamed: C6.1, R5.2, U1.7 (INNA)
unnamed: C6.2, R6.2, U1.8 (INPA)
unnamed: C10.1, U2.4 (CPO)
unnamed: C10.2, U2.5 (CPI)
unnamed: C11.2, U2.6 (VCP)
unnamed: D1.4 (DIN), R1.2
unnamed: D2.2 (A), R7.1
unnamed: A1.26 (A7), J6.8
unnamed: JP1.1, R8.2, U1.15 (RATE)
unnamed: JP6.1, U2.17 (VREF)
unnamed: JP6.2, RV1.2
unnamed: L1.2, Q1.3 (C), R3.2, U1.3 (AVDD)
unnamed: Q1.1 (B), U1.2 (Base)
unnamed: R3.1, R4.2, U1.4 (VFB)
unnamed: R11.1, RV1.1
unnamed: R12.2, U2.27 (BRB)
unnamed: R13.2, U2.23 (BRA)
unnamed: A1.14 (MOSI), J4.2, R14.1, SW1.2
unnamed: A1.15 (MISO), J4.1, R15.1, SW2.2
unnamed: JP5.1, U2.2 (ENN)
unnamed: C7.1, JP4.1, U2.8 (5V_OUT)
PDN_UART: A1.2 (RX1), R7.2, R9.2, U2.14 (PDN_UART)
RGBLED: A1.7 (D4), R1.1
SCK: A1.5 (D2), U1.11 (PD_SCK)
SPREAD: JP2.2 (C), U2.7 (SPREAD)
STEP: A1.11 (D8), U2.16 (STEP)
SWITCH-IN: A1.13 (D10), J3.2, R2.1
VCC: C3.1, C11.1, C12.1, C13.1, J7.1, JP3.2, U2.22 (VS), U2.28 (VS)

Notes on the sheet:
Separating analog and digital ground and +5V
To switch
To load cell
RGBLED for status indication
For detecting switch actuation status
Power Entry
I used 60ohm @ 100MHz ferrites as I had them lying around
Load cell amplifier
APA106 or similar - the through-hole Neopixels Adafruit sells works. Do not use WS2812D-F5 as the pinout is different.
Arduino
MMBT4403
Connect to power steppers off Arduino's 5V
For future expansion
Stepper motor driver
Mounting Holes
JLCPCB tooling holes
To steppers

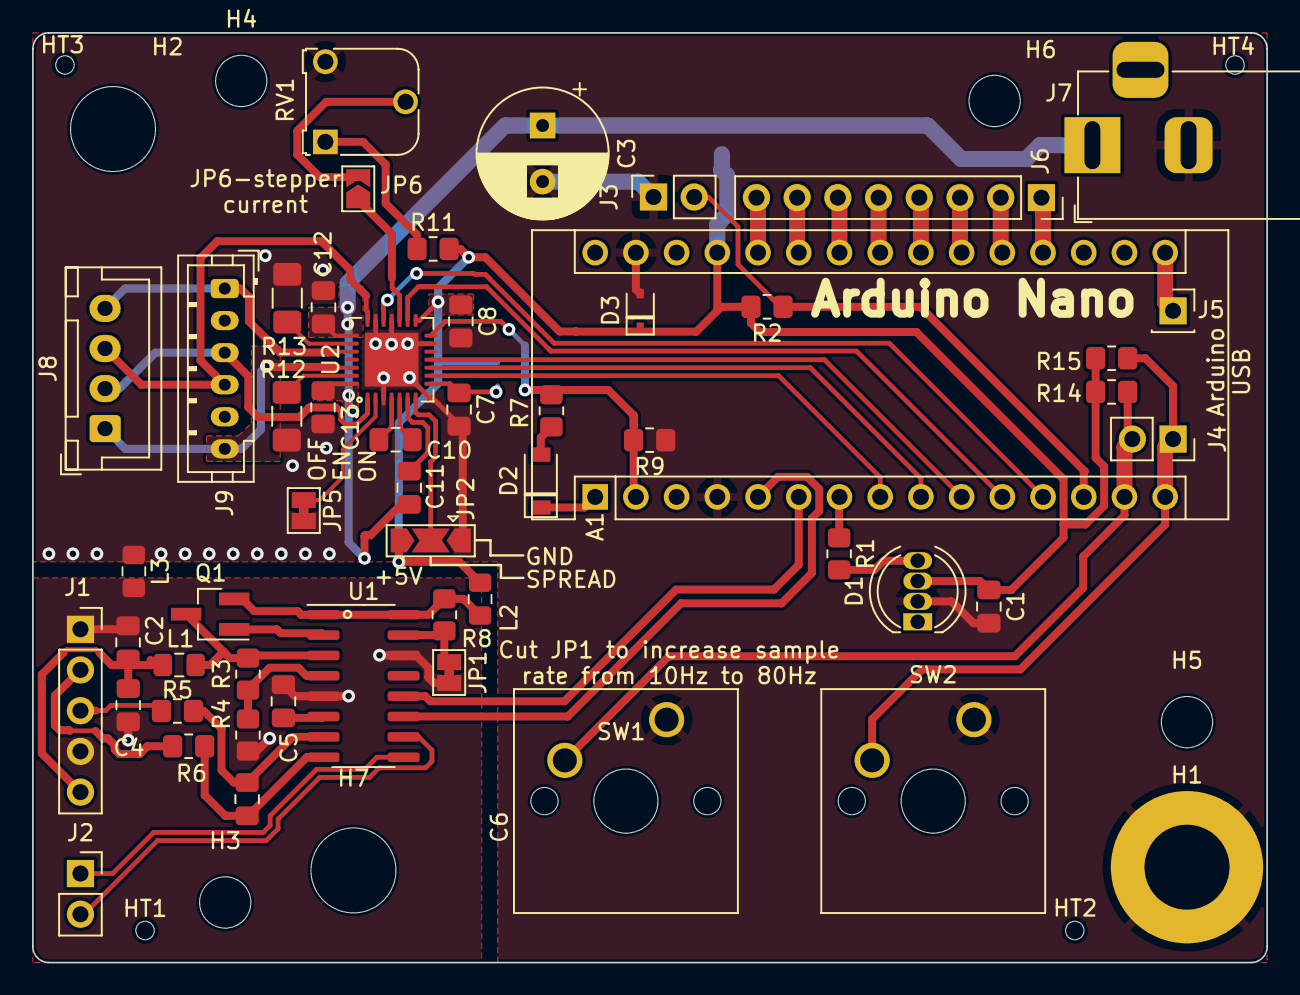
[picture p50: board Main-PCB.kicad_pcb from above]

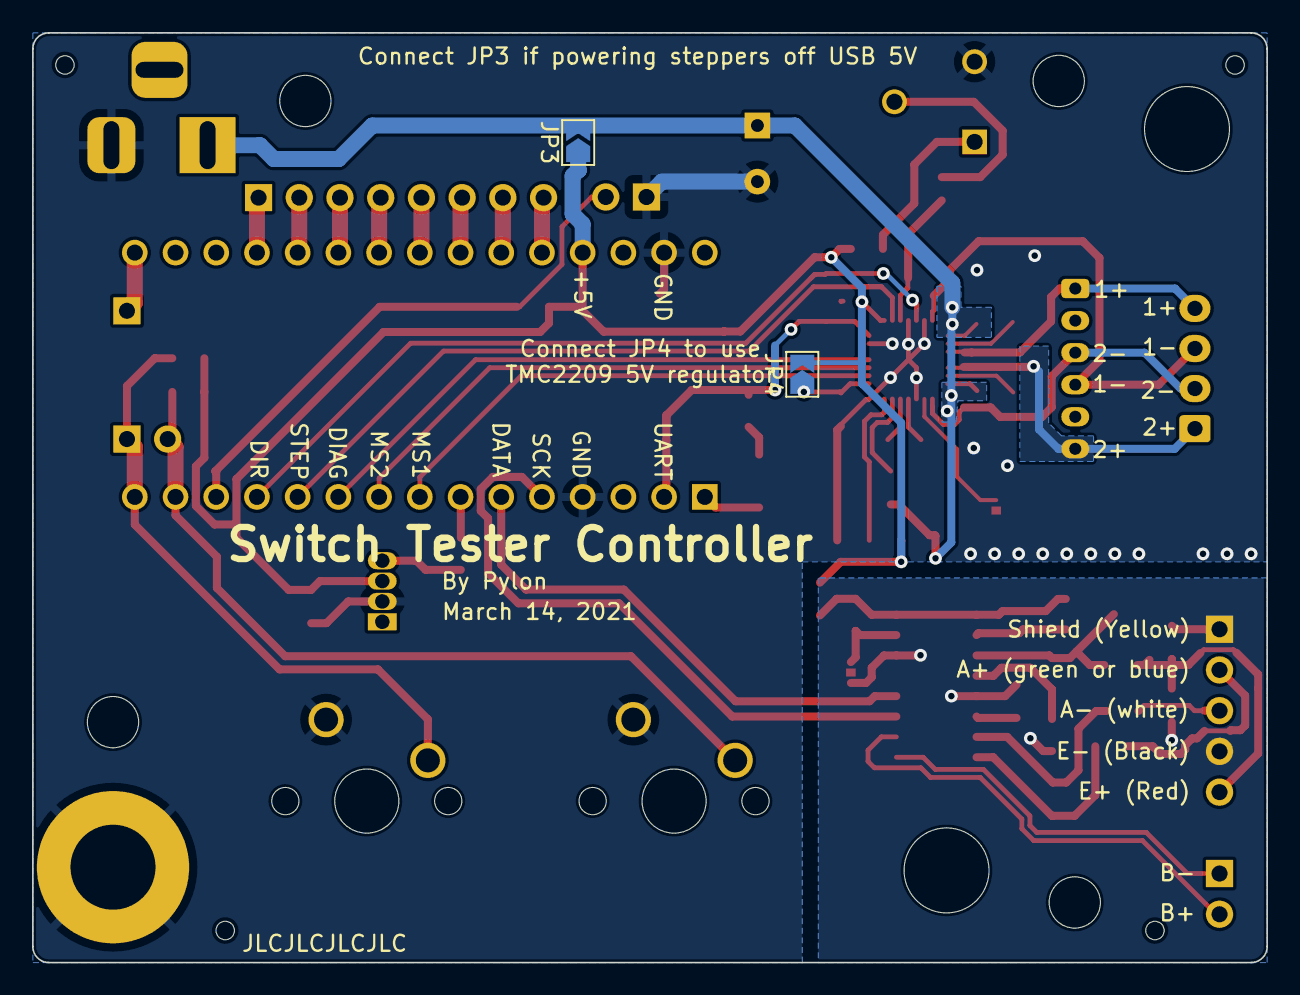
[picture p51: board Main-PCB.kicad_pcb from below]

Board: 2 copper layers, 77.0 x 58.0 mm, 65 parts (2 on the bottom side), 56 nets.

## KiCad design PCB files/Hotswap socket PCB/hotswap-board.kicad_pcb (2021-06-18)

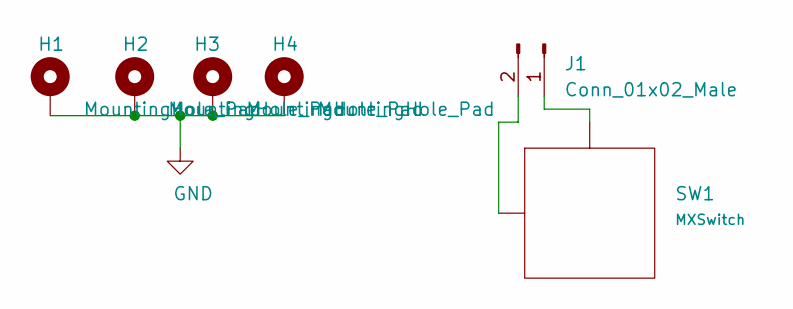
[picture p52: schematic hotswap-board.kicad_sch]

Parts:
H1, H2, H3, H4: MountingHole_Pad; MountingHole_3.2mm_M3_ISO7380_Pad
J1: Conn_01x02_Male; PinHeader_2x01_P2.54mm_Vertical
SW1: MXSwitch; MX100H

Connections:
GND: H1.1, H2.1, H3.1, H4.1
unnamed: J1.1, SW1.2 (Row)
unnamed: J1.2, SW1.1 (Col)

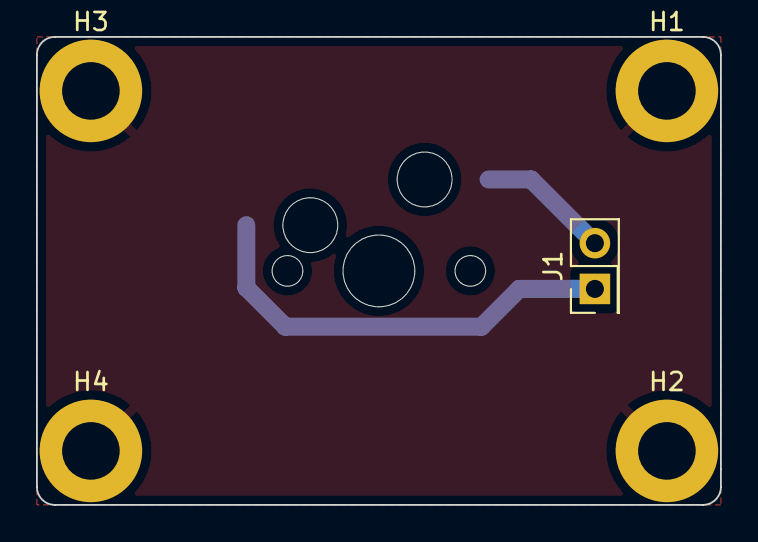
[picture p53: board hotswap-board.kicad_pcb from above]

Board: 2 copper layers, 38.0 x 26.0 mm, 6 parts (1 on the bottom side), 3 nets.

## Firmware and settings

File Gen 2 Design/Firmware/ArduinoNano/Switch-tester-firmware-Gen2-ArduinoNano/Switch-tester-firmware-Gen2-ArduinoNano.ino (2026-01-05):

#include <HX711.h>
#include <Adafruit_NeoPixel.h>

/*
   Load cell calibration parameters - these need to be calibrated frequently
   These parameters convert the raw ADC readings from the HX711 chip into a gram-force reading
   The load cell amplifier output is linear, and follow the form y = mx+b, with y being the force reading in gram-force, m being 1/Units_per_gram (so grams-per-unit),  x being the raw ADC reading, and b being the the variable Zero_intercept
   These are found by doing a 2-point calibration - one with no load on the load cell, and the other with a known load on the load cell
*/
float Units_per_gram = 3100.852;
float Zero_intercept  = -28.263;

/*This is the force reading at which the switch curve tester reverses, in gf. You may wish to increase this for switches with very high bottom out weights, but be aware of what your load cell can physically handle! The default TAL221 load cell used is only good for 500gf (with an absolute maximum of 750gf - the load cell will be permanently damaged if you exceed this)*/
float Reverse_limit = 110.0; //in gram-force

/*This is how long to wait between successive measurements, in ms. 15ms delay for 80Hz mode on the HX711, 110ms delay for 10hz mode on the HX711  */
#define Delay 15 //

/*RGBLED parameters - there is a single RGBLED for status indication*/
#define RGB_pin 4
#define N_LEDs 1
Adafruit_NeoPixel LED = Adafruit_NeoPixel(N_LEDs, RGB_pin);

/*Load cell amplifier (Avia HX711) pins */
#define Data_pin 3
#define SCK_pin 2

/*Stepper motor and stepper motor driver parameters - we are using a Trinamic TMC2209 driver with STEP/DIR control */
#define DIR_pin 9 //HIGH = away from load cell, LOW = toward
#define STEP_pin 8
#define MS1 5 //used to set microstepping 
#define MS2 6 //used to set microstepping
#define MS3 7 //used to set microstepping
#define R_SENSE 0.11f
#define Steps_per_loop 8 //This is the number of steps to advance per measurement loop cycle
#define Microns_per_loop 5 //This is how much the leadscrew advances per measurement loop cycle - this will vary depending on your stepper motor, microstepping, and leadscrew lead
#define Step_time 120 //How long to wait, in us, after the STEP signal goes high to go back low, and after it goes low to go back up high. Basically the length of the pulse in us 

//Pin assignments for the 3 control buttons
#define Up_switch 12
#define Down_switch 11
#define Start_switch A0

//Pin that is used to see if the switch is actuated
#define Switch_pin 10

/*Declaration of various variables */
long Raw_reading; //raw ADC reading
float Reading_gf; //ADC reading converted to gf
HX711 Load_cell; //Load cell object, using the HX711 library
long int Position; //in microns
bool Actuated; //whether the switch is actuated or not. True = actuated, False = not actuated
bool Reverse; //this becomes true when the force reading on the load cell reaches a defined value, and initiates the reverse cycle (to measure the upstroke and avoid load cell damage)
bool Start_button_pressed; //this becomes true if the Start button is pressed - used to initiate the test cycle
bool Returned_to_start; //becomes true at the end of the cycle

void setup() {
  // put your setup code here, to run once:

  //set various variables
  Reverse = false;
  Position = 0;
  Start_button_pressed = false;
  Returned_to_start = false;
  Actuated = false;

  Serial.begin(9600);

  //Load-cell setup
  Load_cell.begin(Data_pin, SCK_pin);

  //RGBLED setup
  LED.begin();
  LED.setPixelColor(0, 128, 128, 128); //white for the Setup state
  LED.show();

  //set microstepping (see Section 3.4 in the TMC2208/2209 datasheet - MS1 and MS2 both being low means microstepping set to 8). May need to change if using other stepper motor drivers;
  pinMode(MS1, OUTPUT);
  pinMode(MS2, OUTPUT);
  pinMode(MS3, OUTPUT);
  digitalWrite(MS1, LOW);
  digitalWrite(MS2, LOW);
  digitalWrite(MS3, LOW);

  pinMode(STEP_pin, OUTPUT);
  pinMode(DIR_pin, OUTPUT);

  //set switch actuation pin
  pinMode(Switch_pin, INPUT_PULLUP);

  //set buttons
  pinMode(Up_switch, INPUT_PULLUP);
  pinMode(Start_switch, INPUT_PULLUP);
  pinMode(Down_switch, INPUT_PULLUP);

}
//Function for sending stepper commands
void Drive_stepper(int steps, bool dir) { //Direction - false = toward load cell, //true = away from load cell
  if (dir) {
    digitalWrite(DIR_pin, LOW);
  }

  else {
    digitalWrite(DIR_pin, HIGH);
  }

  while (steps > 0) {
    digitalWrite(STEP_pin, HIGH);
    delayMicroseconds(Step_time);
    digitalWrite(STEP_pin, LOW);
    delayMicroseconds(Step_time);
    steps--;
  }
}

void loop() {

  while (Start_button_pressed) { //If the start button is pressed, then the measurement begins. This is the measurement cycle. 
    
    // Step 1) Read the load cell 
    if (Load_cell.is_ready()) { //If the load cell is ready - read the load cell 
      Raw_reading = Load_cell.read();
      Reading_gf = (((float(Raw_reading)) / Units_per_gram)) - Zero_intercept ; //convert to gf
      while (Reading_gf < -30.0) { //This is to throw out HX711 errors, which frequently manifest as extremely negative readings 
        delayMicroseconds(Delay * 5); //wait a bit so the error (hopefully) clears
        Raw_reading = Load_cell.read();
        Reading_gf = (((float(Raw_reading)) / Units_per_gram)) - Zero_intercept ;
      }
    }

    else { //if the load cell is not ready - wait a bit
      delay(Delay * 5); //wait a bit so the error clears
      while (Reading_gf < -30.0) { //This is to throw out HX711 errors, which frequently manifest as extremely negative readings 
        delayMicroseconds(Delay * 5);  //wait a bit so the HX711 error (hopefully) clears
        Raw_reading = Load_cell.read();
        Reading_gf = (((float(Raw_reading)) / Units_per_gram)) - Zero_intercept ;
      }
    }

    // Step 2) check if load cell reversed limit (as set by the variable Reverse_limit) is reached. If it has been, initiate the reverse cycle 
    if (Reading_gf > Reverse_limit) {
      Reverse = true;
      LED.setPixelColor(0, 128, 128, 0); //change indicator LED color for the reverse cycle
      LED.show();
    }

    // Step 3) Check if the switch is actuated 
    Actuated = !digitalRead(Switch_pin); 

    // Step 4a) - If Reverse_limit has not been reached, move switch towards the load cell: 
    if (Reverse == false) {
      //Steo 4a1) Advance towards the load cell (this is 8 microsteps, or one whole step)
      Drive_stepper(Steps_per_loop, 0);

      //Step 4a2) - Report the logged position, measured force, and switch actuation status over Serial Monitor 
      Serial.print(Position);
      Serial.print(", ");
      Serial.print(Reading_gf);
      Serial.print(",");
      Serial.print(Actuated);
      Serial.print("\n");

      //Step 4a3) - Keep track of position by updating it 
      Position = Position + Microns_per_loop; 
    }

    // Step 4b) - If Reverse_limit has been reached, move switch away from the load cell back to the start position 
    if (Reverse & (Position > 0) ) {
      //Step 4b1) - Advance away from the load cell (this is 8 microsteps, or one whole step)
      Drive_stepper(Steps_per_loop, 1); 
      Position = Position - Microns_per_loop;

      //Steo 4b2 - check to see if we've returned to the start position - if so, exit the while loop. Our measurement is done. 
      if (Position == 0) { 
        Start_button_pressed = false; //Exit the measurement 
        Returned_to_start = true;
        LED.setPixelColor(0, 128, 256, 0); //Orange - once the measurement is done, the LED is yellow. Press the reset button on the Arduino if you want to start a new measurement. 
        LED.show();
      }

     //Step 4b3 - Report the logged position, measured force, and switch actuation status over Serial Monitor 
      Serial.print(Position);
      Serial.print(", ");
      Serial.print(Reading_gf);
      Serial.print(",");
      Serial.print(Actuated);
      Serial.print("\n");

    }

    delay(Delay); //wait between measurement loop cycles. This is determined by the HX711 load cell amplifier speed (it's set to either 10Hz or 80Hz) 

  }

  if (!digitalRead(Start_switch)) { //press Start button to initiate the measurement
    Serial.print("Raw X (microns),Raw Force (gf),Actuated?"); //Print this initially on the first line of the Serial Monitor - this is needed to label t he data for the processing Python script 
    Serial.print("\n");
    Start_button_pressed = true;
    LED.setPixelColor(0, 128, 0, 0); //green - LED is green over the course of the measurement
    LED.show();
  }

  /*This is used to move the carriage before and after the measurement 
   * */
  if (!digitalRead(Up_switch)) {

    //Read load cell - for overload protection to avoid running the switch into the load cell and damaging it 
    if (Load_cell.is_ready()) {
      Raw_reading = Load_cell.read();
      Reading_gf = (((float(Raw_reading)) / Units_per_gram)) - Zero_intercept ;
    }

    if (Reading_gf < Reverse_limit) { //if the load cell reading does not exceeds the Reverse_limit - move towards the load cell 
        Drive_stepper(Steps_per_loop, 0);
      }


    }

  if (!digitalRead(Down_switch)) {
    Drive_stepper(Steps_per_loop, 1);
  }

}

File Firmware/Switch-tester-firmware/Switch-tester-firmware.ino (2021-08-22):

#include <HX711.h>
#include <TMCStepper.h>
#include <TMCStepper_UTILITY.h>
#include <Adafruit_NeoPixel.h>

//RGBLED - there is a single RGBLED for status indication
#define RGB_pin 4
#define N_LEDs 1

Adafruit_NeoPixel LED = Adafruit_NeoPixel(N_LEDs, RGB_pin);

//Load cell + amplifier - using Avia HX711
#define Data_pin 3
#define SCK_pin 2
float Units_per_gram = 3174.931; //measured from calibration step
float Zero = 45.166; //measured no load weight, in gf

long Raw_reading;
float Reading_g;
HX711 Load_cell;
float Reverse_limit = 110.0; //This is the force reading at which the switch curve tester reverses, in  gf. You may wish to increase this for switches with very high bottom out weights, but be aware of what your load cell can physically handle! 

//stepper motor driver - using Trinamic TMC2209 using STEP/DIR control 
#define DIR_pin 9 //HIGH = away from load cell, LOW = toward
#define STEP_pin 8
#define MS1 5 //used to set microstepping 
#define MS2 6 //used to set microstepping
#define R_SENSE 0.11f

#define Steps_per_loop 8 //This is the number of steps per loop cycle
#define Microns_per_loop 5 //This is how much the leadscrew advances per loop cycle - this will vary depending on your stepper motor, microstepping, and leadscrew lead
//int Reverse_steps = 40000;

//#define Backlash 10 
long int Position; //in microns

//control buttons
#define Left_switch 11
#define Right_switch 12

//keep track of switch actuation
#define Switch_pin 10
bool Actuated;

//other
bool Reverse; //this becomes true when the force reading on the load cell reaches a defined value, and initiates the reverse cycle  (to avoid load cell damage)
bool Button_pressed; //this becomes true if the left button is pressed - used to initiate the test cycle
bool Returned_to_start; //becomes true at the end of the cycle 

void setup() {
  // put your setup code here, to run once:

  Reverse = false;
  Position = 0;
  
  Serial.begin(9600);
  //Serial.println("Test!");

  //Load-cell setup
  Load_cell.begin(Data_pin, SCK_pin);
 
  //RGBLED setup
  LED.begin();
  LED.setPixelColor(0, 128, 128, 128); //white
  LED.show();

  //set microstepping (see Section 3.4 in the TMC2209 datasheet - MS1 and MS2 both being low means microstepping set to 8);
  pinMode(MS1,OUTPUT);
  pinMode(MS2,OUTPUT);
  digitalWrite(MS1,LOW);
  digitalWrite(MS2,LOW);

  pinMode(STEP_pin, OUTPUT);
  pinMode(DIR_pin, OUTPUT);

  //switch actuation
  pinMode(Switch_pin, INPUT);

  //buttons
  pinMode(Left_switch, INPUT);
  pinMode(Right_switch, INPUT);

  Button_pressed = false;
  Returned_to_start=false;
  Actuated = false;
  
}

void Drive_stepper(int steps, bool dir) { //Direction - false = toward, //true = away
  if(dir) {
    digitalWrite(DIR_pin, HIGH);
  }

  else {
    digitalWrite(DIR_pin, LOW);
  }

  while(steps>0){
    digitalWrite(STEP_pin, HIGH);
    delayMicroseconds(120);
    digitalWrite(STEP_pin, LOW);
    delayMicroseconds(120);
    steps--;
  }
}
  
  
void loop() {
  while(Button_pressed) { 

    //read load cell
    if(Load_cell.is_ready()){
        Raw_reading = Load_cell.read();
        Reading_g = (((float(Raw_reading))/Units_per_gram))-Zero;
        if(Reading_g<-30.0) { //if HX711 error - read the load cell again
          delayMicroseconds(300);
                  Raw_reading = Load_cell.read();
                  Reading_g = (((float(Raw_reading))/Units_per_gram))-Zero;
        }
    }

    //check if load cell limit reached, initiates reverse otherwise
    if(Reading_g>Reverse_limit) {
      Reverse = true;
      LED.setPixelColor(0, 0, 255, 0);
      LED.show();
    }

    Actuated = !digitalRead(Switch_pin);


    //Advabce towards the load cell 
    if(Reverse==false) {
      //Advance towards the load cell 8 steps 
      Drive_stepper(Steps_per_loop,0);
      Serial.print(Position);
      Serial.print(", ");
      Serial.print(Reading_g);
      Serial.print(",");
      Serial.print(Actuated);
      Serial.print("\n");
      
      Position = Position + Microns_per_loop; //track position
    }
    
    //return to start position
    if(Reverse & (Position >0) ) {
        Drive_stepper(Steps_per_loop,1);
        Position = Position - Microns_per_loop;
        if(Position==0) { //End of cycle, exit the while loop 
            Button_pressed = false;
            Returned_to_start = true;
            LED.setPixelColor(0, 128, 128, 0);
            LED.show();
        }
          Serial.print(Position);
          Serial.print(", ");
          Serial.print(Reading_g);
          Serial.print(",");
          Serial.print(Actuated);
          Serial.print("\n");
          
    }



    delay(140); //HX711 can only read ~10Hz, so 140ms delay between loops 

  }

  if(!digitalRead(Left_switch)) { //press left button to start test cycle
    Button_pressed = true;
    LED.setPixelColor(0, 128, 0, 0); //green
    LED.show();
  }

//Used to move the carriage before and after teh test cycle
//before test cycle - press right button to move carriage closer to load cell. 
//After test cycle - press right button to move carriage away from load cell
  if(!digitalRead(Right_switch)) {

    //read load cell for overload protection
    if(Load_cell.is_ready()){
        Raw_reading = Load_cell.read();
        Reading_g = (((float(Raw_reading))/Units_per_gram))-Zero;        
    }

    if(Reading_g < 250) {
      if(Returned_to_start) {
        
        Drive_stepper(Steps_per_loop,1);
      }
      
      else {
        Drive_stepper(Steps_per_loop,0);
      }
    }
  }



//this does not really work right now - I should probably place it in the while loop
  /*
  if(Reverse==false){
    LED.setPixelColor(0, 128, 128, 128);
    LED.show();
  }

  if(Reverse){
     LED.setPixelColor(0, 0, 255, 0);
     LED.show();
  }
    
 
*/

/*
//manual controls
  if(!digitalRead(Left_switch)) {
     LED.setPixelColor(0, 0, 128, 0);
     LED.show();
     digitalWrite(DIR_pin, HIGH);
     digitalWrite(STEP_pin, HIGH);
     delayMicroseconds(50);
     digitalWrite(STEP_pin, LOW);
     delayMicroseconds(50);
     //delay(1);
  }
  
  else if(!digitalRead(Right_switch )) {
     LED.setPixelColor(0, 128, 0, 0);
     LED.show();
     digitalWrite(DIR_pin, LOW);
     digitalWrite(STEP_pin, HIGH);
     delayMicroseconds(50);
     digitalWrite(STEP_pin, LOW);
     delayMicroseconds(50);
     //delay(1);
  }
*/

  
/*
  for (int i = 1000; i>0; i--) {
    digitalWrite(DIR_pin, HIGH);
    delayMicroseconds(160);
    digitalWrite(DIR_pin, LOW);
    delayMicroseconds(160);
  }
 */


}

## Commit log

2021-06-18 Wiping commit history
    [-B_Cu.gbr, -B_Mask.gbr, -B_Paste.gbr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]
2021-06-20 Added Polia stem in Zealio housing with Cherry top
    [Kailh-Polia-Stem-Zealio-V2-Bottom-Cherry-Top.ods, Polia-Stem-Zealio-V2-Bottom-Cherry-Top.ods]
2021-06-25 Added U4T vs Polia vs Halo stem
    [KTT-Strawberry.ods, Polia-vs-Halo-vs-U4T-in-Boba.ods]
2021-06-25 Added Tecsee Blue Velvet linear stem in JWK Lavender housing
    [Tecsee-Blue-Velvet-Stem-In-JWK-Lavender.ods]
2021-07-03 Added several switches
    [Gateron-Cap-Yellow.ods, Gateron-Ink-Yellow.ods, Gazzew-Bobagum-52g.ods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]
2021-08-04 Added Rebult switches
    [Rebult-JWK-Harimau.ods, Rebult-JWK-Penyu.ods]
2021-08-04 Added Moyu Studio x JWK Queen
    [Moyu-JWK-Queen.ods]
2021-08-05 Added regular Durock T1 and T1 stem in Harimau
    [Durock-T1-stem-in-Harimau-housing.ods, Durock-T1.ods]
2021-08-05 Added note on Dark Amber T1 that it has the "V1" housing
2021-08-05 Fixed some typos, added Rebult Keyboards to donors of switches
2021-08-18 Added various raw graphs
    [C3Equalz-Kiwi.ods, Durock-T1-stem-in-Harimau-housing-T1-comparison.ods, Feker-Smoky-Tactile-Stem-In-T1-Housing.ods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]
2021-08-22 Added feature to re-measure in case of HX711 error
    [Switch-tester-firmware.ino]
2021-08-22 Added large number of switches Dangkeebs sent me
    [Durock-Shrimp.ods, Gateron-Silver-Blizzard.ods, Gateron-Slate.ods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]
2021-08-22 Added various frankenswitches
    [Feker-Smoky-Tactile-Stem-In-T1-Housing.ods, NK-Blueberry-stem-in-Tecsee-Lychee.ods]
2021-08-22 Added a bunch of frankenswitches
    [Durock-Cobalt-Stem-In-POM-Housing.ods, Tecsee-Blue-Velvet-Stem-In-JWK-Lavender.ods, Tecsee-Blue-Velvet-Stem-MS1-Top-Mode-Reflex-Bottom.ods]
2021-08-22 Updated README with new switch measurements
2021-08-24 Added 2 switches
    [C3Equalz-Kiwi.ods, JWK-Moyu-Poseidon.ods]
2021-08-24 Forgot to post updated ODS
    [Durock-Cobalt-Stem-In-POM-Housing.ods, Tecsee-Blue-Velvet-Stem-In-JWK-Lavender.ods, Tecsee-Blue-Velvet-Stem-MS1-Top-Mode-Reflex-Bottom.ods]
2021-08-24 Renamed file names to Moyu-JWK-Poseidon
    [Moyu-JWK-Poseidon.ods]
2024-04-18 Updated to KiCAD 8
2024-04-18 Made Arduino Nano variant of the main board
    [Main-board-ArduinoNano-B_Cu.gbr, Main-board-ArduinoNano-B_Fab.gbr, Main-board-ArduinoNano-B_Mask.gbr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]
2024-04-18 Forgot to plot reference designators
    [Main-board-ArduinoNano-B_Cu.gbr, Main-board-ArduinoNano-B_Fab.gbr, Main-board-ArduinoNano-B_Mask.gbr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]
2024-04-20 More work; organization
    [ADC-PCB-spacer.stl, Baseplate-stand.dxf, HFS5-2020-132-TPW.stp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]
2025-10-15 Some reorganization
    [Blank-template-automated.ods, calibration.xlsx]
2025-10-15 Measured Cherry MX Purple
    [Cherry-MX-Purple-RGB-1.ods, Cherry-MX-Purple-RGB-2.ods]
2025-10-15 Clarified Cherry MX Purple is MX2A
    [Cherry-MX-Purple-RGB-MX2A.ods]
2025-10-15 Add Futaba MA-41
    [Futaba-MA-41-Cherry-mount.ods]
2025-10-18 Added a protection bracket for the load cell
2025-10-29 Added Gateron Melodic
    [Gateron-Melodic.ods]
2025-11-27 Minor PCB fixes
    Changed Start_switch pin to A0, as D13 (original assignment) cannot be set to INPUT_PULLUP
    [Main-board-ArduinoNano-B_Cu.gbr, Main-board-ArduinoNano-B_Fab.gbr, Main-board-ArduinoNano-B_Mask.gbr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]
2025-12-06 Fixed silkscreen, connected J5 on PCB
    [Main-board-ArduinoNano-B_Cu.gbr, Main-board-ArduinoNano-B_Fab.gbr, Main-board-ArduinoNano-B_Mask.gbr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]
2025-12-06 Replaced Misumi HFS5 CAD models with ones done from scratch
2025-12-15 Some work on the CAD file
    [load-cell-protection-bracket.stp]
2026-01-05 Generally update CAD model
    [4884 Feather RP2040.step, ADC-board-HX711.step, Baseplate-frame-1.dxf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]
2026-01-06 Rename folder
    [ADC-board-HX711.step, M3-hex-nut-DIN-934.step, M5x8-ISO-7380-screw.step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]
2026-01-06 Move folder
    [ADC-board-HX711.step, M3-hex-nut-DIN-934.step, M5x8-ISO-7380-screw.step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]
2026-01-06 Move file
    [Force-curve-meter-Gen2.stp]
2026-01-06 Updated STLs
    [ADC-PCB-spacer.stl, load-cell-protection-bracket.stl, load-cell-protection-bracket.stp]
2026-01-06 Slotted linear stage mounting holes on Vertical-plate to allow compatibility for other linear stages
    [Force-curve-meter-Gen2.stp, vertical-plate.dxf]
2026-01-06 Added STEP files
    [Baseplate-stand.stp, Load-cell-mounting-plate.stp, Vertical-plate.stp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]
